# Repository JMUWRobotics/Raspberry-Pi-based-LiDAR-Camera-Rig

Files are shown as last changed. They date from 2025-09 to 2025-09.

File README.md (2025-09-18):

# Raspberry Pi–based LiDAR–Camera Rig (Livox MID-70 + Global-Shutter MonoCam)


> Handheld RGB-D scanner for outdoor/indoor scenes — developed as part of my Bachelor’s thesis at the Chair of Robotics (Informatik XVII), Julius-Maximilians-Universität Würzburg.

> The goal is a robust pipeline from ROS recording → synchronized pair export → colored point clouds & depth images → (optional) depth densification → Uni-Fusion-ready outputs.

> **Note:** An IMU is built into the device but is **not calibrated** yet and is therefore not used in the default pipeline.

<p align="center">
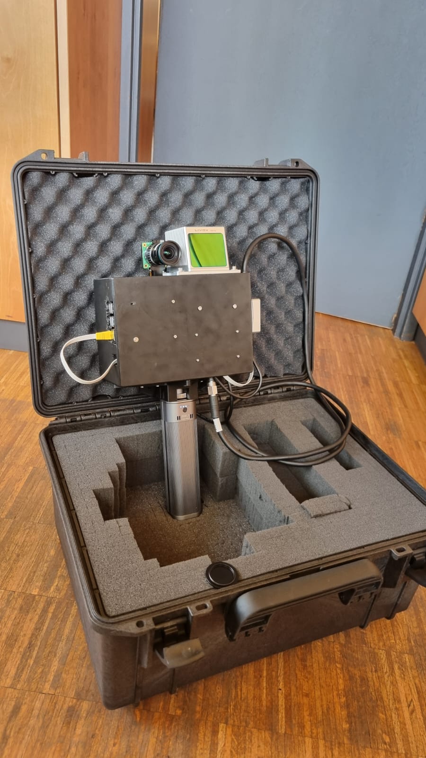
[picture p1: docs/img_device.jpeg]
  
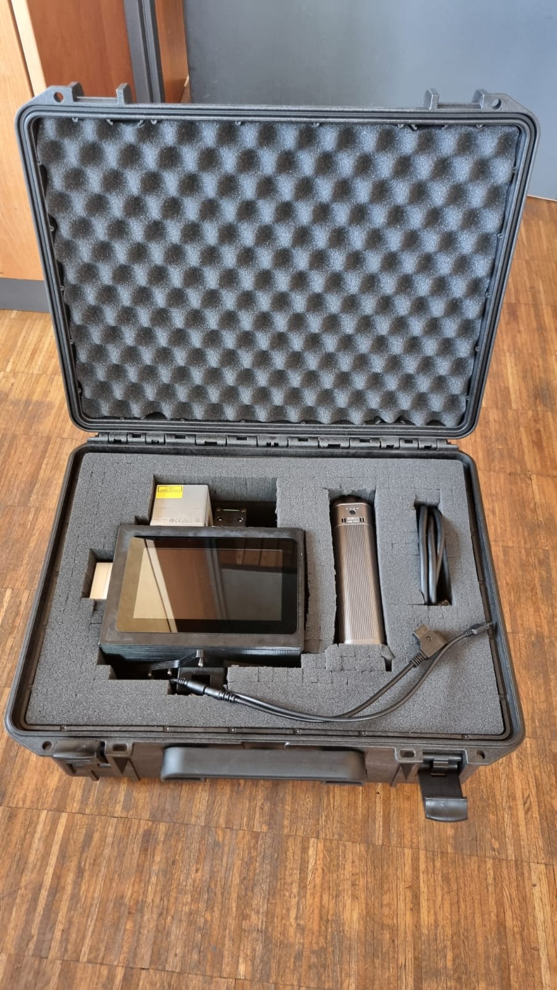
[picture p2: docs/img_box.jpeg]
  
</p>

---

## Features

- **Synchronized RGB + LiDAR pairs** from ROS bags (nearest-time matching with configurable tolerance)
- **RGB-D frames** and **colored point clouds**
- **Depth densification** (optional)
- **ICP** (merge/register multiple scans)
- **Output for Uni-Fusion**-compatible output folder structure (RGB, Depth)

---

## Hardware

- **LiDAR:** Livox MID-70
- **Camera:** Raspberry Pi Global-Shutter MonoCam and IDS-2M12-C0420, 4 mm, 1/2
- **Compute:** Raspberry Pi running **Ubuntu 24.04**
- **IMU:** BNO085, currently **uncalibrated** (not used yet)

> **Link to Fusion360 model:** https://a360.co/4mhiRDJ  
---

## System Architecture
```
Raspberry-Pi-based-LiDAR-Camera-Rig/
├── device/                                         # Ros2 Workspace on handheld device 
│   ├── src/                                        
│   │   ├── bno085                                  # IMU
│   │   ├── camera_ros                              # Raspberry Pi Camera
│   │   ├── FAST-Calib-ROS2                         # extrinsic calibration
│   │   ├── libcamera                               # driver for Pi camera
│   │   ├── livox_ros2_driver                       # driver Livox Mid-70
│   │   └── code_pkg                                # computation of rosbags
│   │          ├──       
│   │          ├──     
│   │          ├──     
│   │          └── 
│   │     
│   └── recording_scripts/                          # automatic setup and capturing of rosbags
│       ├──       
│       ├──     
│       ├──     
│       └──     
│     
├── tools/                                          # Python scripts for post-processing      
│   ├── correct_dataset.py                          # change BGR images to RGB images
│   ├── densify_depth.py                            # bilinear interpolation to fill depth image
│   ├── fuse_scans.py                               # colored pcl via icp
│   ├── generate_Fusion_Output.py                   # generate Uni-Fusion Output 
│   └── show_ply.py                                 # show pointcloud.ply
│                                         
├── stl/                                            # stl-files
│   ├── Bachelor_Device_Global_Shutter v9.f3z       # Fusion file of device
│   ├── BatteryMountingBracket.stl                  
│   ├── Body+BatteryMountingBracket.stl             
│   ├── Body.stl                                    
│   └── Front.stl                                   
│     
├── thesis/                                         # Academic thesis material  
└── README.md
```
## Software Stack & Dependencies post-processing 

- Python ≥ 3.10
- **Open3D** ≥ 0.19
- NumPy, OpenCV-Python, Pillow
- (optional) Matplotlib for visualization
---
Additional sample outputs:
- `docs/images/sample_rgb.png` — camera frame  
- `docs/images/sample_depth.png` — generated (optionally densified) depth image  
- `docs/images/sample_colored_pcd.png` — colored point cloud

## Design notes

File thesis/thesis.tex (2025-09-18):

% !TeX root = bsp.tex

% class options:
% - select either [german] or [english]
% - select the type of thesis from:
%   [bachelor, master, generic]
%   (in case of generic, use \type{} to specify it)
% - use option "alpha" for abbreviated citation (instead of numbers)
% - option "draft" is available, too
% - use options "utf8" or "latin1" to select inputencoding
\documentclass[english, bachelor, utf8]{base/thesis_telematics}

\usepackage{units}    % useful for settings units:              \unit[23]{m}
\usepackage{nicefrac} % for setting fractions esp. within text: \nicefrac{km}{h}
\usepackage{subcaption} % for subfigure environment
\usepackage[utf8]{inputenc}
\usepackage{array} % für bessere Tabellen
\usepackage{geometry}
\geometry{margin=2.5cm}

\usepackage{algorithm, algorithmic}  % for pseudo code (cf. documentation)
\renewcommand{\algorithmiccomment}[1]{\qquad{\small // \textit{#1}}}
\usepackage{tikz}
\usetikzlibrary{arrows.meta, positioning, shapes.geometric, calc}
\usepackage{pdfpages}
\usepackage{hyperref}
\usepackage{booktabs}
\usepackage[utf8]{inputenc}
\usepackage{svg}
\usepackage{subcaption}

%%%%%%%%%%%%%%%%%%%%%%%%%%%%%%%%%%%%%%%%%%%%%%%%%%%%%%%%%%%%%%%%%%%%%%%%%%%%%%%

\begin{document}

\title{Raspberry PI based Camera--LiDAR rig for colored 3D Pointclouds}
\author{Jakob Wehr}
\email{jakob.wehr@stud-mail.uni-wuerzburg.de}
\firstSupervisor{Prof. Dr. Andreas Nuechter}
\secondSupervisor{Dr. Michael Bleier}
\thirdSupervisor{}
%\thirdSupervisor{} %for to give credit to the person supervising but not reviewing the thesis 
%\dept{...}                             % by default Robotics and Telematics
%\submitdate{November 2004}             % by default current month & year
%\signcity{}                            % by default W�rzburg
%signline{W�rzburg, 1. April 2014} % by default "signcity, submitdate"

\generatetitle

\cleardoublepage

\begin{prefacesection}{Abstract}
This Bachelor's thesis presents the design and implementation of a low-cost, handheld \\RGB-D scanning device
built from widely available components -- a Raspberry Pi 5, Raspberry Pi Global shutter camera and a Livox Mid-70
LiDAR -- aimed at producing research-grade datasets for sensor-fusion experiments and Uni-Fusion pipelines
at the same research chair where this work is conducted. The system employs ROS-based recording and a
structured export that tightly couples LiDAR scans and images while ensuring cross-sensor
time synchronization via the Precision Time Protocol (PTP). The processing pipeline generates depth images
and synchronized RGB-D frames for Uni-Fusion, and provides colorized point clouds to inspect extrinsic
calibration. With a bill of materials of $\sim$EUR 1{,}500, the prototype demonstrates a genuinely low-cost
platform suitable for teaching labs and exploratory research. Experiments confirm end-to-end functionality
but also reveal remaining limitations -- most notably imperfect LiDAR-camera extrinsic calibration and an
as-yet uncalibrated external IMU -- while full Uni-Fusion evaluation remains prepared but untested due to
target-system constraints.
\end{prefacesection}

\cleardoublepage
\tableofcontents

\startTextChapters %%%%%%%%%%%%%%%%%%%%%%%%%%%%%%

\chapter{Introduction}

The rapid progress in three-dimensional (3D) sensing technologies has significantly expanded the possibilities 
for spatial data acquisition in diverse domains such as robotics, autonomous navigation, cultural heritage 
documentation and construction monitoring. A key advancement in this context has been the emergence of 
RGB-D imaging, which captures both the color (RGB) and depth (D) information of a scene in a single system. 
By combining semantic richness from visual data with the geometric accuracy of depth measurements, RGB-D 
approaches enable detailed and meaningful 3D reconstructions that are crucial for a wide range of applications.

The popularization of low-cost RGB-D devices, most prominently the Microsoft Kinect, represents a milestone 
in this development. The first generation Kinect employed a PrimeSense structured-light depth sensor, which 
allowed real-time depth estimation but was limited in outdoor environments due to sensitivity to sunlight. 
Later iterations, such as the Kinect v2 and Azure Kinect, shifted to time-of-flight (ToF) sensors, extending 
the maximum measurable range up to approximately 7.5 meters~\cite{3dpclecture}. While this marked a considerable 
improvement over structured-light solutions, the technology continued to face limitations in terms of range, 
accuracy and robustness, particularly in uncontrolled outdoor conditions where strong ambient illumination 
interferes with infrared-based measurements.

To overcome such restrictions, several alternatives have been explored in recent years. One approach relies 
on the use of multiple cameras to generate dense reconstructions through photogrammetric methods. By leveraging 
multi-view geometry and at least one RGB sensor for color encoding, photogrammetry can provide accurate depth 
over larger distances, but at the expense of high computational requirements and sensitivity to textureless 
surfaces. Another method combines RGB cameras with structured infrared patterns and inertial measurement units, 
as seen in devices such as the Intel RealSense D455. Although effective in indoor environments, these systems 
remain vulnerable to degradation in bright outdoor light. A third and increasingly promising avenue is the 
integration of RGB cameras with LiDAR sensors. LiDAR, by actively emitting laser pulses and measuring their 
returns, offers high robustness to illumination conditions and can capture accurate depth across larger ranges. 
The falling costs of compact LiDAR units have further strengthened their appeal for mobile and handheld 
applications.

The objective of this thesis is to design and implement a handheld device that employs an RGB camera in 
combination with a low-cost Livox LiDAR scanner to achieve reliable outdoor depth sensing. This system aims 
to circumvent the weaknesses of structured-light or infrared-based methods under sunlight, while leveraging 
the complementary strengths of LiDAR and RGB imaging. The handheld design not only emphasizes portability 
and ease of use, but also opens opportunities for rapid on-site 3D data acquisition without the constraints 
of bulky equipment.

Recent research has demonstrated the potential of combining LiDAR with vision sensors for dense depth map 
generation in outdoor environments. A notable contribution in this area is the work by Bleier, Yuan and 
Nüchter~\cite{bleier2024}, who introduced a handheld stereo vision and LiDAR system capable of producing dense 
RGB-D maps by applying depth map completion based on learned priors. Their system exploits stereo cameras to 
capture visual data and a low-cost automotive LiDAR to supply sparse but metrically accurate depth information. 
By applying deep learning techniques to complete the sparse LiDAR data, they were able to generate dense depth 
maps with both accuracy and efficiency, even in challenging outdoor settings. This work provides an important 
methodological reference and demonstrates that the combination of vision and LiDAR, supported by learned priors, 
can significantly enhance the quality of handheld 3D mapping systems.

Further contributions in the literature similarly explore handheld systems that fuse monocular 
vision with LiDAR, each addressing specific challenges.

One influential study by Behari et al. at CVPR 2025~\cite{behari2025blurred} introduces a handheld setup that 
combines RGB imaging with a diffuse (blurred) LiDAR sensor. While conventional sparse 
LiDARs often fail to cover the entire scene, the diffuse LiDAR emits a wide-field flash, improving 
coverage but producing ambiguous multi-return signals. To address this, the authors propose a 
Gaussian surfel-based rendering framework together with a scene-adaptive loss, 
which balances the geometric accuracy of LiDAR with the semantic richness of RGB cues. This method 
enables robust handheld 3D scanning even in challenging environments with low texture, low albedo
or limited lighting, thereby outperforming traditional sparse LiDAR approaches.

Another notable contribution is presented by Lin et al.~\cite{lin2024lidarmirror}, who focused on 
mapping specular and transparent surfaces using a consumer-grade flash LiDAR integrated 
into a handheld smartphone device. Standard LiDAR systems typically assume single-bounce 
reflections, which leads to missing data when scanning mirrors or glass. To overcome this, the 
authors introduced a reciprocal pair algorithm that explicitly detects and reconstructs 
multi-bounce returns. Their approach enables accurate, real-time handheld reconstructions of 
reflective and transparent objects, extending the applicability of low-cost LiDAR sensors.

In addition to novel sensing concepts, the Newer College Dataset by Ramezani et al.
~\cite{ramezani2019newer} provides a valuable benchmark for handheld mapping. The dataset was 
recorded with a handheld device combining a stereo-inertial camera and a multi-beam 3D LiDAR while 
walking through a university campus. By aligning this data with a survey-grade reference map, the 
authors provide centimeter-accurate 6-DoF ground truth. This resource is essential for evaluating 
the performance of handheld LiDAR--vision fusion systems and highlights the practical challenges of 
sensor alignment and outdoor robustness.

These studies emphasize three central aspects: addressing sparse LiDAR coverage through novel sensor 
designs (Behari et al.), handling challenging material properties such as reflections and 
transparency (Lin et al.) and enabling reproducible evaluation through high-quality handheld 
datasets (Ramezani et al.). Together, they strengthen the evidence for the relevance of combining 
LiDAR and monocular vision in mobile or handheld 3D reconstruction systems.

Against this backdrop, the present thesis contributes to the field by developing a prototype low-cost handheld device 
that integrates a Livox LiDAR scanner with an RGB camera. The design encompasses both the hardware construction 
and the software implementation required for sensor synchronization, calibration and generating RGB-D frames
as input to the Uni-Fusion framework proposed by Yuan et al.~\cite{yuan2024uni}.

\section*{Task definition}
This thesis focuses on the design and implementation of a low-cost, handheld RGB-D scanning device using
widely available components, specifically a Raspberry Pi~5 (16GB) as the processing platform, a Raspberry Pi camera
module for RGB image capture and a Livox Mid-70 LiDAR scanner for depth acquisition. The primary goal is to
develop a portable system capable of producing RGB-D datasets suitable for sensor fusion experiments -- particularly Uni--Fusion -- without relying on expensive commercial solutions.

The research addresses the complete pipeline: from hardware integration and calibration of the monocular
camera--LiDAR system, through data acquisition, to post-processing and alignment of RGB
and depth streams. Special attention is given to cost-efficiency, portability, and the reproducibility of the system
design, so that it can be easily replicated and is also affordable for amateurs.

In summary, the aim of this work is to:
\begin{itemize}
    \item Design and build a handheld, low-cost RGB-D device using a Raspberry Pi~5, monocular camera and
    Livox Mid-70 LiDAR scanner.
    \item Implement a calibration and synchronization method for accurate data acquisition.
    \item Designing a system that can process the recorded data and create dense depth images.
    \item Creating output that can be processed by Uni-Fusion.
    \item Demonstrate that the system fulfills its purpose and that Uni-Fusion can process the generated RGB-D files.
\end{itemize}

By achieving these objectives, this work should make it easier for tech enthusiasts to get started with handheld devices, LiDAR scanners
and processing RBG-D data, thanks to the low price of the complete system.

\chapter{State of the Art}

\section*{Handheld stereo vision and LiDAR system (University Wuerzburg Computer Science XVII)}
Bleier et al.~\cite{bleier2024} present a custom-built handheld mapping system designed to 
capture dense RGB-D data in outdoor environments using low-cost sensors. The hardware integrates 
a stereo camera pair and a low-cost automotive LiDAR (specifically, a Livox Avia sensor) mounted on a 
commercial camera rig (e.g., NEEWER CA016 Cage, Figure~\ref{fig:bleier_handheld_design}). The system 
also houses embedded electronics including a single-board computer, power management, cooling 
elements, and features a handle and Wi-Fi antenna for operation and data transfer.

The core innovation resides in combining sparse LiDAR measurements with monocular RGB-based depth 
estimation to generate dense, metrically accurate RGB-D frames with low latency. To that end, they 
employ a modern monocular depth estimator (Metric3Dv2, Hu et al., 2024) and subsequently apply learned 
scale correction using sparse LiDAR returns as ground truth priors. This enables the generation of 
dense depth maps from just one sparse scan and a single image, circumventing the need for multi-view 
bundle adjustment or LiDAR scan aggregation.

For validation, the authors compare the learning-based depth completion to traditional LiDAR-only 
mapping via scan matching. While the baseline model-based regression performs worse in their experiments, 
it still achieves dense RGB-D outputs from minimal sensor input with significantly lower latency, 
demonstrating potential for real-time outdoor RGB-D capture using cost-effective hardware.

\begin{figure}[htbp]
    \centering
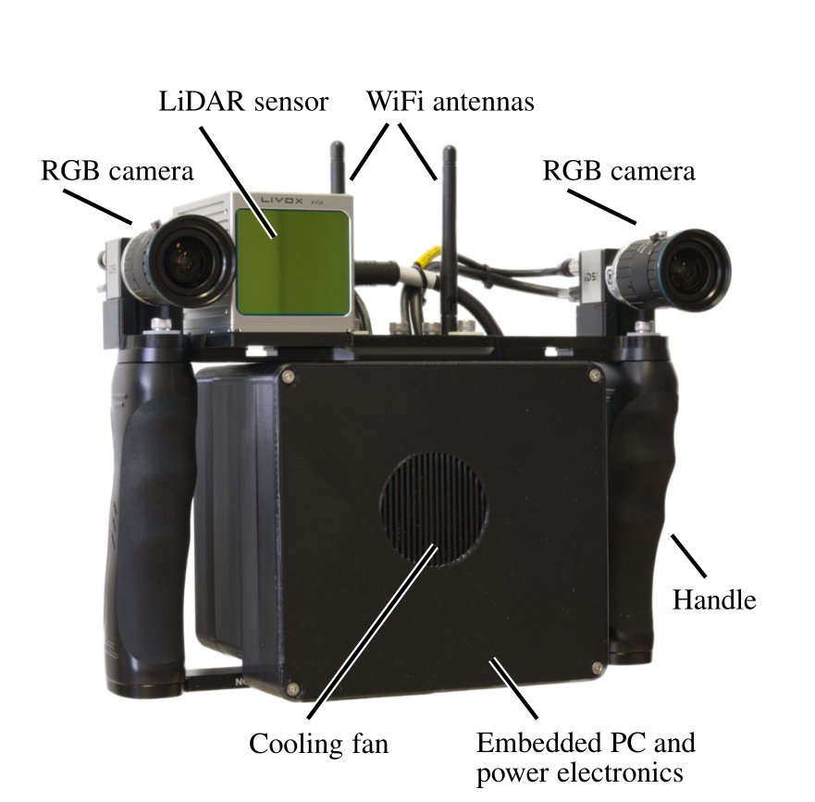
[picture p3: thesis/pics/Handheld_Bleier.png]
    
    \caption{Handheld stereo vision--LiDAR mapping system featuring stereo cameras, 
    Livox Avia LiDAR, embedded PC, handle and Wi-Fi antenna on a commercial cage rig by Bleier et al.~\cite{bleier2024}}
    \label{fig:bleier_handheld_design}
\end{figure}

\chapter{Theoretical Background}

\section{LiDAR Scanning}
Lidar (Light Detection and Ranging) is a remote sensing technology that measures distances by emitting laser
pulses and recording the time it takes for the reflected signal to return. This time-of-flight measurement
allows precise determination of the distance to an object. Compared to radar, Lidar uses shorter wavelengths,
which makes it more effective for detecting smaller targets. By scanning surfaces, Lidar can also determine
the shape and size of objects, making it highly suitable for terrain modeling and object recognition.
\subsection*{Differential Absorption Lidar (DIAL)}
Differential Absorption Lidar (DIAL) measures atmospheric properties such as temperature, density and
pressure of trace gases and aerosols. It uses two laser beams: one with a wavelength corresponding to the
absorption peak of the target gas (on-line) and another between absorption features (off-line). The ratio
of the returned on-line and off-line signals provides information about the absorption characteristics of
the target gas.
\subsection*{Doppler LiDAR}
Doppler Lidar measures the velocity of targets using the Doppler shift of the reflected light. By mixing
the return signal with a reference laser of known frequency (heterodyne detection), the Doppler frequency
shift can be determined. Applications include wind speed and direction measurements, detection of turbulence
and wake vortices near airports, monitoring local winds during rocket or shuttle launches and providing
data for accurate weather prediction models.

\subsection*{Distance Measurement}
The distance measurement in Lidar follows \( d = \frac{c \cdot t}{2} \), where \(c\) is the speed of light
in vacuum (approximately 299,792,458 m/s) and \(t\) is the pulse time-of-flight. Achieving a resolution of
10 mm requires timing precision on the order of picoseconds (\(10^{-12}\) s). Unlike radar, which emits
diverging signals, Lidar beams are focused. This ensures high accuracy but makes the system sensitive to
fog, rain, wind and reflective or transparent surfaces such as glass or water.

Laser scanners produce raw data that depend on angular resolution (typically 0.25°–1°) and field of view
(commonly 180°, some sensors up to 360°). Raw data generally consist of angle and distance measurements,
optionally including reflectance or intensity. These polar coordinates can be converted to Cartesian
coordinates for further processing and analysis.~\cite{michaelbleier_slides}

\section{PLA -- polylactic acid}
\label{sec:PLA}

PLA, alongside ABS, is one of the most commonly used materials in FDM printers. 
These polylactides are synthetic polymers that belong to the polyester family and are made up of many chemically bonded 
lactic acid molecules. PLA is made from renewable raw materials such as corn starch and is industrially compostable. 

PLA is the material of choice, especially for beginners in 3D printing, as it is forgiving of many printing errors 
and has many other advantages. For example, it can be easily processed by any standard 3D printer, has a low melting 
point and exhibits minimal warping during printing. Furthermore, it is colorfast and scratch-resistant and, unlike ABS, 
produces little odor during processing.~\cite{material4print2024pla}

%\section{\textcolor{red}{IMU -- Inertial Measurment Unit}}

\section{Intrinsic Camera Calibration}
The characteristics of a camera can basically be divided into intrinsic and extrinsic parameters.
Intrinsic calibration captures the camera's internal physical characteristics, such as focal length,
 optical axis, and lens distortion.
Extrinsic calibration, on the other hand, determines the spatial position and orientation of the camera 
relative to a defined world coordinate system.

Intrinsic camera calibration aims to estimate the internal parameters of a camera that model the image 
formation process and lens distortions. According to Fusiello~\cite{Fusiello2024}, this includes focal 
lengths, the principal point and parameters describing lens-induced distortions.

\subsection*{Camera Model}
In the pinhole camera model, a 3D point $\mathbf{X} = [X, Y, Z]^\top$ is projected onto the image 
plane as:
\[
s \begin{bmatrix} u \\ v \\ 1 \end{bmatrix}
= \mathbf{K} \, [\mathbf{I} \mid \mathbf{0}] \,
\begin{bmatrix} X \\ Y \\ Z \\ 1 \end{bmatrix}.
\]
The intrinsic matrix $\mathbf{K}$ is defined as:
\[
\mathbf{K} = 
\begin{bmatrix}
f_x & s & c_x \\
0 & f_y & c_y \\
0 & 0 & 1
\end{bmatrix},
\]
where $f_x$ and $f_y$ are the focal lengths in pixels, $(c_x, c_y)$ is the principal point, and 
$s$ is the skew factor, often assumed to be zero in most practical systems.

\subsection*{Distortion Model}
Real lenses introduce \emph{radial} and \emph{tangential} distortions. A common distortion model with 
radial coefficients $k_1, k_2, k_3$ and tangential coefficients $p_1, p_2$ is:
\[
r^2 = x^2 + y^2,
\]
\[
x_{\mathrm{dist}} = x \left( 1 + k_1 r^2 + k_2 r^4 + k_3 r^6 \right) + 2 p_1 x y + p_2 (r^2 + 2 x^2),
\]
\[
y_{\mathrm{dist}} = y \left( 1 + k_1 r^2 + k_2 r^4 + k_3 r^6 \right) + p_1 (r^2 + 2 y^2) + 2 p_2 x y.
\]
The distorted normalized coordinates $(x_{\mathrm{dist}}, y_{\mathrm{dist}})$ are then mapped to pixel 
coordinates using $\mathbf{K}$.

\subsection*{Calibration Workflow}
Fusiello describes a typical calibration pipeline as follows:
\begin{enumerate}
    \item Capture multiple images (10--20) of a planar calibration target (e.g., checkerboard) from 
          different positions and orientations.
    \item Detect known 2D feature points in the images and associate them with their known 3D coordinates 
          in the target's frame.
    \item Compute an initial estimate of the intrinsic parameters using linear methods (e.g., via 
          homography decomposition).
    \item Refine all intrinsic parameters and distortion coefficients by nonlinear optimization (e.g., 
          Levenberg--Marquardt) to minimize the reprojection error.
\end{enumerate}

\begin{figure}[ht!]
    \centering
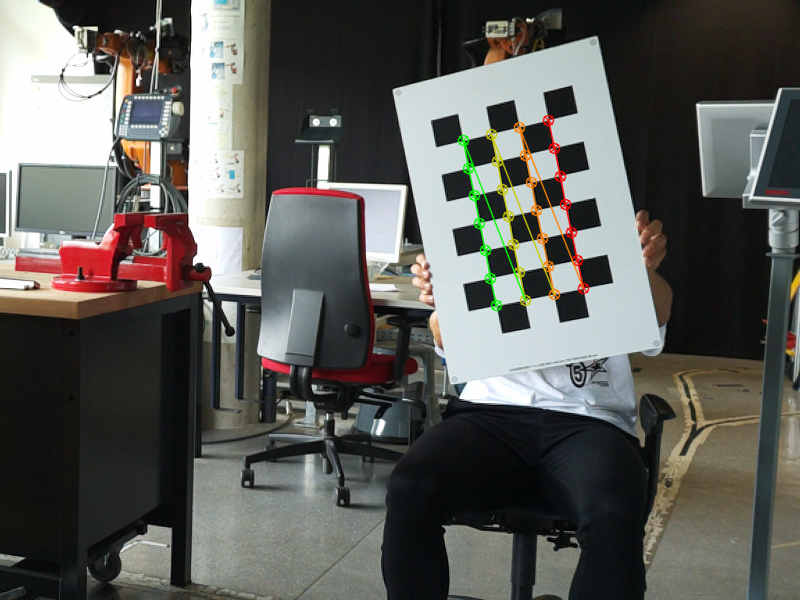
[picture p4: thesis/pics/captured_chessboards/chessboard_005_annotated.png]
    
    \caption{Example calibration pattern with found corners}
    \label{fig:pattern}   
\end{figure}

%\paragraph{Summary}
%Intrinsic calibration is a fundamental prerequisite for accurate 3D reconstruction and multi-sensor 
%fusion. By estimating the true internal parameters of the camera and compensating for lens distortions, 
%it ensures that image measurements correspond correctly to geometric rays in 3D space.

\section{Extrinsic Calibration of LiDAR and Camera}
\label{sec:extrinsic_calib}

In multi-sensor perception systems that combine LiDAR and camera data, the accurate estimation of the spatial 
relationship between the two sensors is fundamental for enabling sensor fusion. This relationship is described 
by a rigid-body transformation that maps coordinates from the LiDAR reference frame into the camera reference frame. 
If this transformation is incorrect, the projected LiDAR points will not align with the corresponding image features, 
leading to degraded performance in tasks such as 3D reconstruction, object detection or semantic segmentation. 
Extrinsic calibration aims to estimate this transformation with high precision. The approach described in~\cite{beltran2022automatic} 
achieves this in a fully automated manner, without the need for dedicated calibration targets, making it applicable in a wide variety 
of real-world scenarios.

Formally, let $\mathcal{L}$ denote the LiDAR coordinate frame and $\mathcal{C}$ the camera coordinate frame. 
The calibration problem consists of finding the homogeneous transformation matrix $\mathbf{T}_{\mathcal{CL}} \in SE(3)$ that maps a 
point $\mathbf{p}_L$ expressed in LiDAR coordinates to its representation $\mathbf{p}_C$ in the camera coordinate system:
\begin{equation}
\mathbf{p}_C =
\mathbf{T}_{\mathcal{CL}} \, \mathbf{p}_L
= \begin{bmatrix} \mathbf{R} & \mathbf{t} \\ \mathbf{0}^\top & 1 \end{bmatrix} \mathbf{p}_L,
\label{eq:extrinsic_transformation}
\end{equation}
where $\mathbf{R} \in SO(3)$ is a rotation matrix and $\mathbf{t} \in \mathbb{R}^3$ is a translation vector. 
This transformation describes both the orientation and the position of the LiDAR relative to the camera. 
The points $\mathbf{p}_L$ are represented in homogeneous coordinates, enabling both rotation and translation to be applied in a single 
matrix multiplication.

Once a LiDAR point has been transformed into the camera coordinate frame, it is projected into the image plane using the calibrated pinhole camera model. 
This projection is given by:
\begin{equation}
\mathbf{u} \sim \mathbf{K} \, [\mathbf{R} \;|\; \mathbf{t}] \, \mathbf{p}_L,
\label{eq:projection}
\end{equation}
where $\mathbf{K}$ is the intrinsic camera matrix containing focal lengths, the principal point, and skew parameters, and $\mathbf{u} = [u, v, 1]^\top$ are 
the homogeneous image coordinates. The operator $\sim$ indicates equality up to a scale factor due to the use of homogeneous coordinates. Accurate knowledge 
of $\mathbf{K}$ is assumed, as intrinsic calibration is typically performed separately beforehand.

The extrinsic calibration problem can then be formulated as an optimization that minimizes the discrepancy between the observed image features and the 
projections of the corresponding LiDAR points. This is expressed as the minimization of the total reprojection error:
\begin{equation}
E(\mathbf{R}, \mathbf{t}) =
\sum_{i=1}^N \left\| \mathbf{u}_i -
\pi\left( \mathbf{R} \mathbf{p}_{L,i} + \mathbf{t} \right) \right\|^2,
\label{eq:reprojection_error}
\end{equation}
where $\pi(\cdot)$ is the projection function defined in Equation~\ref{eq:projection}, $\mathbf{u}_i$ are observed feature points in the image, and $\mathbf{p}_{L,i}$ 
are the corresponding 3D points from the LiDAR point cloud. The summation is performed over $N$ matched feature correspondences. By minimizing $E$, the algorithm ensures 
that the transformed and projected LiDAR points align as closely as possible with the observed image features.

The automated calibration procedure proceeds through several interconnected stages, each of which plays a crucial role in the accuracy and robustness of the final result. 
The first stage consists of data acquisition. The system records synchronized LiDAR point clouds and camera images from a variety of viewpoints within the target environment. 
Multiple poses and viewing angles are necessary to provide the optimization with a rich set of correspondences and to reduce
degeneracy in the solution, particularly in geometrically uniform scenes.
The second stage is feature extraction. In the image domain, this often involves detecting salient structures such as edges, corners or line segments that are stable 
under viewpoint changes and can be reliably localized. In the LiDAR domain, geometric primitives such as planes, sharp edges or high-intensity reflectors are extracted 
from the 3D point cloud. These features should ideally correspond to physical elements in the scene that are visible to both sensors, such as building edges, traffic signs
or corners of large objects.

The third stage is feature association. This is a challenging problem because LiDAR and camera sensors capture different modalities: LiDAR measures geometry and sometimes 
reflectivity, while cameras measure color and intensity. To establish correspondences, the algorithm projects candidate LiDAR features into the image using a tentative 
transformation and searches for spatially consistent matches with the extracted image features. Similarity measures can be based on geometric alignment, intensity patterns 
or mutual visibility constraints. At this point, only approximate correspondences are needed, as they will be refined later.

Once a sufficient set of correspondences is established, the fourth stage computes an initial estimate of the transformation $\mathbf{T}_{\mathcal{CL}}$. 
If direct 3D -- 3D correspondences between LiDAR and camera coordinate frames are available -- such as from triangulated stereo image points -- this estimate can be obtained in 
closed form using the Kabsch algorithm, which minimizes the root-mean-square distance between matched point sets. If only 3D–2D correspondences are available, 
a Perspective-n-Point (PnP) algorithm can be employed to obtain an initial rotation and translation.

The fifth stage refines the transformation through nonlinear optimization. Here, the initial $(\mathbf{R}, \mathbf{t})$ is used as a starting point for minimizing the 
reprojection error defined in Equation~\ref{eq:reprojection_error}. The optimization is typically carried out using the Levenberg–Marquardt algorithm, which is well 
suited for nonlinear least-squares problems. Robust loss functions, such as the Huber or Cauchy loss, are integrated into the cost function to reduce the influence of 
outlier correspondences that could arise from incorrect feature matches or transient objects in the scene.

Finally, the sixth stage is validation. The estimated transformation is applied to the LiDAR point cloud, and the points are projected into the corresponding camera image. 
Visual inspection can reveal any systematic misalignment, while quantitative measures such as the mean or median reprojection error provide objective performance metrics. 
Figures~\ref{fig:steps}, \ref{fig:detect_extrinsic_calib} and \ref{fig:reprojection} illustrate the calibration pipeline, the involved coordinate frames and an example of a calibrated projection.

This fully automated pipeline offers several advantages. By eliminating the need for artificial calibration targets, it can be executed in natural, dynamic environments 
without disrupting regular operation. Its reliance on common scene features rather than engineered markers makes it flexible across domains, from autonomous driving and 
mobile robotics to large-scale 3D mapping. At the same time, the combination of an initial analytical estimate with a robust nonlinear refinement ensures both convergence 
reliability and high final accuracy.

\begin{figure}[htbp]
    \centering
    % Erste Reihe
    \begin{subfigure}[b]{0.45\textwidth}
        \centering
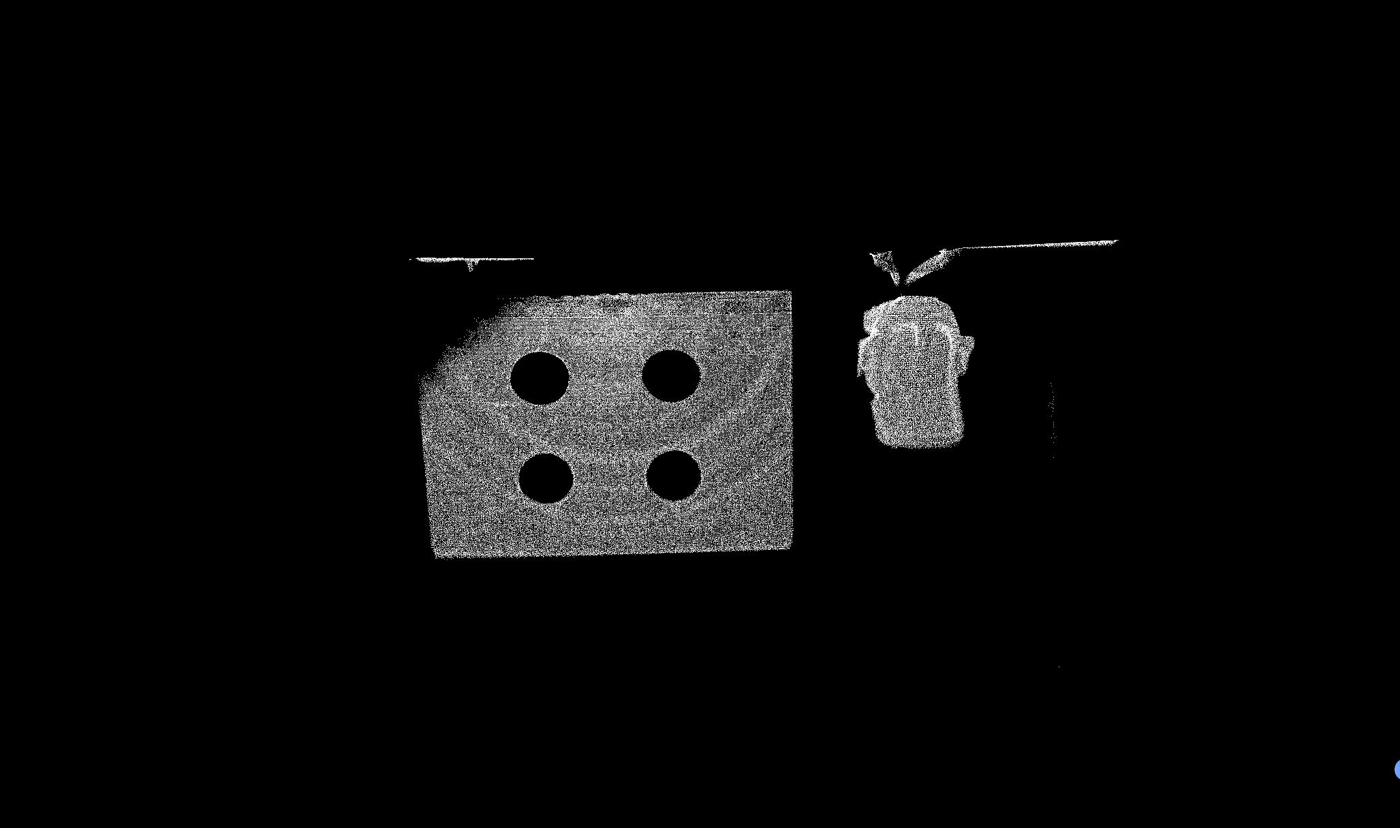
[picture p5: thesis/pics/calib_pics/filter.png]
        
        \caption{Step 1: Distance Filtering}
    \end{subfigure}
    \hfill
    \begin{subfigure}[b]{0.45\textwidth}
        \centering
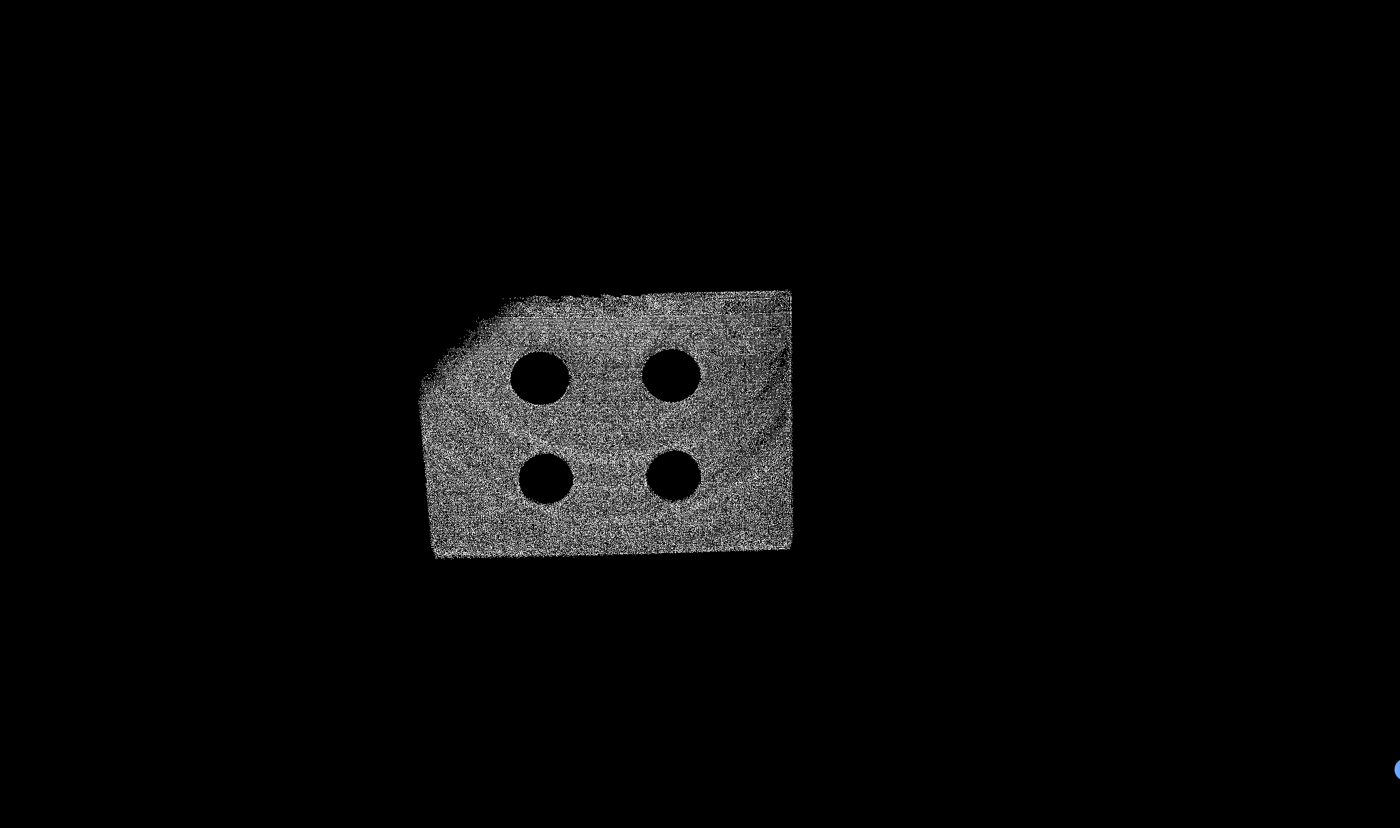
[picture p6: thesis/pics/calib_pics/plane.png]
        
        \caption{Step 2: Plane Segmentation}
    \end{subfigure}

    % Zweite Reihe
    \begin{subfigure}[b]{0.45\textwidth}
        \centering
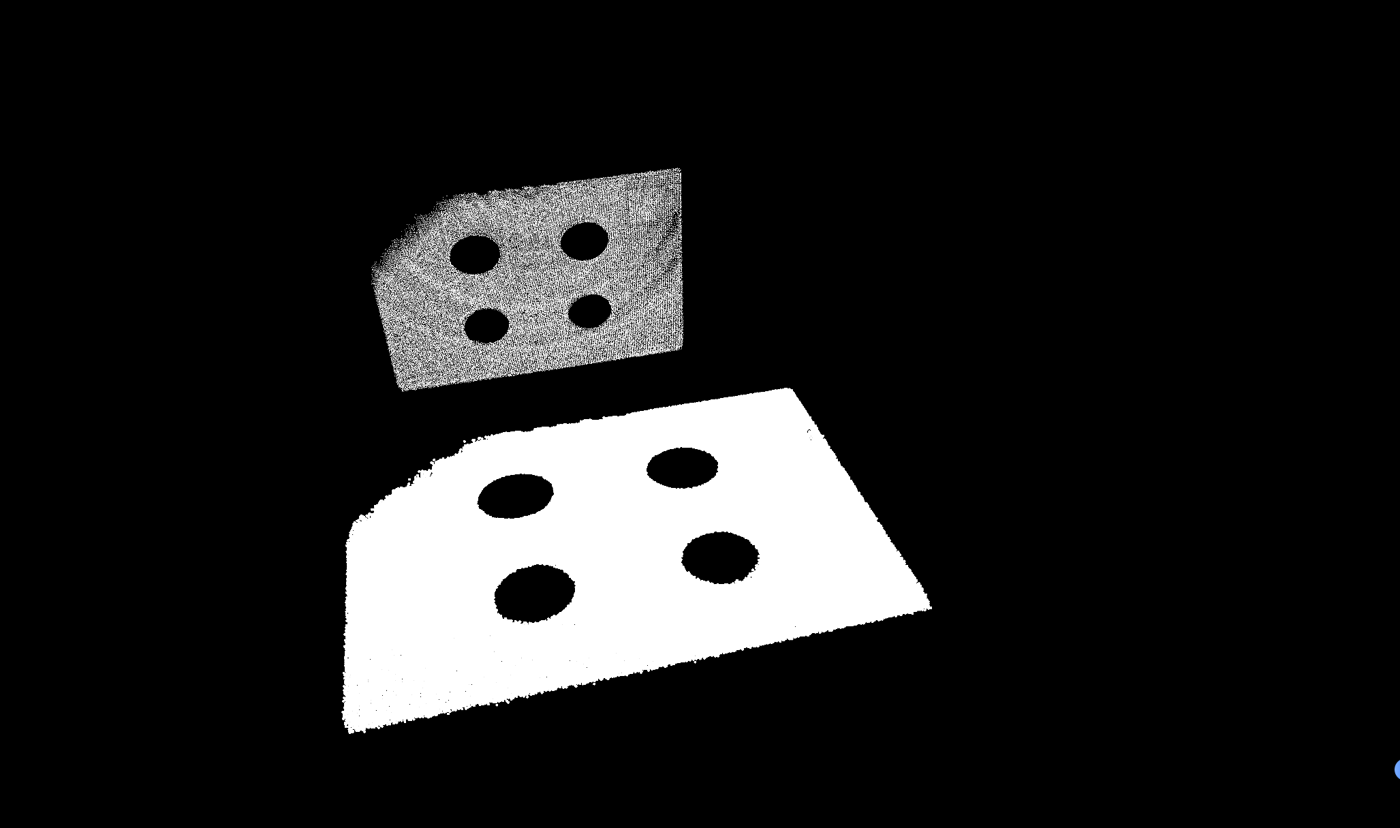
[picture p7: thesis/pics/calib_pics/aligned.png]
        
        \caption{Step 3: Plane Alignment to 2D}
    \end{subfigure}
    \hfill
    \begin{subfigure}[b]{0.45\textwidth}
        \centering
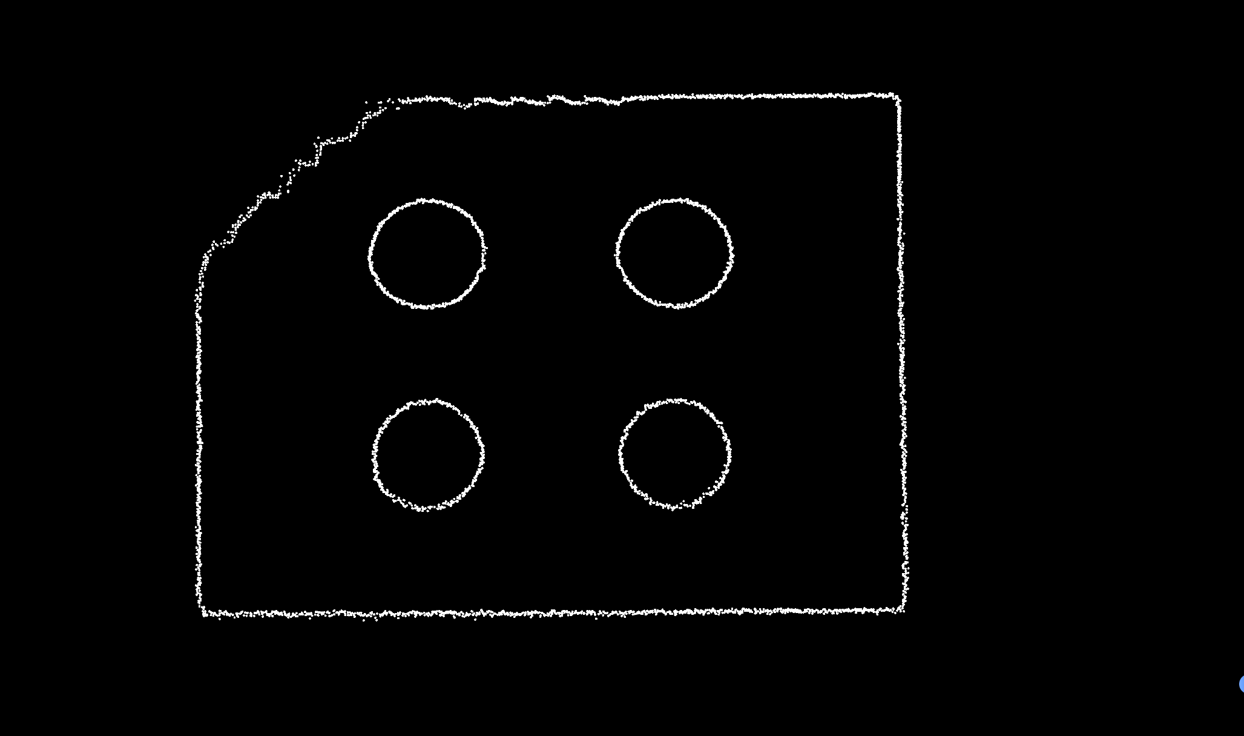
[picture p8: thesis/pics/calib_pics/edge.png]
        
        \caption{Step 4: Boundary Point Detection}
    \end{subfigure}

    % Dritte Reihe
    \begin{subfigure}[b]{0.45\textwidth}
        \centering
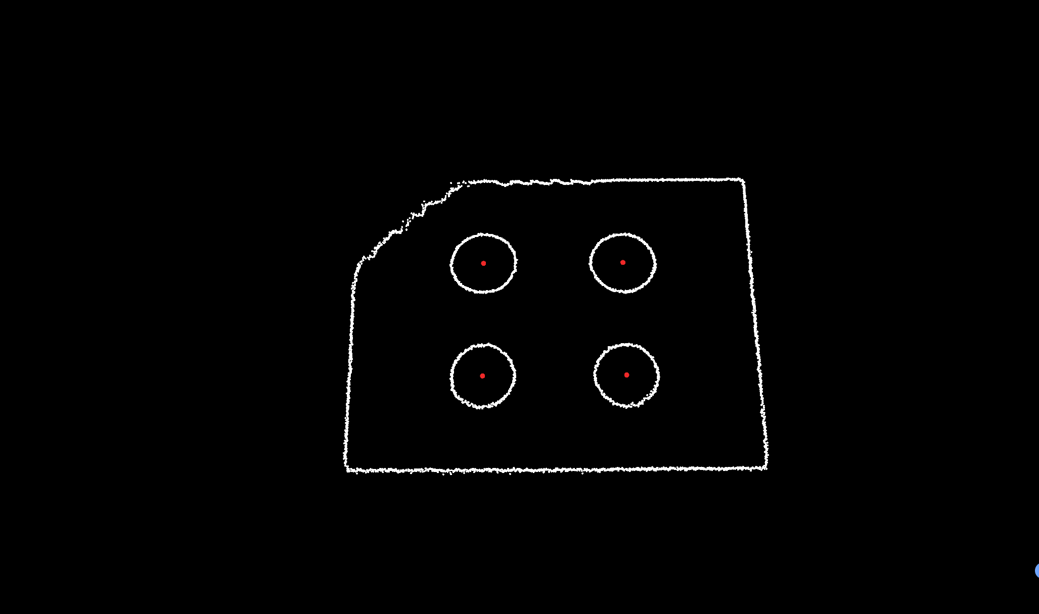
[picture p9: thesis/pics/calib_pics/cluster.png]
        
        \caption{Step 5: Clustering and Circle Fitting}
    \end{subfigure}
    \hfill
    \begin{subfigure}[b]{0.45\textwidth}
        \centering
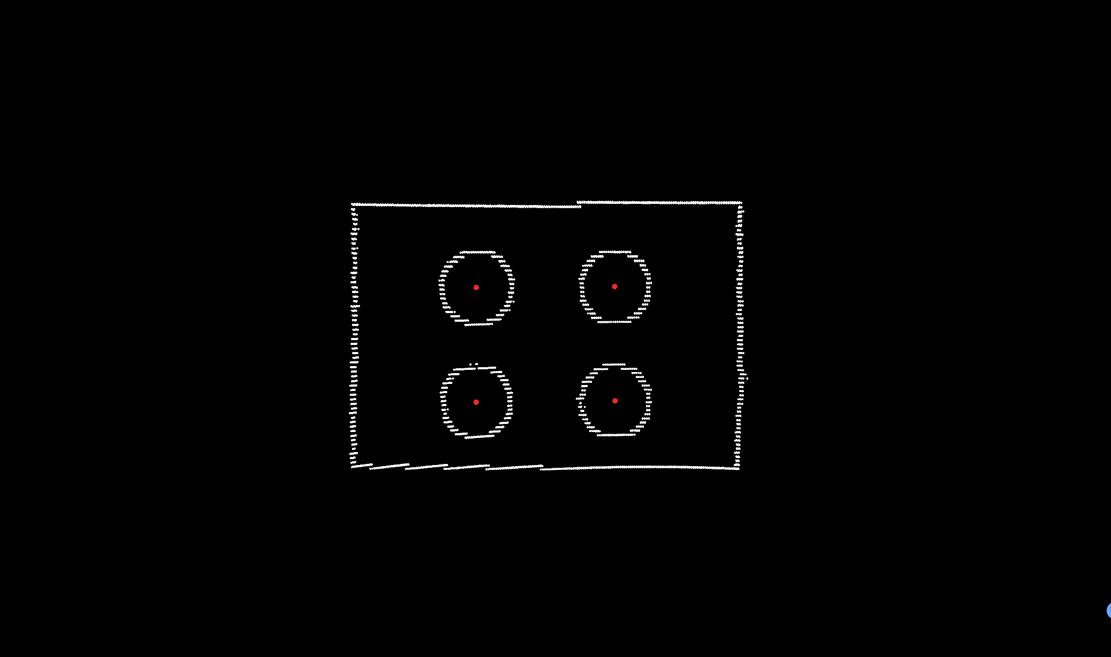
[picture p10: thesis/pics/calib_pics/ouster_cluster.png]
        
        \caption{Step 6: Performance of LiDAR}
    \end{subfigure}

    \caption{LiDAR--camera extrinsic calibration pipeline\cite{FASTCalibROS2}}
    \label{fig:steps}
\end{figure}

\begin{figure}[ht!]
    \centering
    %coordinate_frames.png
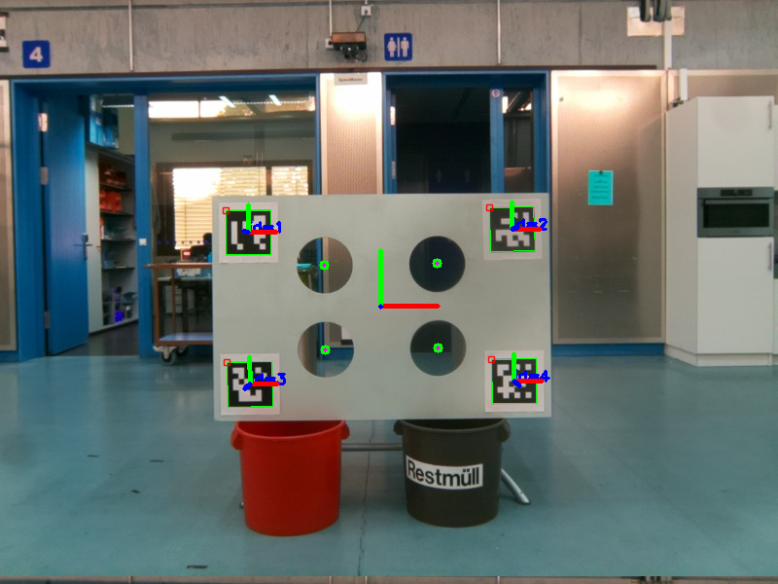
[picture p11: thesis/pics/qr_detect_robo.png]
    
    \caption{Detected calibration pattern}
    \label{fig:detect_extrinsic_calib}
\end{figure}

\begin{figure}[ht!]
    \centering
    %reprojection_example.png
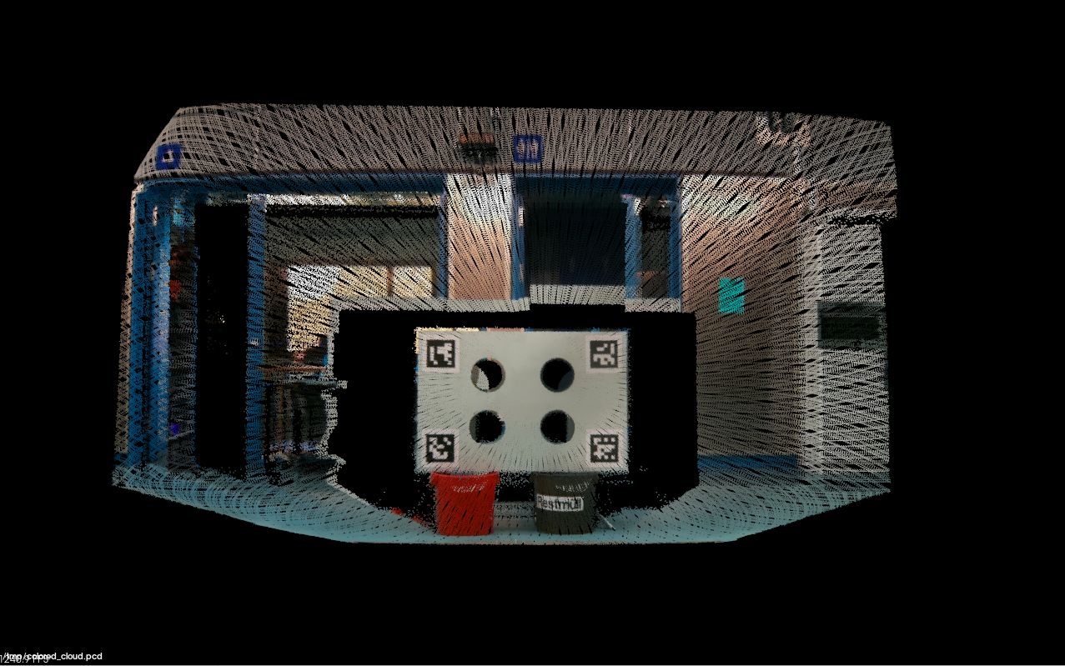
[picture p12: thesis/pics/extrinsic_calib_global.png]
    
    \caption{Colored pointcloud of FastCalib}
    \label{fig:reprojection}
\end{figure}

\section{Synchronize timestamps}
\label{sec:PTP}
In order to correlate the different sensor data from LiDAR, camera and IMU,
i.e., which scan matches which image and what the position was at that time,
we need to synchronize the sensor systems in terms of time.
We use PTP to enable this time synchronization.

The Precision Time Protocol (PTP) according to IEEE~1588 is used for high-precision
synchronization of clocks in distributed systems via packet-based
networks. The architecture is hierarchical and based on
the selection of a \emph{Grandmaster Clock} as a reference clock, whose
time base is adopted by all other participants (\emph{Slaves}).
The grandmaster is determined using the \emph{Best Master
Clock Algorithm} (BMCA), which is based on defined quality parameters of the
respective clocks.
We designate the Raspberry PI as our grandmaster and the connected 
sensors -- LiDAR, camera, and IMU -- as slaves.~\cite{eidson2002ieee}

Synchronization is achieved by exchanging defined messages.
The master sends a
\texttt{Sync} message with a high-resolution timestamp $T_1$ at regular intervals. The
slave records the time of receipt as $T_2$. To determine the
transmission delay, the slave sends a
\texttt{Delay\_Req} message, whose transmission time $T_3$ it records itself.
The master records the time of receipt as $T_4$ and transmits
this in a \texttt{Delay\_Resp} message to the slave.~\cite{wikipediaPTP}

The transmission delay
(one-way delay) is first calculated from the four timestamps:
\[
\text{Delay} = \frac{(T_2 - T_1) + (T_4 - T_3)}{2}
\]
The time offset between the slave and master clocks is calculated as follows:
\[
\text{Offset} = \frac{(T_2 - T_1) - (T_4 - T_3)}{2}
\]
By correcting for the calculated offset, the slave clock can be set precisely to
the time of the master.~\cite{hpePTP}
Accuracy is significantly influenced by the recording of time stamps. 
With software timestamping, this is done at the
protocol level, which can lead to higher jitter values. The
hardware timestamping that we use in our case sets time stamps 
directly in the network interface (MAC/PHY) and enables accuracies in the 
sub-microsecond to nanosecond range.~\cite{wikipediaPTP}

In more complex networks boundary clocks and
transparent clocks are used. Boundary clocks synchronize
with the grandmaster and pass the time on to downstream segments.
 Transparent clocks measure the propagation delay within
a device and include this information in PTP messages to
compensate for runtime errors.~\cite{eidson2002ieee}

The precision depends on the stability of the grandmaster clock, the
symmetry of the transmission paths, the buffer architecture in intermediate nodes
and the accuracy of the time stamping. Under optimal conditions,
 hardware timestamping can achieve accuracies in the nanosecond range.~\cite{hpePTP}

Since in our setup (\ref{fig:Master_Slave}) only the laser scanner is connected to the Pi via Ethernet
and the camera and IMU are connected directly to the Pi via CSI and I2C, respectively,
and therefore already run under Raspberry--Pi Time, we only need to synchronize the Livox.
This is the case because the Livox Mid-70 produces its own timestamps by default, 
which simply indicate the time that has elapsed since the start
of the laser scanner.

To solve the synchronization task, we use PTP daemon (PTPd).

\begin{figure}[h!]
    \centering
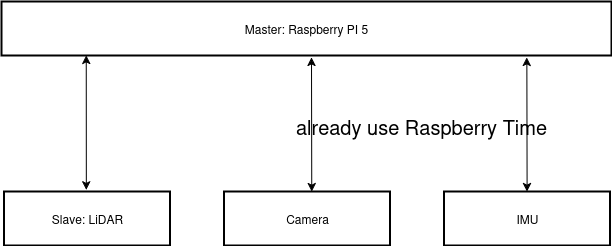
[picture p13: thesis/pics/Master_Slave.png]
    
    \caption{Time synchronization pipeline}
    \label{fig:PTP}
\end{figure}

\begin{figure}[h!]
    \centering
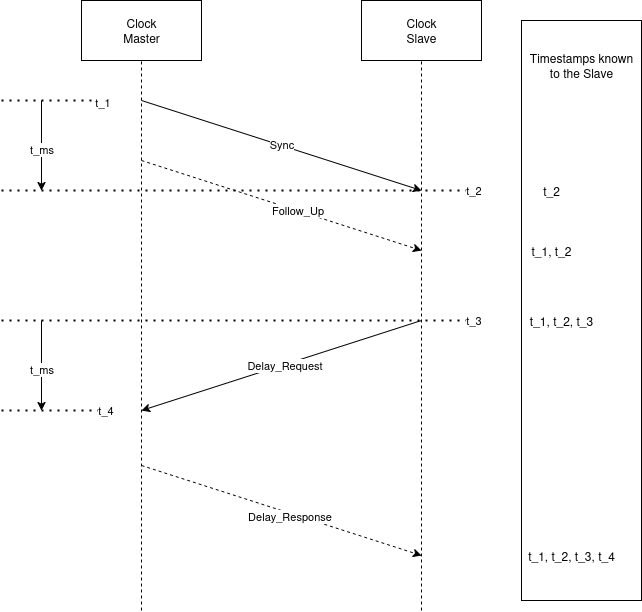
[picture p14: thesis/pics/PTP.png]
    
    \caption{PTP synchronization between slave and master\cite{wikipediaPTP}}
    \label{fig:Master_Slave}
\end{figure}

\section{Projection from LiDAR to Image space}
\label{sec:proj_lidar_image}
The projection of LiDAR points into an image frame is a fundamental step for multi-sensor fusion. 
Given a point $\mathbf{P}_L = [X_L, Y_L, Z_L, 1]^\top$ expressed in the LiDAR coordinate system, 
the transformation into the camera coordinate system is defined by a rigid-body motion:
\[
  \mathbf{P}_C = \mathbf{R}\,\mathbf{P}_L + \mathbf{t},
\]
where $\mathbf{R} \in SO(3)$ is the rotation matrix describing the orientation of the LiDAR relative 
to the camera, and $\mathbf{t} \in \mathbb{R}^3$ is the translation vector. Together they form the 
extrinsic calibration parameters, which encode the spatial relationship between both sensors 
\cite{mishra2020extrinsic}.

Once the 3D point is represented in the camera frame $\mathbf{P}_C = [X_C, Y_C, Z_C]^\top$, it can 
be mapped into the 2D image plane using the pinhole camera model:
\[
  \lambda
  \begin{bmatrix}
  u \\ v \\ 1
  \end{bmatrix}
  =
  \mathbf{K}
  \begin{bmatrix}
  X_C \\ Y_C \\ Z_C
  \end{bmatrix},
\]
with $\mathbf{K}$ denoting the intrinsic matrix and $(u,v)$ representing the pixel coordinates. 
Here $\lambda$ corresponds to the projective depth $Z_C$, ensuring that the normalized coordinates 
are obtained as
\[
  u = \frac{f_x X_C}{Z_C} + c_x, \quad v = \frac{f_y Y_C}{Z_C} + c_y,
\]
where $(f_x,f_y)$ denote the focal lengths in pixel units and $(c_x,c_y)$ are the principal point 
coordinates \cite{review2024lidarcamera}.

In practice, only points with $Z_C > 0$ are retained, since negative depths correspond to locations 
behind the camera plane. Furthermore, projected coordinates must lie within the valid image bounds, 
otherwise they are discarded. This ensures that the resulting projection covers only the visible 
region of the image and allows one to verify whether the LiDAR field of view fully overlaps with the 
camera’s image space. The described implementation corresponds directly to the function 
\texttt{project\_lidar\_on\_image}, which applies the extrinsic transformation, projects the points 
through the intrinsic matrix and renders them as overlay positions on the RGB image.

%\begin{figure}[H]
%    \centering
%    \includegraphics[width=0.7\textwidth]{Platzhalter.jpg}
%    \caption{LiDAR point cloud in 3D space.}
%    \label{fig:lidar_3d_cloud}
%\end{figure}

%\begin{figure}[H]
%    \centering
%    \includegraphics[width=0.7\textwidth]{Platzhalter.jpg}
%    \caption{Projection of LiDAR points into the 2D image plane.}
%    \label{fig:lidar_projection}
%\end{figure}

%\begin{figure}[H]
%    \centering
%    \includegraphics[width=0.7\textwidth]{Platzhalter.jpg}
%    \caption{Overlay of projected LiDAR points on the RGB frame.}
%    \label{fig:lidar_overlay}
%\end{figure}

\section{ICP -- Iterative Closest Point}
The Iterative Closest Point (ICP) algorithm is a widely used technique in computer vision and robotics for rigidly 
aligning two 3D point clouds, typically denoted as a source point set $\mathcal{P} = \{p_i\}_{i=1}^N$ and a target point 
set $\mathcal{Q} = \{q_j\}_{j=1}^M$~\cite{Zhang2016}. The fundamental objective of ICP is to find the optimal rigid 
transformation, consisting of a rotation matrix $R \in SO(3)$ and a translation vector $t \in \mathbb{R}^3$, that minimizes 
the distance between corresponding points in the two sets. Formally, the error metric commonly minimized is the mean 
squared distance:

\[
E(R, t) = \frac{1}{N} \sum_{i=1}^{N} \| R p_i + t - q_{\sigma(i)} \|^2,
\]
where $\sigma(i)$ denotes the index of the closest point in $\mathcal{Q}$ corresponding to $p_i$ in $\mathcal{P}$. The ICP 
algorithm proceeds iteratively, typically following two main steps:

1. **Correspondence Assignment**: For each point $p_i$ in the source set $\mathcal{P}$, the closest point $q_{\sigma(i)}$ 
in the target set $\mathcal{Q}$ is determined, often using Euclidean distance. This step establishes a provisional mapping 
between the point sets.

2. **Transformation Estimation**: Given the correspondences, the optimal rigid transformation $(R^*, t^*)$ is computed by 
minimizing the objective function $E(R, t)$. Closed-form solutions exist for this step, for example using singular value 
decomposition (SVD) of the covariance matrix between the corresponding points.

These steps are repeated iteratively: after applying the computed transformation to the source points, correspondences are 
re-evaluated and a new transformation is estimated. The iteration continues until convergence, which is typically defined 
as the point where the change in the error function $E(R, t)$ between successive iterations falls below a predefined 
threshold.  

Variants of the ICP algorithm enhance its robustness to noise, outliers, and partial overlaps. For instance, weighted ICP 
assigns confidence weights $w_i$ to each correspondence, modifying the error function to:

\[
E_w(R, t) = \frac{1}{\sum_i w_i} \sum_{i=1}^{N} w_i \| R p_i + t - q_{\sigma(i)} \|^2,
\]
while robust error metrics, such as the Huber or Tukey loss, can reduce the influence of outliers. These extensions make 
ICP applicable to a wide range of practical problems in 3D computer vision, robotics mapping, and pose estimation~\cite{Zhang2016}. 

\chapter{Hardware and Design}
\section{Design}

For the design (Figure~\ref{fig:handheld_device}), inspiration was taken from the handheld system 
described in \textit{A handheld stereo vision and LiDAR system for outdoor dense RGB-D mapping 
using depth map completion based on learned priors}~\cite{bleier2024}. Both the LiDAR sensor and 
the monocular camera are mounted on a rectangular box that also houses the essential electronic 
components, including the Raspberry~Pi, the IMU and the DC-DC converter. This compact integration 
ensures that the hardware is mechanically stable and protected against external influences. The 
most notable difference compared to the design presented in \cite{bleier2024} is the integration of 
a battery box, which in this prototype is repurposed from a portable light box. This modification 
enables self-sufficient operation in outdoor environments and highlights the emphasis on 
time-efficient and practical design choices.
A touchscreen was also installed in
the device, which can be used to start recording rosbags and control data acquisition. The display runs
the normal Ubuntu interface, which means that any other action can also be performed on it. Since the device is
still in development, the components and cables have been installed in a very pragmatic way, so that each component
is still easily accessible and cable connections can be checked very quickly without having to disassemble the
entire device.
Since the basic idea of the project is to keep the cost of the device as low as possible,
the housing and other mounts were all 3D printed. This ensures
that the parts used can be modelled independently, so that they fit
very well into the final result without pushing up the budget. 
The parts were printed with PLA (see section~\ref{sec:PLA} on page~\pageref{sec:PLA}), as it is a very beginner-friendly
material that is forgiving of many errors in the printing process, and printed on an Ultimaker S5.
Detailed drawings and additional views of the handheld device are provided in 
Appendix~\ref{app:handheld_drawings} for reference.

\begin{figure}[h!]
    \centering
    \begin{subfigure}[b]{0.4\textwidth}
        \centering
        
    \end{subfigure}
    \hfill
    \begin{subfigure}[b]{0.4\textwidth}
        \centering
        
    \end{subfigure}
    \caption{Pictures of handheld device}
    \label{fig:handheld_device}
\end{figure}

\begin{figure}[htbp]
    \centering
    \begin{subfigure}[b]{0.4\textwidth}
        \centering
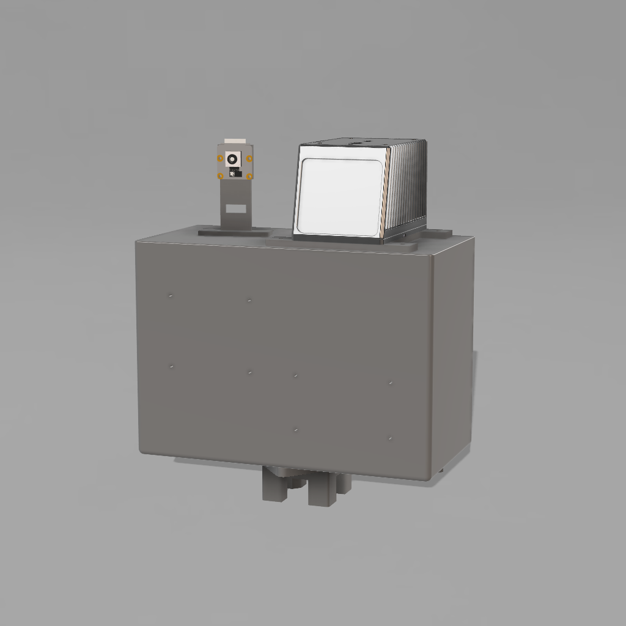
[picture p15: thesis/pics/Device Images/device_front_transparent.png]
        
        \caption{Front}
        \label{fig:bild1}
    \end{subfigure}
    \hfill
    \begin{subfigure}[b]{0.4\textwidth}
        \centering
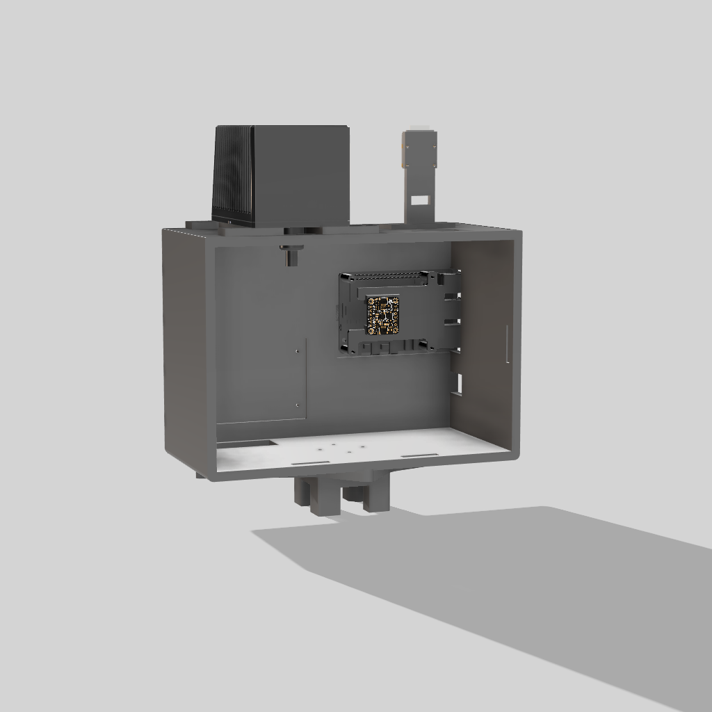
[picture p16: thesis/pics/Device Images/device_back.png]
        
        \caption{Back}
        \label{fig:bild2}
    \end{subfigure}
    \caption{Front and back of the handheld device's body}
    \label{fig:drei_bilder}
\end{figure}

\section{Components}
%\begin{figure}[htbp]
%    \centering
%    % Reihe 1
%    \begin{subfigure}[b]{0.45\textwidth}
%        \centering
%        \includegraphics[width=\textwidth]{Platzhalter.jpg}
%        \caption{PI 5}
%        \label{fig:pi5_socket}
%    \end{subfigure}
%    \hfill
%    \begin{subfigure}[b]{0.45\textwidth}
%        \centering
%        \includegraphics[width=\textwidth]{Platzhalter.jpg}
%        \caption{Mid--70}
%        \label{fig:mid_70}
%    \end{subfigure}
%    
%    \vskip 0.5cm % Abstand zwischen den Reihen
%
%    % Reihe 2
%    \begin{subfigure}[b]{0.45\textwidth}
%        \centering
%        \includegraphics[width=\textwidth]{Platzhalter.jpg}
%        \caption{BNO085}
%        \label{fig:imu_img}
%    \end{subfigure}
%    \hfill
%    \begin{subfigure}[b]{0.45\textwidth}
%        \centering
%        \includegraphics[width=\textwidth]{Platzhalter.jpg}
%        \caption{Sirui H99}
%        \label{fig:h99_sirui}
%    \end{subfigure}
%    
%    \vskip 0.5cm % Abstand zwischen den Reihen
%
%    % Reihe 3
%    \begin{subfigure}[b]{0.45\textwidth}
%        \centering
%        \includegraphics[width=\textwidth]{Platzhalter.jpg}
%        \caption{Camera Module 3}
%        \label{fig:cam_3}
%    \end{subfigure}
%    \hfill
%    \begin{subfigure}[b]{0.45\textwidth}
%        \centering
%        \includegraphics[width=\textwidth]{Platzhalter.jpg}
%        \caption{Touch Display}
%        \label{fig:touch_img}
%    \end{subfigure}
%
%    \caption{Sechs Bilder in drei Reihen und zwei Spalten}
%    \label{fig:6bilder_2spalten}
%\end{figure}

\subsection*{Raspberry Pi~5 (16GB) and M.2 Socket with SSD for Higher Speed}
The main component of the handheld device is a Raspberry Pi 5 with 16GB. 
The Raspberry Pi is an inexpensive, versatile single-board computer that, thanks to its compact design and low power consumption (5V/5A), 
can be connected directly to the Pi via a CSI interface.
However, the Raspberry Pi also has limitations: Its CPU and GPU performance is limited compared to powerful x86 systems, which can lead to 
bottlenecks in computationally intensive tasks such as real-time 3D data processing or complex AI applications. In addition, programs that 
use CUDA cannot be used, which severely limits the choice of programs for calculating depth images, for example. Despite these limitations, 
however, the Raspberry Pi offers excellent value for money and is therefore the right choice for this system, even if it means that many 
processing steps have to be outsourced to another system.
In addition, an M.2 socket is installed in combination with a solid-state drive (SSD), which expands the storage capacity and significantly 
increases the system's data transfer rates. Compared to conventional microSD cards, which often serve as the primary storage medium for the 
Raspberry Pi, M.2 SSDs offer significantly higher write and read speeds as well as improved durability. This device has a 256GB SSD installed.

\subsection*{Livox Mid-70}
    The Livox Mid-70 is a compact, cost-effective LiDAR sensor designed specifically for 3D data capture and robotics applications. 
    It offers a 70° field of view with non-repetitive scan pattern technology that enables uniform coverage of the scene and high point 
    density over time. With a range of up to 260 meters under optimal conditions and high measurement accuracy, the Mid-70 is capable of 
    generating detailed point clouds suitable for mapping, object detection, and sensor fusion. Another advantage is the compact design of the scanner. 
    However, the use of the non-repetitive scan pattern for static scenes requires a longer acquisition time to achieve complete coverage. Unlike the Livox Mid-360, 
    the Livox Mid-70 comes with an additional converter box, which makes it very easy to connect Ethernet, power supply or PPS signal cables. In addition, the 22.2V 
    from the battery can be connected directly to it without a voltage converter. However, a major disadvantage of the Mid-70 is the lack of an internal IMU, which 
    means that you have to use an external one if you want to do SLAM or similar tasks, for example. Overall, however, the Livox Mid-70 is a very good choice for 
    handheld devices like ours, as you get a solid laser scanner for the low price of around €900 as of September 2025.

\subsection*{External BNO085 IMU}
The handheld prototype employs the Adafruit BNO085, an inertial measurement unit (IMU) that combines 
a 3-axis accelerometer, gyroscope and magnetometer in a compact form factor. The BNO085 is based on 
the Bosch BNO080/BNO085 sensor and integrates a dedicated 32-bit ARM Cortex-M0+ processor running 
the \textit{Hillcrest Sensor Hub} firmware. This embedded sensor fusion engine enables real-time 
orientation estimation, providing quaternion, Euler angle, and linear acceleration outputs without 
requiring extensive host-side computation.
The device is directly connected to the PI by I\textsuperscript{2}C over the GPIO--Pins.
Due to its low power consumption, small size and ability to deliver accurate 
pose information even under dynamic motion, the BNO085 is well suited for integration into portable 
systems such as the proposed handheld LiDAR--camera device.
The choice of this sensor was also motivated by the fact that a BNO085 is integrated in the Livox 
Avia LiDAR itself.\cite{AdafruitBNO085}

\subsection*{SIRUI H99-Pro}
    When choosing a battery, we opted for the H99 Pro from SIRUI. 
    The advantage of this battery is not only that it can output up to 160W with its D-tap output (22.2V/7.5A), 
    which is more than enough for the system.
    The main reason for choosing this battery is the fact that it is a “handheld” battery and can therefore 
    be used directly as a handle.

\subsection*{Raspberry Pi Global Shutter camera}
We use the Raspberry Pi Global Shutter Camera with the Sony IMX296 sensor
(1.58\,MP, 1456$\times$1088, 3.45\,$\mu$m pixels, 1/2.9''). A 4\,mm 1/2''
C/CS-mount lens is employed; on IMX296 this yields an effective field of view
of approximately $64^\circ \times 50^\circ$ (H$\times$V) and about $76^\circ$
diagonal. The lens comfortably covers the smaller 1/2.9'' sensor, and the
global shutter exposes all pixels simultaneously.

\subsection*{Raspberry Pi Touch Display 2}
The touchscreen provides a direct interface for user interaction,  
allowing live preview, data acquisition control and system configuration.

%\subsection*{External Computer}
%\textcolor{red}{Text zu warum externer PC verwendet werden muss $\rightarrow$ Uni-Fusion}
%\begin{table}[htbp]
%\centering
%\renewcommand{\arraystretch}{1.3} % Zeilenabstand
%\begin{tabular}{>{\bfseries}l l}
%\hline
%Component & Specification \\
%\hline
%CPU (Processor) & 13th Gen Intel Core i9-13900KS x32) \\
%GPU (Graphics Card) & NVIDIA GeForce RTX 4080 16 GB GDDR6X \\
%RAM & 64,0 GB\\
%Operating System & Ubuntu 24.04 LTS\\
%\hline
%\end{tabular}
%\caption{Main PC components}
%\label{tab:pc_specs_simple}
%\end{table}

\section{Purchase costs}

Table~\ref{tab:device-costs} indicates a total hardware expenditure of approximately 1{,}327\,€,
placing the prototype squarely in the \emph{low-cost} category for 3D sensing and mapping.
While the Livox Mid70 (900\,€) constitutes the primary cost driver, the remaining components
(Raspberry~Pi~5 with accessories, camera module and optics, IMU, tripod and peripherals)
are commodity parts with comparatively modest prices. This bill of materials enables
cost-effective replication, straightforward maintenance (due to off-the-shelf availability),
and even multi-unit deployments under constrained budgets. The resulting platform is thus
well suited for teaching labs and student projects.All prices are approximate and refer to prices as of September 2025.

\begin{table}[h]
\centering
\begin{tabular}{ll}
\toprule
\textbf{device} & \textbf{$\sim$price [€]} \\
\midrule
Raspberry PI 5 (16GB)   & 130 \\
PI accessories (M2 Socket, cooler)   & 54 \\
Global Shutter camera & 60 \\
IDS 2MP objective & 100 \\
Touchpad 2 & 43 \\
Livox Mid70   & 900 \\
IMU BNO085    & 30 \\
SIRUI H99 Pro & 110 \\
other (voltage converter, cables, etc.) & 30 \\
\midrule[\heavyrulewidth] % dickere Linie für Gesamtsumme
\textbf{Overall} & \textbf{$\sim$1500} \\
\bottomrule
\end{tabular}
\caption{Listing of all device costs}
\label{tab:device-costs}
\end{table}

\chapter{Software}

The following chapter describes the structure of the software and shows which
programmes are used and gives a brief overview of the functions.
It also deals with installation problems that I myself
encountered.
The complete code files can be downloaded from the Github repository ("https://github.com/jakob2907/rasberrypi-based-LiDAR-CAMERA-rig")~\cite{github_handheld}
and tested yourself.

\section{Setup}
The handheld device presented has several sensors, including a Livox Mid 70 and
a PI camera. Since we need to process their sensor data, we use ROS 2 (Robotic Operating System), which
enables the publication and processing of data via standardised topics.
Each sensor functions as its own ROS node and can be operated independently of the others.
For this reason, instead of the Raspberry Pi's own operating system, we have installed Ubuntu 24.04.02 LTS and the
corresponding ROS 2 Jazzy, because ROS is not currently available for Raspberry Pi OS.~\cite{ros2_jazzy_releases} 

\begin{table}[h!]
\centering
\begin{tabular}{|l|l|}
\hline
\textbf{Category} & \textbf{ROS-Packages / Software} \\
\hline
LiDAR & Livox-Ros2-Driver~\cite{LivoxROS2Driver} \\
\hline
Camera & Camera-Ros~\cite{CameraROS} \\
\hline
IMU & BNO085-ROS2-Node~\cite{BNO085ROS2Node} \\
\hline
Intrinsic Calibration & own calibration script~\cite{github_handheld}\\
\hline
Extrinsic Calibration & FAST-CALIB as ROS2 package~\cite{FASTCalibROS2}\\
\hline
\end{tabular}
\caption{Overview of used ROS packages}
\label{tab:ros_packages}
\end{table}

\section{Uni-Fusion: Universal continuous mapping}

Uni-Fusion~\cite{yuan2024uni} is a universal continuous mapping framework for 3D surfaces and arbitrary sensor-derived properties, and it was
originally developed by the same research chair at which this Bachelor's thesis is being conducted. Unlike
learning-based mapping methods, Uni-Fusion does not require any pre-training, yet it can directly incorporate heterogeneous
data modalities (e.g. RGB colors, infrared intensities or even high-dimensional semantic descriptors) into a unified map
representation. This capability is achieved through a novel encoder--decoder scheme based on Gaussian
Process Regression (GPR): the approach “decouples” GPR by approximating its kernel, allowing a set of points and their
properties to be encoded as a single compact latent feature vector and later decoded to predict continuous field values. In essence, the kernel approximation (using techniques like Nyström eigenfunction decomposition)
provides a fixed position encoding function, while the local point observations are aggregated by a content encoding function
to produce a latent code. The latent code serves as the parameters of a local implicit model such that any spatial query can
be decoded (via the same kernel basis) into a predicted property value (for example, a signed distance or a color intensity) in
that region. Because this encoding--decoding model is analytic and data-agnostic, Uni-Fusion can handle
arbitrary types of point properties without specialized training or tuning for each property. The latent
representation also makes the map continuous, meaning that surface geometry and other fields are not stored on a fixed grid
but can be queried at any resolution, enabling high-fidelity outputs.

\begin{figure}[!htb]
\centering
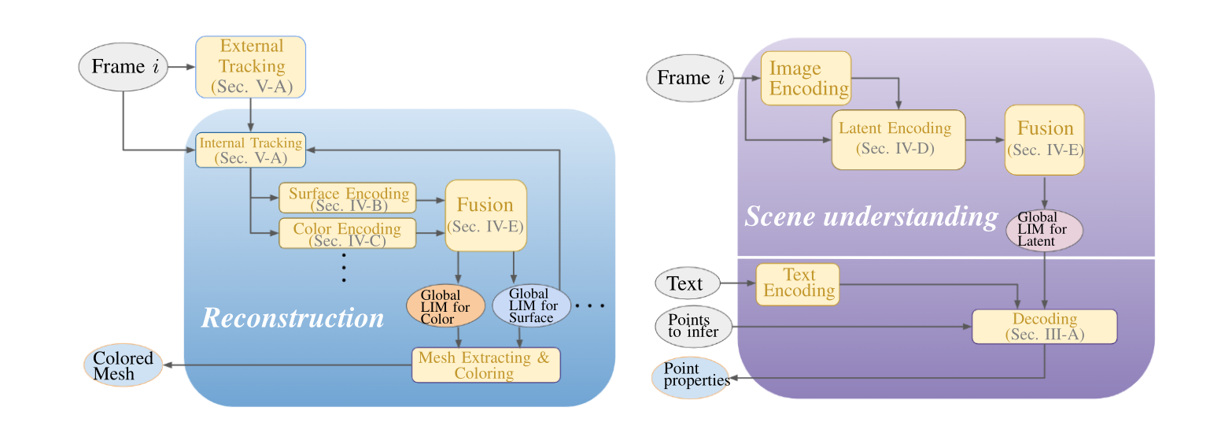
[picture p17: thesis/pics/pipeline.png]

\caption{Overview of the Uni-Fusion mapping pipeline, which incrementally fuses per-frame latent maps into a global Latent
Implicit Map (LIM) for continuous surface and property reconstruction.\cite{yuan2024uni}}
\label{fig:pipeline}
\end{figure}
Figure~\ref{fig:pipeline} illustrates how per-frame local latent maps are fused into the global LIM.
Spatially, Uni-Fusion partitions the scene into a regular voxel grid (typically sparse in memory) and for each voxel it
aggregates local point data into a latent feature vector. This collection of latent vectors over all occupied
voxels constitutes the Latent Implicit Map (LIM) -- a continuous implicit representation of the scene's geometry and any
additional property fields. Each voxel's latent feature encodes the local geometry or other scalar/vector properties observed in
that cell, effectively acting as a locally conditioned implicit function. Incremental mapping is achieved by processing incoming
sensor frames one at a time and fusing each frame's local contributions into the global LIM. In practice, for
each new RGB-D frame (with an estimated pose from a parallel tracking system) a local LIM is computed: the depth points
(with their associated attributes) are first assigned to their respective voxels and then an encoding is performed per voxel to
update that voxel's latent feature. These local latent maps from the frame are then merged into the global latent map on a
voxel-by-voxel basis. The fusion operation can be as simple as averaging or aggregating the latent vectors using the count of
points, ensuring that the global LIM integrates information over time as more frames are observed. This design naturally supports
real-time operation: mapping is done incrementally with each frame, and the computation in each voxel is independent and
bounded by the local data, keeping the update efficient. Indeed, Uni-Fusion is reported to run as a real-time algorithm in
practice, demonstrating that the analytic latent encoding (which avoids heavy iterative optimization or neural
network inference) is fast enough for online use.

Once integrated into the global LIM, the latent representation can be converted into an explicit 3D map or other output
modalities. For example, to obtain a surface mesh, one can densely sample spatial points and decode the global latent implicit
surface (using the combined contributions of nearby voxel latents) to evaluate a continuous signed distance field; a standard
isosurface extraction (e.g. Marching Cubes) then produces a mesh of the reconstructed surface. Similarly, to render a mapped
property like color, one can query the color field at arbitrary surface points using the global color latent map, yielding a texture
or per-vertex coloring for the mesh. Because the latent map encodes a continuous field, these queries can be made at arbitrarily
fine resolution, which means the reconstruction is not limited by voxel size in detail. Crucially, Uni-Fusion's framework supports
multi-modal mapping concurrently: for instance, in an RGB-D reconstruction scenario, two LIMs are maintained in parallel -- one
for geometry (surface occupancy or SDF) and one for color -- and both are updated with each frame. The system's design cleanly
generalizes beyond RGB-D data; additional data channels (such as infrared readings or learned feature vectors)
can be handled by simply introducing additional PropertyMap instances that use the same
GPR-based encoder on the new data type. No retraining or architectural change is needed to incorporate a
new property -- the kernel-based encoder will compute latent codes for the new values just as it does for color, given raw input
pairs of 3D coordinates and property values. Impressively, the authors demonstrate even a high-dimensional CLIP embedding
field: image features from a pre-trained vision-language model are projected onto the surface, and Uni-Fusion builds a LIM that
stores, for each region of the scene, a latent feature encoding the local CLIP descriptors; this allows semantic queries (in the
form of text prompts) to be answered by comparing the stored CLIP features to text embeddings, effectively achieving open-
vocabulary semantic mapping on the 3D surface. The flexibility to handle such diverse inputs in one mapping
system underscores the “universal” nature of Uni-Fusion.

In summary, Uni-Fusion enables real-time, incremental 3D mapping that unifies geometry and semantics in a single continuous
representation. The method's key insight is to use a decoupled GPR encoder -- decoder to directly produce local implicit functions
(Latent Implicit Map cells) from raw sensor data, avoiding any network training and associated runtime costs. As new data arrives,
the latent map is refined on-the-fly by fusing local latent updates, resulting in a globally
consistent scene representation that can be queried for detailed surfaces or property values at will. The fact that this Bachelor's
thesis is conducted within the same institute that developed Uni-Fusion has provided a unique opportunity to build upon and
closely examine this cutting-edge mapping framework.

\chapter{Approach}
\label{sec:approach}

In this chapter, the methodological approach of the work is introduced. The goal is to
outline the sequence of steps (shown in \ref{fig:schematic_workflow}) taken to achieve the intended results. Starting with the
acquisition of raw data, the subsequent stages of preprocessing, processing and evaluation
are presented. Each step is described to provide a transparent overview of the applied
procedure and to ensure reproducibility of the approach.

\begin{figure}[ht!]
    \centering
    %pipeline_diagram.png
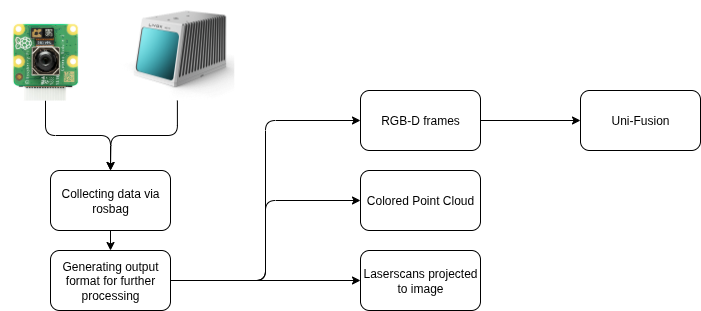
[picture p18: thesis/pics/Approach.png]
    
    \caption{Schematic representation of the data processing chain}
    \label{fig:schematic_workflow}
\end{figure}

\section*{Gathering data from device}
The initial step of the approach involves the systematic acquisition of raw data from the
developed device. For this purpose, three complementary sensors are integrated: a Livox
Mid-70 LiDAR scanner, a BNO085 inertial measurement unit (IMU) and a Raspberry PI Global Shutter camera.
Each of these components contributes essential information required for subsequent data
processing. The Livox Mid-70 provides dense three-dimensional point clouds that describe
the spatial structure of the environment. The BNO085 IMU delivers inertial data, including
acceleration and rotational velocity, since the IMU is essential for obtaining reliable
pose estimates while the device is in motion and for enabling future applications such as SLAM.
In addition, the Global shutter camera captures image sequences that offer visual context
and enable to color pointclouds. To ensure synchronized and reproducible data collection, the
Robot Operating System (ROS) framework is employed. All sensor streams are recorded using
the rosbag tool, which stores the data in a structured format that preserves
timestamps and message integrity. This unified recording approach enables consistent
alignment of heterogeneous data sources and provides a reliable basis for subsequent
preprocessing, calibration and evaluation steps.

\section*{Generating output for further processing}

After the raw data has been recorded using rosbag, we create a hierarchical folder structure so 
that we can export the data. Theoretically, the depth images and other data could also be generated on 
the Raspberry PI. However, since its performance is very limited and you will need to switch to a more 
powerful device later on due to the performance required for Uni Fusion, we can also process the data on 
this higher performing device. On top of that the usage of the other device also enables us to use
CUDA-based programs, like Open3D.

The output folder contains a {index.txt} file. This file serves as a mapping between each scan folder
and its corresponding underlying ROS bag file. Furthermore, the folder contains a JSON file that provides
the recorded IMU measurements together with their corresponding timestamps, ensuring an explicit temporal association of the data.
In addition, a separate scan\_xx folder is created for each registered scan that we receive via 
the livox topic (/livox/lidar), with the identifier at the end being incremented 
chronologically. Each scan folder contains the points of the recorded point cloud once as a numpy array 
(.npy) and as a .pts file. In addition, the associated image (.png) and the 
timestamp (.txt) of when the scan was recorded by PointCloud and Image are saved.
When creating the scanfolder we check if the timestamp between the Livox scan and the captured image
is close to each other. This ensures that a scan is not matched with an image recorded at a substantially
different time; in our case, temporal alignment is defined as a maximum acquisition time difference of 10 ms.
The synchronization of the sensors and the use of a common time standard are ensured via the Precision Time 
Protocol (PTP), see~\ref{sec:PTP}.

\begin{figure}[ht!]
    \begin{verbatim}
    \output_dir{
        imu_data_(name of rosbag).json
        index.txt
        scan_001/
            pointcloud.npy
            pointcloud.pcl
            image.png
            timestamp.txt
        scan_002/
            ...
    }
\end{verbatim}
\end{figure}

\section*{Data processing}
This work presents three data-processing pathways. First, depth images are generated from
LiDAR and camera data and used to compose RGB-D input frames for Uni-Fusion. Second, a
routine produces colored point clouds from multiple frames to assess the extrinsic
calibration between the LiDAR and the camera. Third, the same routine supports the
``opposite direction,'' i.e., projecting LiDAR point-cloud points into the image domain.

\subsection*{Depth-Images for RGB-D}
In order to prepare the data for subsequent RGB-D fusion, a dedicated generation process was 
implemented. The goal is to produce pairs of RGB frames and corresponding depth images that are 
aligned and can be directly consumed by fusion frameworks such as Uni -- Fusion. Each scan 
directory contains a synchronized LiDAR point cloud and an RGB image. Using the known extrinsic 
and intrinsic calibration parameters, the LiDAR points are projected into the camera coordinate 
system. Based on this projection, a depth map is constructed in which each pixel encodes the 
distance of the nearest LiDAR point to the camera. Empty pixels remain black at first, while valid pixels 
are normalized to an 8-bit intensity representation to ensure compatibility with standard image 
formats.
Together with the original RGB frame, these depth maps are stored in a structured output 
folder, where each frame is saved as frameXXX.png and the corresponding depth map as 
depthXXX.png. This systematic naming convention ensures that both modalities remain 
synchronized across all frames of a scan sequence. By organizing the data in this format, the 
pipeline produces ready-to-use input that enables efficient integration into RGB-D based Uni--Fusion
and supports reproducibility of experiments.

\begin{figure}[ht!]
    \begin{verbatim}
    \output_dir{
        cam_params.json 
        depth001.png
        depth002.png
        depth...
        frame001.png
        frame002.png
        frame...
        (mesh.ply)
    }
\end{verbatim}
\end{figure}

\subsection*{Sparse Depth Image}
\label{sec:sparsedepth}
The Livox Avia LiDAR provides less than 10,000 points per individual scan.
While this number may be sufficient for certain tasks such as simple mapping or coarse object detection, 
it is very limited when compared to the requirements of dense depth image generation. 
A depth image with a resolution of $640 \times 480$ pixels contains a total of 307,200 pixels.
If only 10,000 points are projected into this image space, approximately one out of 31 pixels,
that is around $3.25\%$, will actually receive a depth value.
In combination with its flower -- shaped scanning pattern
the resulting image is therefore extremely sparse, and large portions of the image remain undefined (see Figure \ref{fig:sparse_depth}). 
This low density is not adequate for applications that rely on detailed depth maps.

\begin{figure}[ht!]
    \centering
    %pipeline_diagram.png
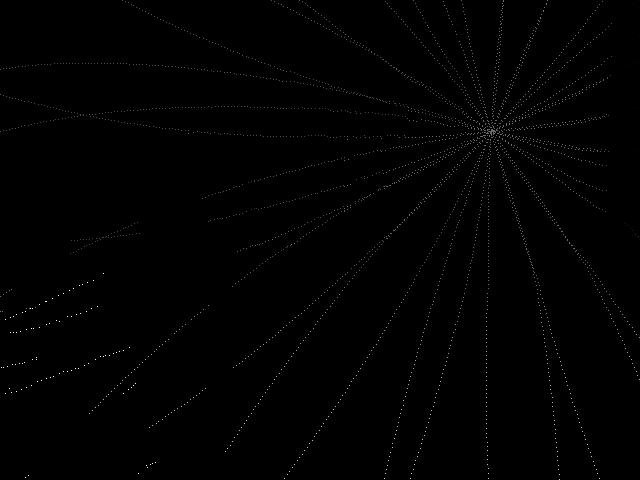
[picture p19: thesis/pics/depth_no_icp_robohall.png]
    
    \caption{Sparse Depth Image}
    \label{fig:sparse_depth}
\end{figure}

\begin{figure}[ht!]
    \centering
    %pipeline_diagram.png
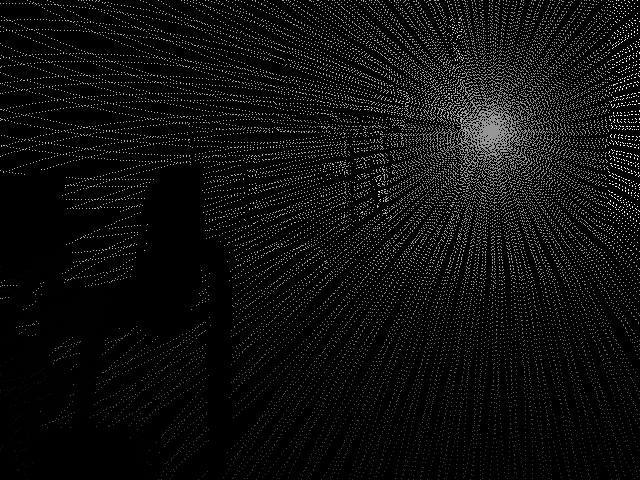
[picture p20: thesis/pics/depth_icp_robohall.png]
    
    \caption{Depth Image with ICP Alignment of several scans}
    \label{fig:icp_depth}
\end{figure}

\begin{figure}[ht!]
    \centering
    %pipeline_diagram.png
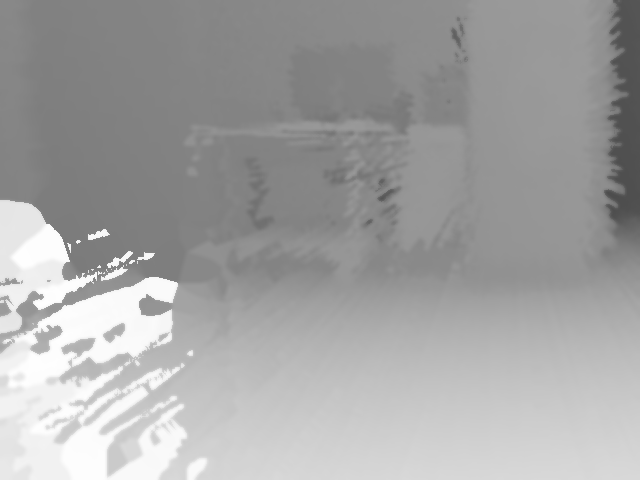
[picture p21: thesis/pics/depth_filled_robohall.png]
    
    \caption{Depth Image with ICP and bilinear Interpolation}
    \label{fig:icp_filled_depth}
\end{figure}

In this implementation, sparsity is mitigated in a purely geometric manner. Rather than relying solely on the
most recent LiDAR frame, consecutive scans are accumulated into a global point cloud via scan-to-map registration
using the Iterative Closest Point (ICP) algorithm. Each incoming scan is aligned to the growing map, so the set
of points projected into the camera frame includes valid measurements from previously acquired scans. This
accumulation markedly increases the number of points that project onto the image plane, thereby improving the
effective coverage in the $640 \times 480$ depth images (see Figure~\ref{fig:icp_depth}).
After projection, gaps remain because not every image location receives a measurement, even with multiple
aligned scans. To address this, a bilinear interpolation scheme assigns plausible depth values to undefined
pixels. This step smooths the depth map and yields a visually more complete representation of the scene (see
Figure~\ref{fig:icp_filled_depth}), although the accuracy remains limited compared to advanced learning-based
completion methods.
A further limitation of this incremental mapping strategy is the warm-up required for the global map to
accumulate sufficient points for adequate image-plane coverage. Consequently, the first few scans—containing
relatively few points—produce depth images with very low density.

In contrast to this straightforward interpolation and alignment strategy, Bleier et al.\ address the problem
of sparse depth images with a learning-based completion method. Their approach, named ScaleCov
~\cite{bleier2024}, builds upon the earlier DepthCov concept (Dexheimer and Davison, 2023~\cite{dexheimer2023learning}) by introducing 
a learned covariance function as a prior for depth estimation. Instead of directly regressing the full depth 
map from sparse LiDAR input --- which often leads to unreliable predictions in regions without true depth 
measurements --- ScaleCov integrates monocular depth estimates from Metric3Dv2 as an additional source 
of information. Using the available LiDAR returns, the method computes scale adjustments for pixels 
where valid depth is observed and propagates this information across the image. This strategy results in 
significantly denser and more accurate depth maps compared to simple interpolation, and it also produces 
a depth variance map that highlights areas of high uncertainty such as the sky or unobserved surfaces. 
These confidence estimates enable a more reliable integration of the completed depth data into downstream 
tasks like semantic mapping or 3D scene reconstruction.

\subsection*{Colored PointCloud}
In addition to the generation of RGB-D frames, the pipeline also supports the creation of colored 
pointclouds. While depth images encode only the geometric distance information of the scene, 
colored pointclouds enrich the LiDAR data with appearance information from the RGB images. The 
process begins by projecting all LiDAR points into the image space using the intrinsic and extrinsic 
calibration parameters. The underlying mathematics of this projection has already been introduced in 
the section \ref{sec:proj_lidar_image}, where the transformation from 3D LiDAR 
coordinates into 2D image coordinates is described in detail. Based on this mapping, only those 
points are considered that are visible within the field of view of the camera, thereby discarding 
all points that lie behind the camera plane or outside the image boundaries. For every visible 
point, the corresponding pixel in the RGB frame is identified and its color value is assigned to 
the 3D coordinate. As a result, the output is a pointcloud in which each entry consists of six 
values, representing the 3D position $(x, y, z)$ together with the associated color components 
$(r, g, b)$. The generated colored pointclouds are not only useful for visualization but also serve 
as valuable input for further reconstruction and semantic mapping tasks, since they combine precise 
geometric information with rich appearance cues from the environment.

\subsection*{Projection of pointcloud to image}
Besides generating colored pointclouds, the reverse operation, namely projecting the pointcloud 
back into the image space, was also performed. This functionality serves as a simple yet effective 
diagnostic tool to verify whether the LiDAR sensor and the camera share overlapping fields of view. 
By transforming the LiDAR points into the coordinate system of the camera and then mapping them 
onto the image plane, one can directly visualize which regions of the captured frame are covered by 
LiDAR measurements. If the projected points uniformly fill the image space, it indicates that the 
scanning range of the LiDAR aligns well with the camera's perspective, ensuring that both sensors 
observe the same part of the environment. Conversely, visible gaps or incomplete coverage in the 
projection would reveal calibration errors or misalignment in the sensor setup. This reverse 
projection therefore provides a straightforward method to assess the spatial consistency of the 
recordings and guarantees that the generated RGB-D data can later be reliably fused. The underlying 
mathematical transformations correspond to those described in the section \ref{sec:proj_lidar_image},
applied in the inverse direction for the specific purpose of coverage validation.

\section*{RGB-D frames in Uni-Fusion}  
The generated RGB-D output is directly compatible with the input requirements of Uni--Fusion. Each 
scan sequence produces a structured set of paired RGB frames and depth images that are named in a 
consistent format (frameXXX.png and depthXXX.png). This naming scheme ensures 
that the temporal correspondence between both modalities is preserved across all frames. Uni--Fusion 
expects such synchronized image pairs to be specified in a configuration file, where the dataset is 
defined using a yaml description. Within this file, the paths to the RGB and depth image 
directories are listed, together with the corresponding calibration parameters, so that Uni--Fusion 
can correctly interpret the metric depth values during reconstruction. Since the output generated 
by the pipeline already follows the required structure, the integration into Uni--Fusion is seamless. 
This design choice not only reduces preprocessing overhead, but also guarantees that the data can be 
immediately used for volumetric fusion and scene reconstruction, making the generated RGB-D frames 
a central component in the overall workflow.

\chapter{Experiments and results}
\label{sec:experiments}
\section{RGB-D}

To generate depth images from the data recorded with the laser scanner, different approaches were investigated, 
which differ in their methodological setup and in the requirements for preprocessing and data fusion. The following 
subsections describe two main strategies: single static capture and multiple static captures requiring ICP 
registration.

\subsubsection*{Single Static Capture}
In the case of a single static capture, the process is comparatively simple, since each point cloud can be processed 
independently without explicit registration with further scans. This allows a direct projection of the three-
dimensional point data onto the image plane, resulting in depth information represented as grayscale or color images. 
For this approach, the camera position in relation to the point cloud is particularly important, as only then a 
consistent depth representation can be ensured. The result is a straightforward and computationally efficient 
workflow for generating depth images from individual scans.

\subsubsection*{Multiple Static Captures with ICP}
If more than one static scan is taken, the different point clouds must be aligned with each other in order to obtain 
a consistent reconstruction of the scene. For this purpose, registration methods such as the Iterative Closest Point 
(ICP) algorithm are required, which compute an accurate overlap of the scans by minimizing point distances. By fusing 
several scans, a denser point cloud model is obtained, which significantly increases the quality of the generated 
depth images but is associated with additional computational cost.

%\subsubsection*{Dynamic Captures with SLAM}
%The case of dynamic recordings is more complex, where the sensor is continuously moved. In this scenario, SLAM 
%methods (Simultaneous Localization and Mapping) are necessary, since not only the point clouds must be registered 
%but also the sensor trajectory has to be estimated simultaneously. The calibration and integration of the Inertial 
%Measurement Unit (IMU) play a central role here, since only through the fusion of visual and inertial measurements a 
%robust and consistent reconstruction can be achieved. The resulting depth images from this approach are able to 
%represent larger and more complex environments in high resolution and with high geometric consistency, which is 
%particularly relevant for applications in mobile robotics or augmented reality.

\subsection{Experiment 1}

This experiment is based on a single static scan captured in the KUKA Lab. As illustrated in
Figure~\ref{fig:rgb_sparse}, the left panel (a) shows the original RGB image, while the right panel (b)
shows the corresponding colored point cloud. The color information is mapped from the RGB image onto the
reconstructed 3D geometry, enabling an intuitive visual linkage between 2D appearance and 3D structure.

To assess scan-to-map registration, we compare two ICP variants using depth images (see
Figure~\ref{fig:interp_completed}): ICP on the raw depth image (Figure~\ref{fig:interp_completed}, panel
(c)) and ICP on a bilinearly interpolated depth image (Figure~\ref{fig:interp_completed}, panel (d)).

Qualitatively, the bilinear interpolation reduces quantization and staircase artifacts in the depth field,
yielding smoother correspondences, more stable ICP convergence, and fewer local misalignments, especially
along slanted surfaces and at geometric edges. A minor trade-off is a slight smoothing of very fine
structures, which can attenuate subtle details.

Conclusion: In this static scan setting, the interpolated-depth variant produces a crisper alignment and a
more visually coherent geometry compared to the raw-depth ICP baseline, while preserving the essential
structure of the scene observed in Figure~\ref{fig:rgb_sparse}.

\begin{figure}[H]
  \centering
  \begin{minipage}{0.48\textwidth}
    \centering
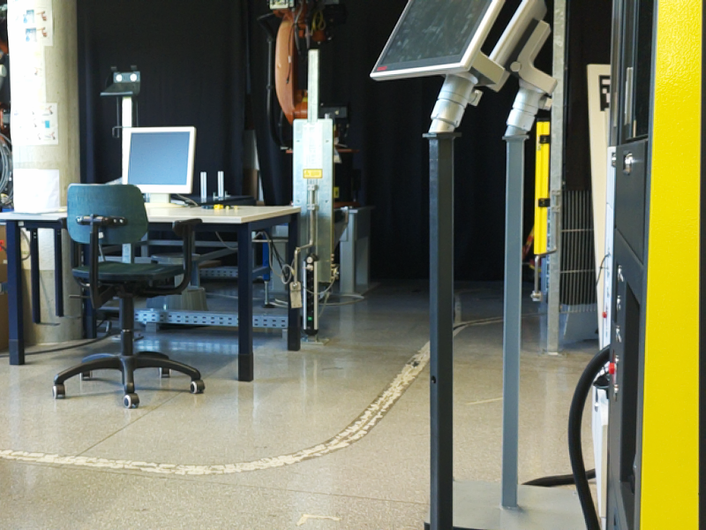
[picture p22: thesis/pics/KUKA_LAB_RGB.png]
    
    \caption*{(a) Original RGB image}
    \label{fig:col_pcl}
  \end{minipage}\hfill
  \begin{minipage}{0.48\textwidth}
    \centering
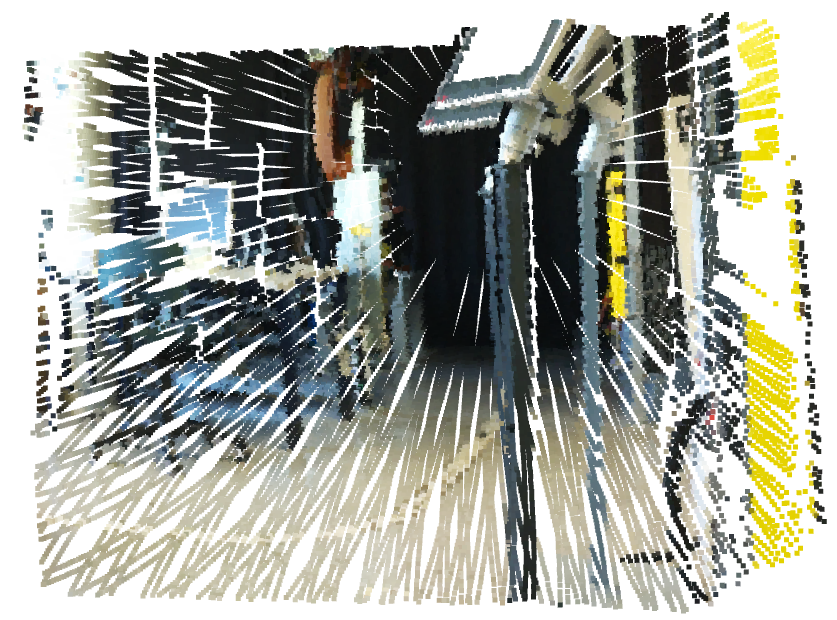
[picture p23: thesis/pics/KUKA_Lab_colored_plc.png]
    
    \caption*{(b) Colored PointCloud}
  \end{minipage}
  \caption{Example of an RGB image and the corresponding colored pointcloud.}
  \label{fig:rgb_sparse}
\end{figure}

\begin{figure}[H]
  \centering
  \begin{minipage}{0.48\textwidth}
    \centering
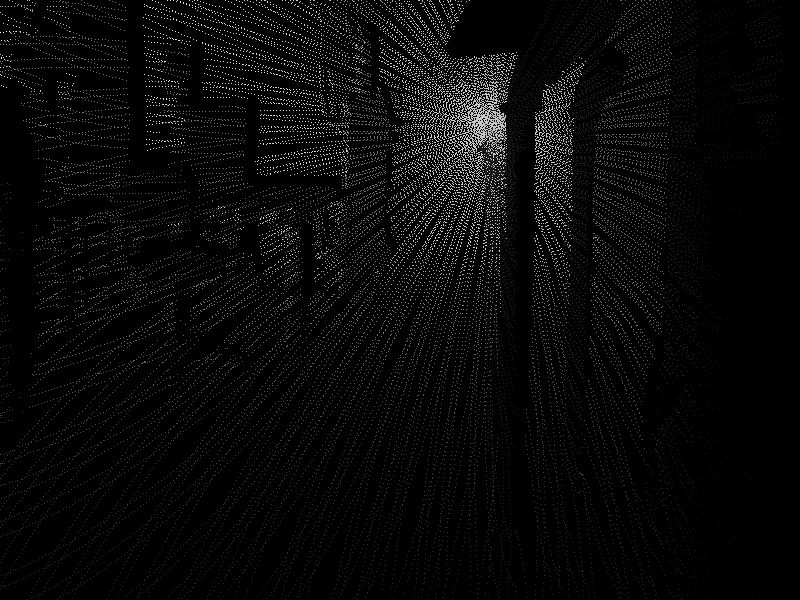
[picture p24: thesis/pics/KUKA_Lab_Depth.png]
    
    \caption*{(c) ICP aligned image}
  \end{minipage}\hfill
  \begin{minipage}{0.48\textwidth}
    \centering
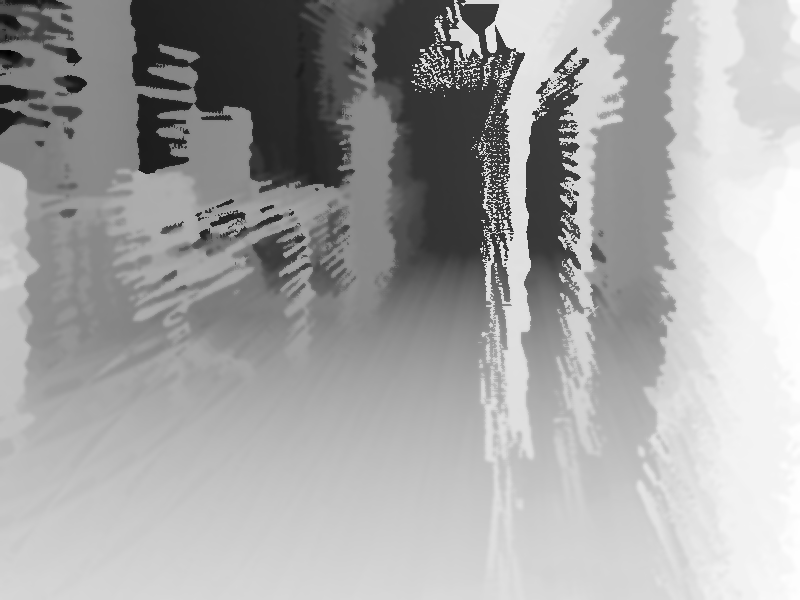
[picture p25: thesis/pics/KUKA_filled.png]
    
    \caption*{(d) ICP + bilinear interpolation depth image}
  \end{minipage}
  \caption{}
  \label{fig:interp_completed}
\end{figure}

\subsection{Experiment 2}

Experiment 2 consists of four single static scans captured in the robotics hall. Each column corresponds to a
distinct viewpoint (robo\_1 to robo\_4). The first row shows RGB frames, the second row shows depth images
aligned to the map via ICP, the third row shows the corresponding raw depth inputs, and the fourth row presents
visualization snapshots of the registered reconstructions. This layout allows a side-by-side comparison across
viewpoints and modalities, highlighting how ICP alignment improves geometric consistency relative to the raw
depth while preserving the scene structure visible in the RGB images.

\begin{table}[h]
\centering
\begin{tabular}{
  >{\centering\arraybackslash}m{0.22\textwidth}
  >{\centering\arraybackslash}m{0.22\textwidth}
  >{\centering\arraybackslash}m{0.22\textwidth}
  >{\centering\arraybackslash}m{0.22\textwidth}
}
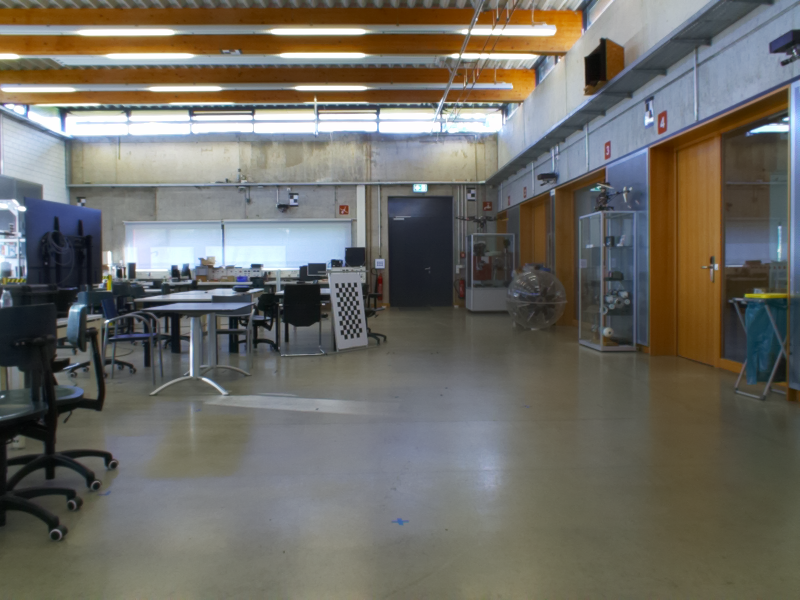
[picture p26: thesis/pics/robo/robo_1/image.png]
     &
     &
     &
     \\
     &
     &
     &
     \\
     &
     &
     &
     \\
     &
     &
     &
     \\
    \end{tabular}
\end{table}

    \section{Uni--Fusion}

    Unfortunately, the generated RGB-D frames could not be evaluated within the Uni--Fusion framework. The 
    installation of the required software environment on the designated workstation encountered persistent 
    technical issues, which prevented a successful deployment of the pipeline. As a result, the integration 
    and direct testing of the data inside Uni--Fusion was not possible within the scope of this thesis. This 
    limitation should be addressed in future work, as a full evaluation within the intended system would 
    provide a more comprehensive assessment of the quality and usability of the reconstructed depth images.

    %\textcolor{red}{\section{Comparison with Commercial Devices}}

    %In order to assess the performance of the developed handheld device, it is essential to place it in 
    %relation to existing commercial systems. A representative industrial benchmark is the SHARE 
    %S20 LiDAR device \cite{shareS20}, which is offered at a price of approximately 5600~EUR. The S20 
    %provides high accuracy and robustness, making it suitable for professional surveying and industrial 
    %applications. However, the cost of such systems can be prohibitive for many use cases that require 
    %flexibility and affordability, such as rapid prototyping, small-scale cultural heritage projects, 
    %or educational environments. 
%
    %By contrast, the handheld prototype developed in this thesis is based on a low-cost Livox LiDAR 
    %sensor combined with a monocular RGB camera, resulting in a system that can be realized for only a 
    %fraction of the price. While the industrial device achieves superior range and precision, the 
    %prototype demonstrates that competitive results can be obtained with significantly lower hardware 
    %investment. This comparison highlights the potential of low-cost alternatives for practical outdoor 
    %scenarios, where budget limitations often restrict access to high-end equipment. The evaluation thus 
    %underscores the relevance of designing cost-efficient yet reliable RGB-D fusion systems, which can 
    %expand accessibility and enable broader adoption in research and industry.
%
%
    %Table shows that the complete bill of materials amounts to approximately 1{,}327\,€.
    %In other words, the proposed prototype is a genuinely \emph{low-cost} device: compared to an integrated
    %off-the-shelf SLAM sensor such as a SHARE~20 SLAM (ca.\ 5{,}000\,€), the total acquisition cost is
    %about $\approx 3.8\times$ lower, corresponding to a reduction of roughly $\sim 73\%$. Despite the Livox
    %Mid70 being the largest single expense (900\,€), the remainder of the system is built from commodity
    %components (Raspberry~Pi~5 with accessories, low-cost camera module and optics, IMU, and peripherals),
    %which keeps the overall budget modest. This cost profile makes the platform attractive for student projects
    %or small research labs. All prices are approximate and
    %reflect typical market variability at the time of purchase.

\chapter{Conclusion and future work}

The developed handheld scanning system, which is based on a Raspberry Pi~5 in combination with the 
Livox Mid--70 LiDAR sensor, has been successfully implemented and evaluated in the course of this work. 
The data acquisition using the integrated touchscreen operates reliably and provides 
a way of starting and managing the recording process. Furthermore, the subsequent data organization and storage 
follows the structured scheme described in section~\ref{sec:approach}, which ensures that the different 
sensor modalities are consistently aligned in a reproducible file hierarchy. This facilitates both later 
processing and the integration into external frameworks. Nevertheless, several limitations became evident 
during the experiments. One of the most critical aspects is the calibration between the LiDAR sensor and 
the RGB cameras. Inaccuracies in this calibration were clearly observable, for example in the colored 
point clouds (see section \ref{sec:experiments}), where misalignments led to visible distortions and incorrect color assignments. Such errors 
directly affect the quality of the generated data and limit the usability of the results in downstream tasks. 
Another important limitation is related to the inertial measurement unit (IMU). 
Because the Livox Mid--70 has no internal IMU, the external IMU has to get calibrated, which 
was not completed at the time of submission. The imu data is still stored in the output files.
This represents a significant disadvantage, since an accurate 
IMU calibration would considerably improve the performance of scan alignment methods such as Iterative 
Closest Point (ICP) or alternative calibration and registration algorithms. The absence of a factory-calibrated 
IMU is one of the major drawbacks of the Livox hardware, as it complicates the development of a fully 
integrated and robust handheld mapping solution. Despite these shortcomings, the developed software 
pipeline is able to process the recorded data and generate both RGB and depth images.
It remains to be demonstrated whether depth images obtained via interpolation are sufficient for Uni--Fusion.
Should this not hold -- which is plausible when aiming for highly detailed and geometrically faithful reconstructions --
future work ought to consider alternative strategies, such as \emph{ScaleCov} (see section~\ref{sec:sparsedepth}).

The outputs are structured in a way that is compatible with the Uni--Fusion framework.
Although the actual integration and testing within Uni--Fusion could 
not be completed due to technical issues with the target system, the produced results demonstrate that the 
pipeline provides a working foundation.

In summary, despite limited hardware resources and the inherent constraints of the Livox Mid-70, this thesis
demonstrates that a functional, portable and cost-efficient handheld RGB-D scanner can be built around a
Raspberry Pi 5. We designed and assembled the device, integrated a monocular camera with the LiDAR and
established calibration and synchronization procedures, alongside a processing pipeline that produces
depth images and RGB-D outputs suitable for downstream frameworks such as Uni--Fusion. While the present
accuracy is not yet sufficient for high-precision applications, the collected data already provide a sound
basis for further processing and integration. The only objective not completed within the thesis timeframe
was the end-to-end evaluation in Uni--Fusion; future work should finalize the IMU calibration and conduct
a full Uni--Fusion evaluation and benchmarking on
representative datasets. Addressing these points will increase accuracy and reliability and broaden the
system's applicability to practical 3D mapping and multimodal reconstruction scenarios.

\newpage

\appendix
\chapter{Drawings handheld Device}
\label{app:handheld_drawings}
\includepdf[pages=-]{pics/Device Images/Main_Device_Ansichten.pdf}
\includepdf{pics/Device Images/H99_Halterung_Drawing v2.pdf}

% DON'T set \bibliographystyle here -- use the documentclass option instead
\bibliography{papers}
% Make sure all citation keys used in \cite{...} exist in papers.bib

\closing %%%%%%%%%%%%%%%%%%%%%%%%%%%%%%

\end{document}

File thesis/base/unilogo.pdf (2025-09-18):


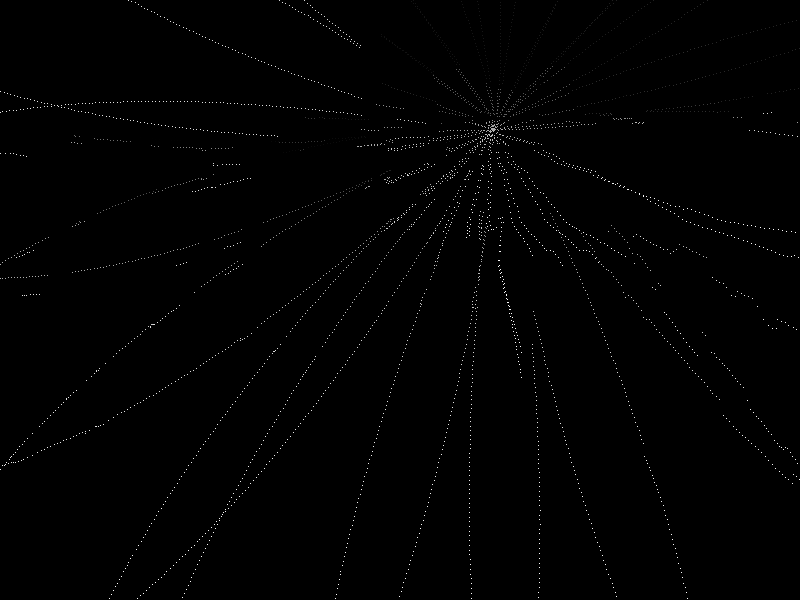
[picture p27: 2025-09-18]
thesis/pics/depth_robohall_no_icp.png

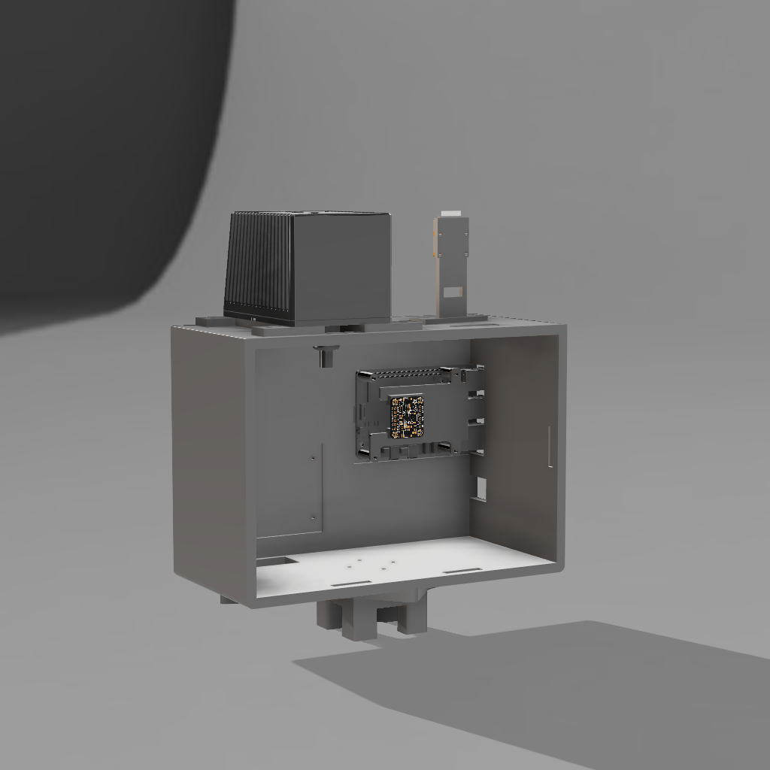
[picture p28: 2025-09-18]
thesis/pics/Device Images/deveice_back_not_transparent.png

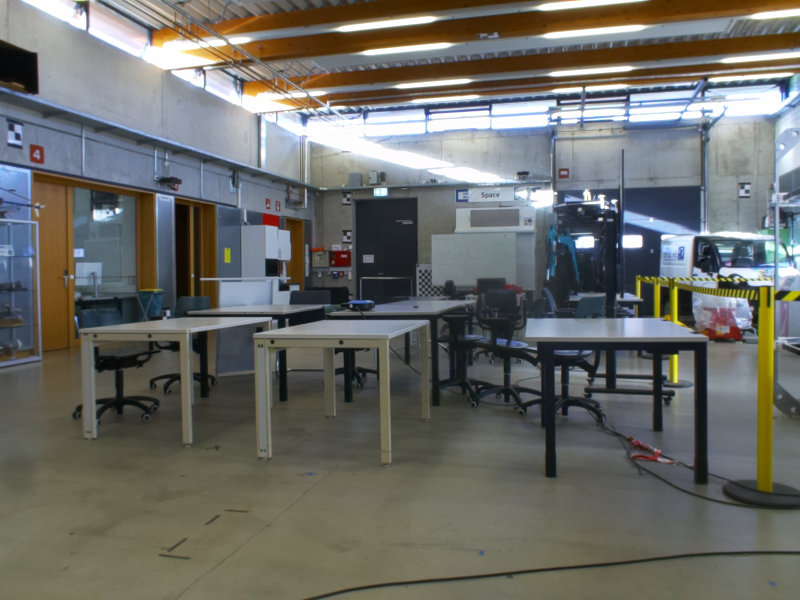
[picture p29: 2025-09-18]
thesis/pics/robo/robo_5/image.png

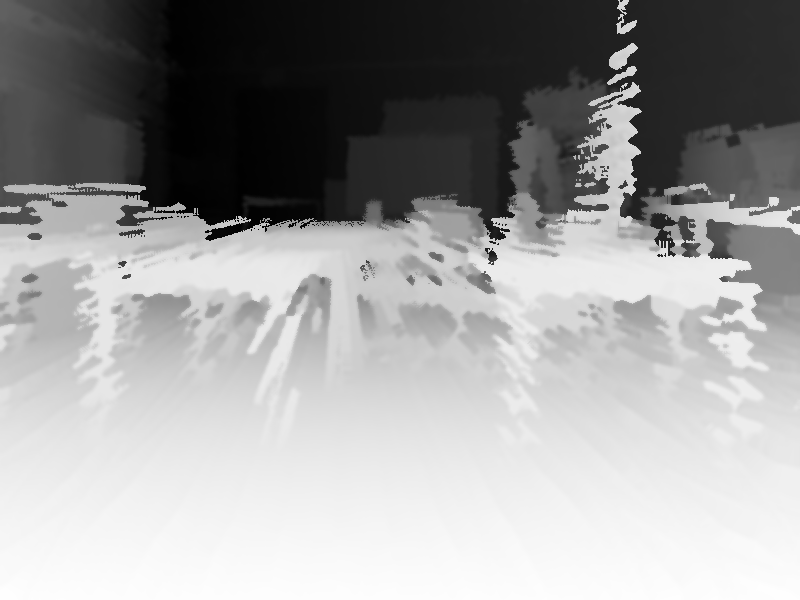
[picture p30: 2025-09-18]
thesis/pics/robo/robo_5/depth0016.png

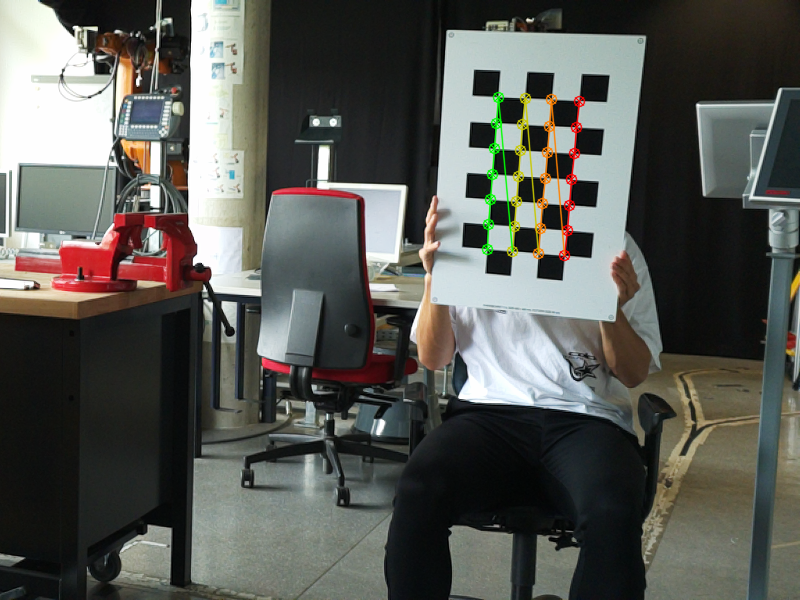
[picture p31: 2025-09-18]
thesis/pics/captured_chessboards/chessboard_001_annotated.png

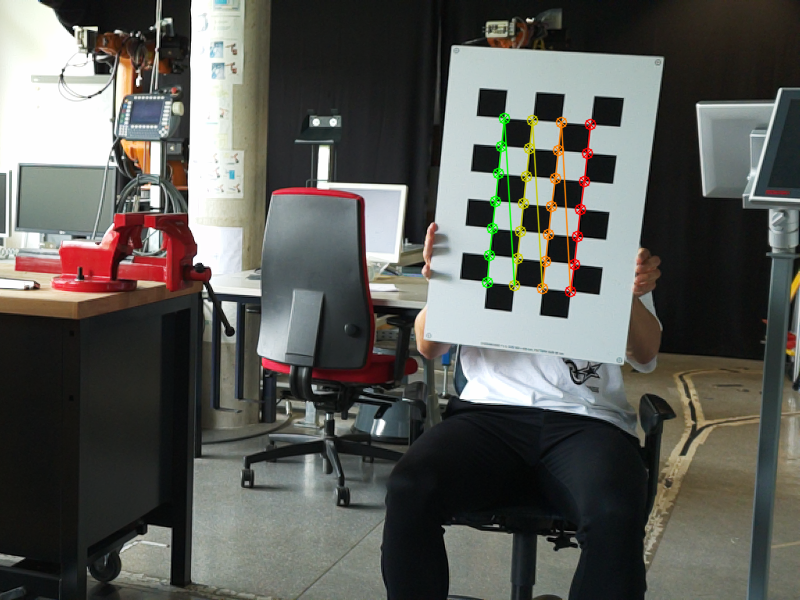
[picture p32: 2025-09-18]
thesis/pics/captured_chessboards/chessboard_004_annotated.png

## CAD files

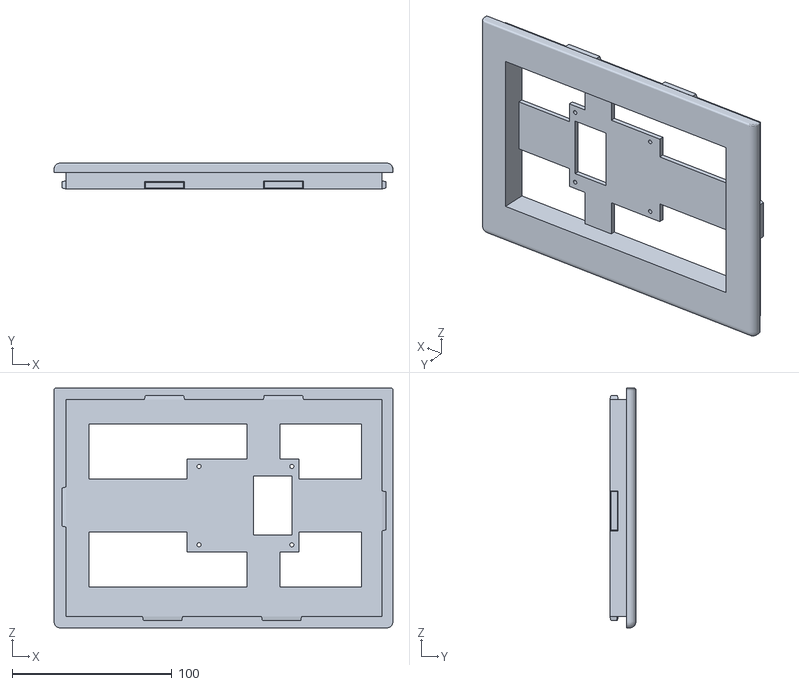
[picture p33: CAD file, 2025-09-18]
stl/Front.stl
212.0 x 16.2 x 150.0

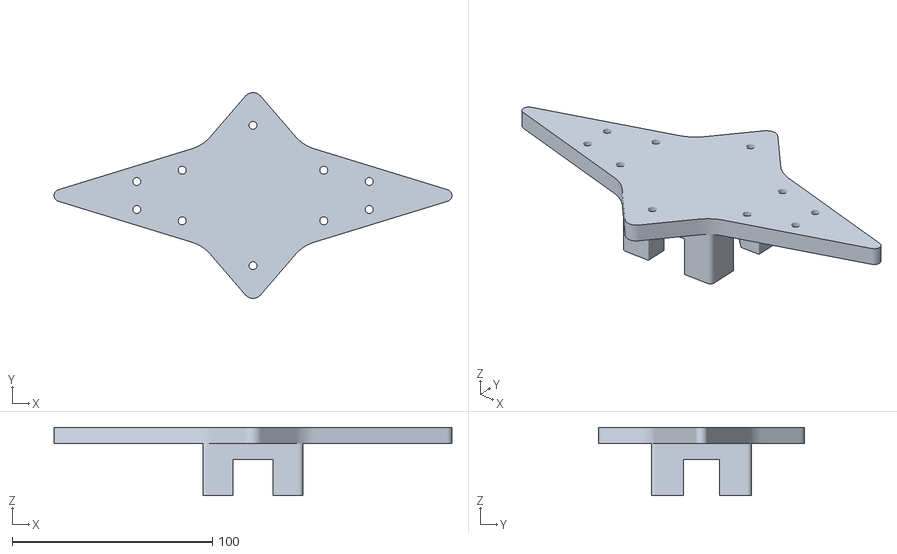
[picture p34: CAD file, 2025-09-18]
stl/BatteryMountingBracket.stl
198.5 x 102.7 x 34.0

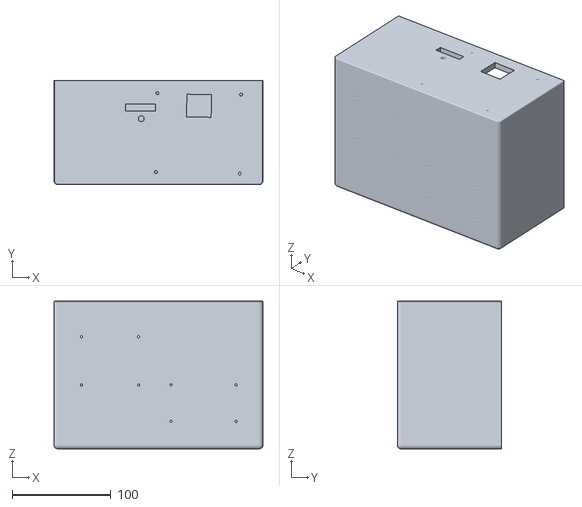
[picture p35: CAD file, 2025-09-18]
stl/Body.stl
212.0 x 106.0 x 150.0

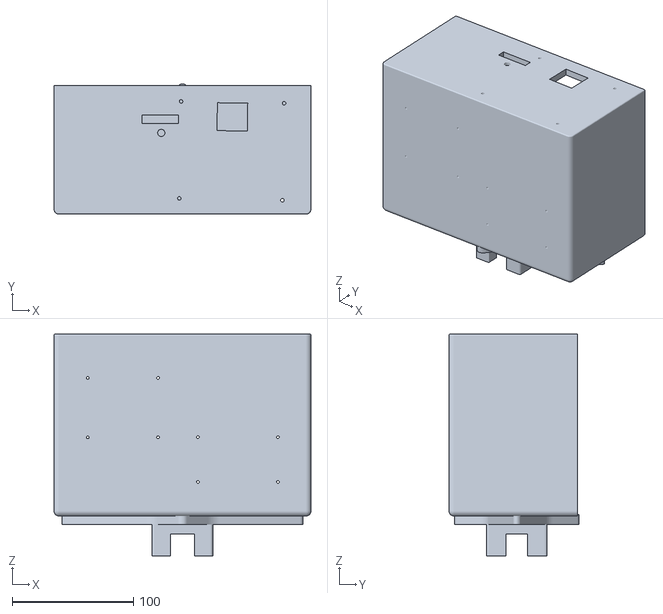
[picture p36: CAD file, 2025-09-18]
stl/Body+BatteryMountingBracket.stl
212.0 x 107.3 x 183.0

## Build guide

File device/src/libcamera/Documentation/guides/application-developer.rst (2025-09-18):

.. SPDX-License-Identifier: CC-BY-SA-4.0

.. include:: ../documentation-contents.rst

Using libcamera in a C++ application
====================================

This tutorial shows how to create a C++ application that uses libcamera to
interface with a camera on a system, capture frames from it for 3 seconds, and
write metadata about the frames to standard output.

Application skeleton
--------------------

Most of the code in this tutorial runs in the ``int main()`` function
with a separate global function to handle events. The two functions need
to share data, which are stored in global variables for simplicity. A
production-ready application would organize the various objects created
in classes, and the event handler would be a class member function to
provide context data without requiring global variables.

Use the following code snippets as the initial application skeleton.
It already lists all the necessary includes directives and instructs the
compiler to use the libcamera namespace, which gives access to the libcamera
defined names and types without the need of prefixing them.

.. code:: cpp

   #include <iomanip>
   #include <iostream>
   #include <memory>
   #include <thread>

   #include <libcamera/libcamera.h>

   using namespace libcamera;
   using namespace std::chrono_literals;

   int main()
   {
       // Code to follow

       return 0;
   }

Camera Manager
--------------

Every libcamera-based application needs an instance of a `CameraManager`_ that
runs for the life of the application. When the Camera Manager starts, it
enumerates all the cameras detected in the system. Behind the scenes, libcamera
abstracts and manages the complex pipelines that kernel drivers expose through
the `Linux Media Controller`_ and `Video for Linux`_ (V4L2) APIs, meaning that
an application doesn't need to handle device or driver specific details.

.. _CameraManager: https://libcamera.org/api-html/classlibcamera_1_1CameraManager.html
.. _Linux Media Controller: https://www.kernel.org/doc/html/latest/media/uapi/mediactl/media-controller-intro.html
.. _Video for Linux: https://www.linuxtv.org/docs.php

Before the ``int main()`` function, create a global shared pointer
variable for the camera to support the event call back later:

.. code:: cpp

   static std::shared_ptr<Camera> camera;

Create a Camera Manager instance at the beginning of the main function, and then
start it. An application must only create a single Camera Manager instance.

The CameraManager can be stored in a unique_ptr to automate deleting the
instance when it is no longer used, but care must be taken to ensure all
cameras are released explicitly before this happens.

.. code:: cpp

   std::unique_ptr<CameraManager> cm = std::make_unique<CameraManager>();
   cm->start();

During the application initialization, the Camera Manager is started to
enumerate all the supported devices and create cameras that the application can
interact with.

Once the camera manager is started, we can use it to iterate the available
cameras in the system:

.. code:: cpp

   for (auto const &camera : cm->cameras())
       std::cout << camera->id() << std::endl;

Printing the camera id lists the machine-readable unique identifiers, so for
example, the output on a Linux machine with a connected USB webcam is
``\_SB_.PCI0.XHC_.RHUB.HS08-8:1.0-5986:2115``.

What libcamera considers a camera
~~~~~~~~~~~~~~~~~~~~~~~~~~~~~~~~~

The libcamera library considers any unique source of video frames, which usually
correspond to a camera sensor, as a single camera device. Camera devices expose
streams, which are obtained by processing data from the single image source and
all share some basic properties such as the frame duration and the image
exposure time, as they only depend by the image source configuration.

Applications select one or multiple Camera devices they wish to operate on, and
require frames from at least one of their Streams.

Create and acquire a camera
---------------------------

This example application uses a single camera (the first enumerated one) that
the Camera Manager reports as available to applications.

Camera devices are stored by the CameraManager in a list accessible by index, or
can be retrieved by name through the ``CameraManager::get()`` function. The
code below retrieves the name of the first available camera and gets the camera
by name from the Camera Manager, after making sure that at least one camera is
available.

.. code:: cpp

   auto cameras = cm->cameras();
   if (cameras.empty()) {
       std::cout << "No cameras were identified on the system."
                 << std::endl;
       cm->stop();
       return EXIT_FAILURE;
   }

   std::string cameraId = cameras[0]->id();

   camera = cm->get(cameraId);
   /*
    * Note that `camera` may not compare equal to `cameras[0]`.
    * In fact, it might simply be a `nullptr`, as the particular
    * device might have disappeared (and reappeared) in the meantime.
    */

Once a camera has been selected an application needs to acquire an exclusive
lock to it so no other application can use it.

.. code:: cpp

   camera->acquire();

Configure the camera
--------------------

Before the application can do anything with the camera, it needs to configure
the image format and sizes of the streams it wants to capture frames from.

Stream configurations are represented by instances of the
``StreamConfiguration`` class, which are grouped together in a
``CameraConfiguration`` object. Before an application can start setting its
desired configuration, a ``CameraConfiguration`` instance needs to be generated
from the ``Camera`` device using the ``Camera::generateConfiguration()``
function.

The libcamera library uses the ``StreamRole`` enumeration to define predefined
ways an application intends to use a camera. The
``Camera::generateConfiguration()`` function accepts a list of desired roles and
generates a ``CameraConfiguration`` with the best stream parameters
configuration for each of the requested roles.  If the camera can handle the
requested roles, it returns an initialized ``CameraConfiguration`` and a null
pointer if it can't.

It is possible for applications to generate an empty ``CameraConfiguration``
instance by not providing any role. The desired configuration will have to be
filled-in manually and manually validated.

In the example application, create a new configuration variable and use the
``Camera::generateConfiguration`` function to produce a ``CameraConfiguration``
for the single ``StreamRole::Viewfinder`` role.

.. code:: cpp

   std::unique_ptr<CameraConfiguration> config = camera->generateConfiguration( { StreamRole::Viewfinder } );

The generated ``CameraConfiguration`` has a ``StreamConfiguration`` instance for
each ``StreamRole`` the application requested. Each of these has a default size
and format that the camera assigned, and a list of supported pixel formats and
sizes.

The code below accesses the first and only ``StreamConfiguration`` item in the
``CameraConfiguration`` and outputs its parameters to standard output.

.. code:: cpp

   StreamConfiguration &streamConfig = config->at(0);
   std::cout << "Default viewfinder configuration is: " << streamConfig.toString() << std::endl;

This is expected to output something like:

   ``Default viewfinder configuration is: 1280x720-MJPEG``

Change and validate the configuration
~~~~~~~~~~~~~~~~~~~~~~~~~~~~~~~~~~~~~

With an initialized ``CameraConfiguration``, an application can make changes to
the parameters it contains, for example, to change the width and height, use the
following code:

.. code:: cpp

   streamConfig.size.width = 640;
   streamConfig.size.height = 480;

If an application changes any parameters, it must validate the configuration
before applying it to the camera using the ``CameraConfiguration::validate()``
function. If the new values are not supported by the ``Camera`` device, the
validation process adjusts the parameters to what it considers to be the closest
supported values.

The ``validate`` function returns a `Status`_ which applications shall check to
see if the Pipeline Handler adjusted the configuration.

.. _Status: https://libcamera.org/api-html/classlibcamera_1_1CameraConfiguration.html#a64163f21db2fe1ce0a6af5a6f6847744

For example, the code above set the width and height to 640x480, but if the
camera cannot produce an image that large, it might adjust the configuration to
the supported size of 320x240 and return ``Adjusted`` as validation status
result.

If the configuration to validate cannot be adjusted to a set of supported
values, the validation procedure fails and returns the ``Invalid`` status.

For this example application, the code below prints the adjusted values to
standard out.

.. code:: cpp

   config->validate();
   std::cout << "Validated viewfinder configuration is: " << streamConfig.toString() << std::endl;

For example, the output might be something like

   ``Validated viewfinder configuration is: 320x240-MJPEG``

A validated ``CameraConfiguration`` can bet given to the ``Camera`` device to be
applied to the system.

.. code:: cpp

   camera->configure(config.get());

If an application doesn't first validate the configuration before calling
``Camera::configure()``, there's a chance that calling the function can fail, if
the given configuration would have to be adjusted.

Allocate FrameBuffers
---------------------

An application needs to reserve the memory that libcamera can write incoming
frames and data to, and that the application can then read. The libcamera
library uses ``FrameBuffer`` instances to represent memory buffers allocated in
memory. An application should reserve enough memory for the frame size the
streams need based on the configured image sizes and formats.

The libcamera library consumes buffers provided by applications as
``FrameBuffer`` instances, which makes libcamera a consumer of buffers exported
by other devices (such as displays or video encoders), or allocated from an
external allocator (such as ION on Android).

In some situations, applications do not have any means to allocate or get hold
of suitable buffers, for instance, when no other device is involved, or on Linux
platforms that lack a centralized allocator. The ``FrameBufferAllocator`` class
provides a buffer allocator an application can use in these situations.

An application doesn't have to use the default ``FrameBufferAllocator`` that
libcamera provides. It can instead allocate memory manually and pass the buffers
in ``Request``\s (read more about ``Request`` in `the frame capture section
<#frame-capture>`_ of this guide). The example in this guide covers using the
``FrameBufferAllocator`` that libcamera provides.

Using the libcamera ``FrameBufferAllocator``
~~~~~~~~~~~~~~~~~~~~~~~~~~~~~~~~~~~~~~~~~~~~

Applications create a ``FrameBufferAllocator`` for a Camera and use it
to allocate buffers for streams of a ``CameraConfiguration`` with the
``allocate()`` function.

The list of allocated buffers can be retrieved using the ``Stream`` instance
as the parameter of the ``FrameBufferAllocator::buffers()`` function.

.. code:: cpp

   FrameBufferAllocator *allocator = new FrameBufferAllocator(camera);

   for (StreamConfiguration &cfg : *config) {
       int ret = allocator->allocate(cfg.stream());
       if (ret < 0) {
           std::cerr << "Can't allocate buffers" << std::endl;
           return -ENOMEM;
       }

       size_t allocated = allocator->buffers(cfg.stream()).size();
       std::cout << "Allocated " << allocated << " buffers for stream" << std::endl;
   }

Frame Capture
~~~~~~~~~~~~~

The libcamera library implements a streaming model based on per-frame requests.
For each frame an application wants to capture it must queue a request for it to
the camera. With libcamera, a ``Request`` is at least one ``Stream`` associated
with a ``FrameBuffer`` representing the memory location where frames have to be
stored.

First, by using the ``Stream`` instance associated to each
``StreamConfiguration``, retrieve the list of ``FrameBuffer``\s created for it
using the frame allocator. Then create a vector of requests to be submitted to
the camera.

.. code:: cpp

   Stream *stream = streamConfig.stream();
   const std::vector<std::unique_ptr<FrameBuffer>> &buffers = allocator->buffers(stream);
   std::vector<std::unique_ptr<Request>> requests;

Proceed to fill the request vector by creating ``Request`` instances from the
camera device, and associate a buffer for each of them for the ``Stream``.

.. code:: cpp

       for (unsigned int i = 0; i < buffers.size(); ++i) {
           std::unique_ptr<Request> request = camera->createRequest();
           if (!request)
           {
               std::cerr << "Can't create request" << std::endl;
               return -ENOMEM;
           }

           const std::unique_ptr<FrameBuffer> &buffer = buffers[i];
           int ret = request->addBuffer(stream, buffer.get());
           if (ret < 0)
           {
               std::cerr << "Can't set buffer for request"
                     << std::endl;
               return ret;
           }

           requests.push_back(std::move(request));
       }

.. TODO: Controls

.. TODO: A request can also have controls or parameters that you can apply to the image.

Event handling and callbacks
----------------------------

The libcamera library uses the concept of `signals and slots` (similar to `Qt
Signals and Slots`_) to connect events with callbacks to handle them.

.. _signals and slots: https://libcamera.org/api-html/classlibcamera_1_1Signal.html#details
.. _Qt Signals and Slots: https://doc.qt.io/qt-6/signalsandslots.html

The ``Camera`` device emits two signals that applications can connect to in
order to execute callbacks on frame completion events.

The ``Camera::bufferCompleted`` signal notifies applications that a buffer with
image data is available. Receiving notifications about the single buffer
completion event allows applications to implement partial request completion
support, and to inspect the buffer content before the request it is part of has
fully completed.

The ``Camera::requestCompleted`` signal notifies applications that a request
has completed, which means all the buffers the request contains have now
completed. Request completion notifications are always emitted in the same order
as the requests have been queued to the camera.

To receive the signals emission notifications, connect a slot function to the
signal to handle it in the application code.

.. code:: cpp

   camera->requestCompleted.connect(requestComplete);

For this example application, only the ``Camera::requestCompleted`` signal gets
handled and the matching ``requestComplete`` slot function outputs information
about the FrameBuffer to standard output. This callback is typically where an
application accesses the image data from the camera and does something with it.

Signals operate in the libcamera ``CameraManager`` thread context, so it is
important not to block the thread for a long time, as this blocks internal
processing of the camera pipelines, and can affect realtime performance.

Handle request completion events
~~~~~~~~~~~~~~~~~~~~~~~~~~~~~~~~

Create the ``requestComplete`` function by matching the slot signature:

.. code:: cpp

   static void requestComplete(Request *request)
   {
       // Code to follow
   }

Request completion events can be emitted for requests which have been canceled,
for example, by unexpected application shutdown. To avoid an application
processing invalid image data, it's worth checking that the request has
completed successfully. The list of request completion statuses is available in
the `Request::Status`_ class enum documentation.

.. _Request::Status: https://www.libcamera.org/api-html/classlibcamera_1_1Request.html#a2209ba8d51af8167b25f6e3e94d5c45b

.. code:: cpp

   if (request->status() == Request::RequestCancelled)
      return;

If the ``Request`` has completed successfully, applications can access the
completed buffers using the ``Request::buffers()`` function, which returns a map
of ``FrameBuffer`` instances associated with the ``Stream`` that produced the
images.

.. code:: cpp

   const std::map<const Stream *, FrameBuffer *> &buffers = request->buffers();

Iterating through the map allows applications to inspect each completed buffer
in this request, and access the metadata associated to each frame.

The metadata buffer contains information such the capture status, a timestamp,
and the bytes used, as described in the `FrameMetadata`_ documentation.

.. _FrameMetaData: https://libcamera.org/api-html/structlibcamera_1_1FrameMetadata.html

.. code:: cpp

   for (auto bufferPair : buffers) {
       FrameBuffer *buffer = bufferPair.second;
       const FrameMetadata &metadata = buffer->metadata();
   }

For this example application, inside the ``for`` loop from above, we can print
the Frame sequence number and details of the planes.

.. code:: cpp

   std::cout << " seq: " << std::setw(6) << std::setfill('0') << metadata.sequence << " bytesused: ";

   unsigned int nplane = 0;
   for (const FrameMetadata::Plane &plane : metadata.planes())
   {
       std::cout << plane.bytesused;
       if (++nplane < metadata.planes().size()) std::cout << "/";
   }

   std::cout << std::endl;

The expected output shows each monotonically increasing frame sequence number
and the bytes used by planes.

.. code:: text

   seq: 000000 bytesused: 1843200
   seq: 000002 bytesused: 1843200
   seq: 000004 bytesused: 1843200
   seq: 000006 bytesused: 1843200
   seq: 000008 bytesused: 1843200
   seq: 000010 bytesused: 1843200
   seq: 000012 bytesused: 1843200
   seq: 000014 bytesused: 1843200
   seq: 000016 bytesused: 1843200
   seq: 000018 bytesused: 1843200
   seq: 000020 bytesused: 1843200
   seq: 000022 bytesused: 1843200
   seq: 000024 bytesused: 1843200
   seq: 000026 bytesused: 1843200
   seq: 000028 bytesused: 1843200
   seq: 000030 bytesused: 1843200
   seq: 000032 bytesused: 1843200
   seq: 000034 bytesused: 1843200
   seq: 000036 bytesused: 1843200
   seq: 000038 bytesused: 1843200
   seq: 000040 bytesused: 1843200
   seq: 000042 bytesused: 1843200

A completed buffer contains of course image data which can be accessed through
the per-plane dma-buf file descriptor transported by the ``FrameBuffer``
instance. An example of how to write image data to disk is available in the
`FileSink class`_ which is a part of the ``cam`` utility application in the
libcamera repository.

.. _FileSink class: https://git.libcamera.org/libcamera/libcamera.git/tree/src/apps/cam/file_sink.cpp

With the handling of this request completed, it is possible to re-use the
request and the associated buffers and re-queue it to the camera
device:

.. code:: cpp

   request->reuse(Request::ReuseBuffers);
   camera->queueRequest(request);

Request queueing
----------------

The ``Camera`` device is now ready to receive frame capture requests and
actually start delivering frames. In order to prepare for that, an application
needs to first start the camera, and queue requests to it for them to be
processed.

In the main() function, just after having connected the
``Camera::requestCompleted`` signal to the callback handler, start the camera
and queue all the previously created requests.

.. code:: cpp

   camera->start();
   for (std::unique_ptr<Request> &request : requests)
      camera->queueRequest(request.get());

Event processing
~~~~~~~~~~~~~~~~

libcamera creates an internal execution thread at `CameraManager::start()`_
time to decouple its own event processing from the application's main thread.
Applications are thus free to manage their own execution opportunely, and only
need to respond to events generated by libcamera emitted through signals.

.. _CameraManager::start(): https://libcamera.org/api-html/classlibcamera_1_1CameraManager.html#a49e322880a2a26013bb0076788b298c5

Real-world applications will likely either integrate with the event loop of the
framework they use, or create their own event loop to respond to user events.
For the simple application presented in this example, it is enough to prevent
immediate termination by pausing for 3 seconds. During that time, the libcamera
thread will generate request completion events that the application will handle
in the ``requestComplete()`` slot connected to the ``Camera::requestCompleted``
signal.

.. code:: cpp

   std::this_thread::sleep_for(3000ms);

Clean up and stop the application
---------------------------------

The application is now finished with the camera and the resources the camera
uses, so needs to do the following:

-  stop the camera
-  free the buffers in the FrameBufferAllocator and delete it
-  release the lock on the camera and reset the pointer to it
-  stop the camera manager

.. code:: cpp

   camera->stop();
   allocator->free(stream);
   delete allocator;
   camera->release();
   camera.reset();
   cm->stop();

   return 0;

In this instance the CameraManager will automatically be deleted by the
unique_ptr implementation when it goes out of scope.

Build and run instructions
--------------------------

To build the application, we recommend that you use the `Meson build system`_
which is also the official build system of the libcamera library.

Make sure both ``meson`` and ``libcamera`` are installed in your system. Please
refer to your distribution documentation to install meson and install the most
recent version of libcamera from the `git repository`_. You would also need to
install the ``pkg-config`` tool to correctly identify the libcamera.so object
install location in the system.

.. _Meson build system: https://mesonbuild.com/
.. _git repository: https://git.libcamera.org/libcamera/libcamera.git/

Dependencies
~~~~~~~~~~~~

The test application presented here depends on the libcamera library to be
available in a path that meson can identify. The libcamera install procedure
performed using the ``ninja install`` command may by default deploy the
libcamera components in the ``/usr/local/lib`` path, or a package manager may
install it to ``/usr/lib`` depending on your distribution. If meson is unable to
find the location of the libcamera installation, you may need to instruct meson
to look into a specific path when searching for ``libcamera.so`` by setting the
``PKG_CONFIG_PATH`` environment variable to the right location.

Adjust the following command to use the ``pkgconfig`` directory where libcamera
has been installed in your system.

.. code:: shell

   export PKG_CONFIG_PATH=/usr/local/lib/pkgconfig/

Verify that ``pkg-config`` can identify the ``libcamera`` library with

.. code:: shell

   $ pkg-config --libs --cflags libcamera
     -I/usr/local/include/libcamera -L/usr/local/lib -lcamera -lcamera-base

``meson`` can alternatively use ``cmake`` to locate packages, please refer to
the ``meson`` documentation if you prefer to use it in place of ``pkgconfig``

Build file
~~~~~~~~~~

With the dependencies correctly identified, prepare a ``meson.build`` build file
to be placed in the same directory where the application lives. You can
name your application as you like, but be sure to update the following snippet
accordingly. In this example, the application file has been named
``simple-cam.cpp``.

.. code::

   project('simple-cam', 'cpp')

   simple_cam = executable('simple-cam',
       'simple-cam.cpp',
       dependencies: dependency('libcamera', required : true))

The ``dependencies`` line instructs meson to ask ``pkgconfig`` (or ``cmake``) to
locate the ``libcamera`` library,  which the test application will be
dynamically linked against.

With the build file in place, compile and run the application with:

.. code:: shell

   $ meson build
   $ cd build
   $ ninja
   $ ./simple-cam

It is possible to increase the library debug output by using environment
variables which control the library log filtering system:

.. code:: shell

   $ LIBCAMERA_LOG_LEVELS=0 ./simple-cam

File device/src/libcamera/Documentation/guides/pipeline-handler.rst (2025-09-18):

.. SPDX-License-Identifier: CC-BY-SA-4.0

.. include:: ../documentation-contents.rst

Pipeline Handler Writers Guide
==============================

Pipeline handlers are the abstraction layer for device-specific hardware
configuration. They access and control hardware through the V4L2 and Media
Controller kernel interfaces, and implement an internal API to control the ISP
and capture components of a pipeline directly.

Prerequisite knowledge: system architecture
-------------------------------------------

A pipeline handler configures and manages the image acquisition and
transformation pipeline realized by specialized system peripherals combined with
an image source connected to the system through a data and control bus. The
presence, number and characteristics of them vary depending on the system design
and the product integration of the target platform.

System components can be classified in three macro-categories:

.. TODO: Insert references to the open CSI-2 (and other) specification.

- Input ports: Interfaces to external devices, usually image sensors,
  which transfer data from the physical bus to locations accessible by other
  system peripherals. An input port needs to be configured according to the
  input image format and size and could optionally apply basic transformations
  on the received images, most typically cropping/scaling and some formats
  conversion. The industry standard for the system typically targeted by
  libcamera is to have receivers compliant with the MIPI CSI-2 specifications,
  implemented on a compatible physical layer such as MIPI D-PHY or MIPI C-PHY.
  Other design are possible but less common, such as LVDS or the legacy BT.601
  and BT.656 parallel protocols.

- Image Signal Processor (ISP): A specialized media processor which applies
  digital transformations on image streams. ISPs can be integrated as part of
  the SoC as a memory interfaced system peripheral or packaged as stand-alone
  chips connected to the application processor through a bus. Most hardware used
  by libcamera makes use of in-system ISP designs but pipelines can equally
  support external ISP chips or be instrumented to use other system resources
  such as a GPU or an FPGA IP block. ISPs expose a software programming
  interface that allows the configuration of multiple processing blocks which
  form an "Image Transformation Pipeline". An ISP usually produces 'processed'
  image streams along with the metadata describing the processing steps which
  have been applied to generate the output frames.

- Camera Sensor: Digital components that integrate an image sensor with control
  electronics and usually a lens. It interfaces to the SoC image receiver ports
  and is programmed to produce images in a format and size suitable for the
  current system configuration. Complex camera modules can integrate on-board
  ISP or DSP chips and process images before delivering them to the system. Most
  systems with a dedicated ISP processor will usually integrate camera sensors
  which produce images in Raw Bayer format and defer processing to it.

It is the responsibility of the pipeline handler to interface with these (and
possibly other) components of the system and implement the following
functionalities:

- Detect and register camera devices available in the system with an associated
  set of image streams.

- Configure the image acquisition and processing pipeline by assigning the
  system resources (memory, shared components, etc.) to satisfy the
  configuration requested by the application.

- Start and stop the image acquisition and processing sessions.

- Apply configuration settings requested by applications and computed by image
  processing algorithms integrated in libcamera to the hardware devices.

- Notify applications of the availability of new images and deliver them to the
  correct locations.

Prerequisite knowledge: libcamera architecture
----------------------------------------------

A pipeline handler makes use of the following libcamera classes to realize the
functionalities described above. Below is a brief overview of each of those:

.. TODO: (All) Convert to sphinx refs
.. TODO: (MediaDevice) Reference to the Media Device API (possibly with versioning requirements)
.. TODO: (IPAInterface) refer to the IPA guide

-  `MediaDevice <https://libcamera.org/api-html/classlibcamera_1_1MediaDevice.html>`_:
   Instances of this class are associated with a kernel media controller
   device and its connected objects.

-  `DeviceEnumerator <https://libcamera.org/api-html/classlibcamera_1_1DeviceEnumerator.html>`_:
   Enumerates all media devices attached to the system and the media entities
   registered with it, by creating instances of the ``MediaDevice`` class and
   storing them.

-  `DeviceMatch <https://libcamera.org/api-html/classlibcamera_1_1DeviceMatch.html>`_:
   Describes a media device search pattern using entity names, or other
   properties.

-  `V4L2VideoDevice <https://libcamera.org/api-html/classlibcamera_1_1V4L2VideoDevice.html>`_:
   Models an instance of a V4L2 video device constructed with the path to a V4L2
   video device node.

-  `V4L2SubDevice <https://libcamera.org/api-html/classlibcamera_1_1V4L2Subdevice.html>`_:
   Provides an API to the sub-devices that model the hardware components of a
   V4L2 device.

-  `CameraSensor <https://libcamera.org/api-html/classlibcamera_1_1CameraSensor.html>`_:
   Abstracts camera sensor handling by hiding the details of the V4L2 subdevice
   kernel API and caching sensor information.

-  `Camera::Private <https://libcamera.org/api-html/classlibcamera_1_1Camera_1_1Private.html>`_:
   Represents device-specific data a pipeline handler associates to each Camera
   instance.

-  `StreamConfiguration <https://libcamera.org/api-html/structlibcamera_1_1StreamConfiguration.html>`_:
   Models the current configuration of an image stream produced by the camera by
   reporting its format and sizes.

-  `CameraConfiguration <https://libcamera.org/api-html/classlibcamera_1_1CameraConfiguration.html>`_:
   Represents the current configuration of a camera, which includes a list of
   stream configurations for each active stream in a capture session. When
   validated, it is applied to the camera.

-  `IPAInterface <https://libcamera.org/api-html/classlibcamera_1_1IPAInterface.html>`_:
   The interface to the Image Processing Algorithm (IPA) module which performs
   the computation of the image processing pipeline tuning parameters.

-  `ControlList <https://libcamera.org/api-html/classlibcamera_1_1ControlList.html>`_:
   A list of control items, indexed by Control<> instances or by numerical index
   which contains values used by application and IPA to change parameters of
   image streams, used to return to applications and share with IPA the metadata
   associated with the captured images, and to advertise the immutable camera
   characteristics enumerated at system initialization time.

Creating a PipelineHandler
--------------------------

This guide walks through the steps to create a simple pipeline handler
called “Vivid” that supports the `V4L2 Virtual Video Test Driver`_ (vivid).

To use the vivid test driver, you first need to check that the vivid kernel
module is loaded, for example with the ``modprobe vivid`` command.

.. _V4L2 Virtual Video Test Driver: https://www.kernel.org/doc/html/latest/admin-guide/media/vivid.html

Create the skeleton file structure
~~~~~~~~~~~~~~~~~~~~~~~~~~~~~~~~~~

To add a new pipeline handler, create a directory to hold the pipeline code in
the *src/libcamera/pipeline/* directory that matches the name of the pipeline
(in this case *vivid*). Inside the new directory add a *meson.build* file that
integrates with the libcamera build system, and a *vivid.cpp* file that matches
the name of the pipeline.

In the *meson.build* file, add the *vivid.cpp* file as a build source for
libcamera by adding it to the global meson ``libcamera_internal_sources``
variable:

.. code-block:: none

   # SPDX-License-Identifier: CC0-1.0

   libcamera_internal_sources += files([
       'vivid.cpp',
   ])

Users of libcamera can selectively enable pipelines while building libcamera
using the ``pipelines`` option.

For example, to enable only the IPU3, UVC, and VIVID pipelines, specify them as
a comma separated list with ``-Dpipelines`` when generating a build directory:

.. code-block:: shell

    meson build -Dpipelines=ipu3,uvcvideo,vivid

Read the `Meson build configuration`_ documentation for more information on
configuring a build directory.

.. _Meson build configuration: https://mesonbuild.com/Configuring-a-build-directory.html

To add the new pipeline handler to this list of options, add its directory name
to the libcamera build options in the top level ``meson_options.txt``.

.. code-block:: none

   option('pipelines',
           type : 'array',
           choices : ['ipu3', 'rkisp1', 'rpi/pisp', 'rpi/vc4', 'simple', 'uvcvideo', 'vimc', 'vivid'],
           description : 'Select which pipeline handlers to include')

In *vivid.cpp* add the pipeline handler to the ``libcamera`` namespace, defining
a `PipelineHandler`_ derived class named PipelineHandlerVivid, and add stub
implementations for the overridden class members.

.. _PipelineHandler: https://libcamera.org/api-html/classlibcamera_1_1PipelineHandler.html

.. code-block:: cpp

   namespace libcamera {

   class PipelineHandlerVivid : public PipelineHandler
   {
   public:
          PipelineHandlerVivid(CameraManager *manager);

          CameraConfiguration *generateConfiguration(Camera *camera,
          Span<const StreamRole> roles) override;
          int configure(Camera *camera, CameraConfiguration *config) override;

          int exportFrameBuffers(Camera *camera, Stream *stream,
          std::vector<std::unique_ptr<FrameBuffer>> *buffers) override;

          int start(Camera *camera, const ControlList *controls) override;
          void stop(Camera *camera) override;

          int queueRequestDevice(Camera *camera, Request *request) override;

          bool match(DeviceEnumerator *enumerator) override;
   };

   PipelineHandlerVivid::PipelineHandlerVivid(CameraManager *manager)
          : PipelineHandler(manager)
   {
   }

   CameraConfiguration *PipelineHandlerVivid::generateConfiguration(Camera *camera,
                                                                    Span<const StreamRole> roles)
   {
          return nullptr;
   }

   int PipelineHandlerVivid::configure(Camera *camera, CameraConfiguration *config)
   {
          return -1;
   }

   int PipelineHandlerVivid::exportFrameBuffers(Camera *camera, Stream *stream,
                                                std::vector<std::unique_ptr<FrameBuffer>> *buffers)
   {
          return -1;
   }

   int PipelineHandlerVivid::start(Camera *camera, const ControlList *controls)
   {
          return -1;
   }

   void PipelineHandlerVivid::stop(Camera *camera)
   {
   }

   int PipelineHandlerVivid::queueRequestDevice(Camera *camera, Request *request)
   {
          return -1;
   }

   bool PipelineHandlerVivid::match(DeviceEnumerator *enumerator)
   {
          return false;
   }

   REGISTER_PIPELINE_HANDLER(PipelineHandlerVivid, "vivid")

   } /* namespace libcamera */

Note that you must register the ``PipelineHandler`` subclass with the pipeline
handler factory using the `REGISTER_PIPELINE_HANDLER`_ macro which
registers it and creates a global symbol to reference the class and make it
available to try and match devices.
String "vivid" is the name assigned to the pipeline, matching the pipeline
subdirectory name in the source tree.

.. _REGISTER_PIPELINE_HANDLER: https://libcamera.org/api-html/pipeline__handler_8h.html

For debugging and testing a pipeline handler during development, you can define
a log message category for the pipeline handler. The ``LOG_DEFINE_CATEGORY``
macro and ``LIBCAMERA_LOG_LEVELS`` environment variable help you use the inbuilt
libcamera `logging infrastructure`_ that allow for the inspection of internal
operations in a user-configurable way.

.. _logging infrastructure: https://libcamera.org/api-html/log_8h.html

Add the following before the ``PipelineHandlerVivid`` class declaration:

.. code-block:: cpp

   LOG_DEFINE_CATEGORY(VIVID)

At this point you need the following includes for logging and pipeline handler
features:

.. code-block:: cpp

   #include <libcamera/base/log.h>

   #include "libcamera/internal/pipeline_handler.h"

Run the following commands:

.. code-block:: shell

   meson build
   ninja -C build

To build the libcamera code base, and confirm that the build system found the
new pipeline handler by running:

.. code-block:: shell

   LIBCAMERA_LOG_LEVELS=Camera:0 ./build/src/cam/cam -l

And you should see output like the below:

.. code-block:: shell

    DEBUG Camera camera_manager.cpp:148 Found registered pipeline handler 'PipelineHandlerVivid'

Matching devices
~~~~~~~~~~~~~~~~

Each pipeline handler registered in libcamera gets tested against the current
system configuration, by matching a ``DeviceMatch`` with the system
``DeviceEnumerator``. A successful match makes sure all the requested components
have been registered in the system and allows the pipeline handler to be
initialized.

The main entry point of a pipeline handler is the `match()`_ class member
function. When the ``CameraManager`` is started (using the `start()`_ function),
all the registered pipeline handlers are iterated and their ``match`` function
called with an enumerator of all devices it found on a system.

The match function should identify if there are suitable devices available in
the ``DeviceEnumerator`` which the pipeline supports, returning ``true`` if it
matches a device, and ``false`` if it does not. To do this, construct a
`DeviceMatch`_ class with the name of the ``MediaController`` device to match.
You can specify the search further by adding specific media entities to the
search using the ``.add()`` function on the DeviceMatch.

.. _match(): https://www.libcamera.org/api-html/classlibcamera_1_1PipelineHandler.html#a7cd5b652a2414b543ec20ba9dabf61b6
.. _start(): https://libcamera.org/api-html/classlibcamera_1_1CameraManager.html#a49e322880a2a26013bb0076788b298c5
.. _DeviceMatch: https://libcamera.org/api-html/classlibcamera_1_1DeviceMatch.html

This example uses search patterns that match vivid, but when developing a new
pipeline handler, you should change this value to suit your device identifier.

Replace the contents of the ``PipelineHandlerVivid::match`` function with the
following:

.. code-block:: cpp

   DeviceMatch dm("vivid");
   dm.add("vivid-000-vid-cap");
   return false; // Prevent infinite loops for now

With the device matching criteria defined, attempt to acquire exclusive access
to the matching media controller device with the `acquireMediaDevice`_ function.
If the function attempts to acquire a device it has already matched, it returns
``false``.

.. _acquireMediaDevice: https://libcamera.org/api-html/classlibcamera_1_1PipelineHandler.html#a77e424fe704e7b26094164b9189e0f84

Add the following below ``dm.add("vivid-000-vid-cap");``:

.. code-block:: cpp

   MediaDevice *media = acquireMediaDevice(enumerator, dm);
   if (!media)
           return false;

The pipeline handler now needs an additional include. Add the following to the
existing include block for device enumeration functionality:

.. code-block:: cpp

   #include "libcamera/internal/device_enumerator.h"

At this stage, you should test that the pipeline handler can successfully match
the devices, but have not yet added any code to create a Camera which libcamera
reports to applications.

As a temporary validation step, add a debug print with

.. code-block:: cpp

   LOG(VIVID, Debug) << "Vivid Device Identified";

before the final closing return statement in the ``PipelineHandlerVivid::match``
function for when when the pipeline handler successfully matches the
``MediaDevice`` and ``MediaEntity`` names.

Test that the pipeline handler matches and finds a device by rebuilding, and
running

.. code-block:: shell

   ninja -C build
   LIBCAMERA_LOG_LEVELS=Pipeline,VIVID:0 ./build/src/cam/cam -l

And you should see output like the below:

.. code-block:: shell

    DEBUG VIVID vivid.cpp:74 Vivid Device Identified

Creating camera devices
~~~~~~~~~~~~~~~~~~~~~~~

If the pipeline handler successfully matches with the system it is running on,
it can proceed to initialization, by creating all the required instances of the
``V4L2VideoDevice``, ``V4L2Subdevice`` and ``CameraSensor`` hardware abstraction
classes. If the Pipeline handler supports an ISP, it can then also initialise
the IPA module before proceeding to the creation of the Camera devices.

An image ``Stream`` represents a sequence of images and data of known size and
format, stored in application-accessible memory locations. Typical examples of
streams are the ISP processed outputs and the raw images captured at the
receivers port output.

The Pipeline Handler is responsible for defining the set of Streams associated
with the Camera.

Each Camera has instance-specific data represented using the `Camera::Private`_
class, which can be extended for the specific needs of the pipeline handler.

.. _Camera::Private: https://libcamera.org/api-html/classlibcamera_1_1Camera_1_1Private.html

To support the Camera we will later register, we need to create a Camera::Private
class that we can implement for our specific Pipeline Handler.

Define a new ``VividCameraPrivate()`` class derived from ``Camera::Private`` by
adding the following code before the PipelineHandlerVivid class definition where
it will be used:

.. code-block:: cpp

   class VividCameraData : public Camera::Private
   {
   public:
          VividCameraData(PipelineHandler *pipe, MediaDevice *media)
                : Camera::Private(pipe), media_(media), video_(nullptr)
          {
          }

          ~VividCameraData()
          {
                delete video_;
          }

          int init();
          void bufferReady(FrameBuffer *buffer);

          MediaDevice *media_;
          V4L2VideoDevice *video_;
          Stream stream_;
   };

This example pipeline handler handles a single video device and supports a
single stream, represented by the ``VividCameraData`` class members. More
complex pipeline handlers might register cameras composed of several video
devices and sub-devices, or multiple streams per camera that represent the
several components of the image capture pipeline. You should represent all these
components in the ``Camera::Private`` derived class when developing a custom
PipelineHandler.

In our example VividCameraData we implement an ``init()`` function to prepare
the object from our PipelineHandler, however the Camera::Private class does not
specify the interface for initialisation and PipelineHandlers can manage this
based on their own needs. Derived Camera::Private classes are used only by their
respective pipeline handlers.

The Camera::Private class stores the context required for each camera instance
and is usually responsible for opening all Devices used in the capture pipeline.

We can now implement the ``init`` function for our example Pipeline Handler to
create a new V4L2 video device from the media entity, which we can specify using
the `MediaDevice::getEntityByName`_ function from the MediaDevice. As our
example is based upon the simplistic Vivid test device, we only need to open a
single capture device named 'vivid-000-vid-cap' by the device.

.. _MediaDevice::getEntityByName: https://libcamera.org/api-html/classlibcamera_1_1MediaDevice.html#ad5d9279329ef4987ceece2694b33e230

.. code-block:: cpp

   int VividCameraData::init()
   {
          video_ = new V4L2VideoDevice(media_->getEntityByName("vivid-000-vid-cap"));
          if (video_->open())
                return -ENODEV;

          return 0;
   }

The VividCameraData should be created and initialised before we move on to
register a new Camera device so we need to construct and initialise our
VividCameraData after we have identified our device within
PipelineHandlerVivid::match(). The VividCameraData is wrapped by a
std::unique_ptr to help manage the lifetime of the instance.

If the camera data initialization fails, return ``false`` to indicate the
failure to the ``match()`` function and prevent retrying of the pipeline
handler.

.. code-block:: cpp

   std::unique_ptr<VividCameraData> data = std::make_unique<VividCameraData>(this, media);

   if (data->init())
           return false;

Once the camera data has been initialized, the Camera device instances and the
associated streams have to be registered. Create a set of streams for the
camera, which for this device is only one. You create a camera using the static
`Camera::create`_ function, passing the Camera::Private instance, the id of the
camera, and the streams available. Then register the camera with the pipeline
handler and camera manager using `registerCamera`_.

Finally with a successful construction, we return 'true' indicating that the
PipelineHandler successfully matched and constructed a device.

.. _Camera::create: https://libcamera.org/api-html/classlibcamera_1_1Camera.html#a453740e0d2a2f495048ae307a85a2574
.. _registerCamera: https://libcamera.org/api-html/classlibcamera_1_1PipelineHandler.html#adf02a7f1bbd87aca73c0e8d8e0e6c98b

.. code-block:: cpp

   std::set<Stream *> streams{ &data->stream_ };
   std::shared_ptr<Camera> camera = Camera::create(this, data->video_->deviceName(), streams);
   registerCamera(std::move(camera), std::move(data));

   return true;

Our match function should now look like the following:

.. code-block:: cpp

   bool PipelineHandlerVivid::match(DeviceEnumerator *enumerator)
   {
   	DeviceMatch dm("vivid");
   	dm.add("vivid-000-vid-cap");

   	MediaDevice *media = acquireMediaDevice(enumerator, dm);
   	if (!media)
   		return false;

   	std::unique_ptr<VividCameraData> data = std::make_unique<VividCameraData>(this, media);

   	/* Locate and open the capture video node. */
   	if (data->init())
   		return false;

   	/* Create and register the camera. */
   	std::set<Stream *> streams{ &data->stream_ };
   	const std::string &id = data->video_->deviceName();
   	std::shared_ptr<Camera> camera = Camera::create(data.release(), id, streams);
   	registerCamera(std::move(camera));

   	return true;
   }

We will need to use our custom VividCameraData class frequently throughout the
pipeline handler, so we add a private convenience helper to our Pipeline handler
to obtain and cast the custom VividCameraData instance from a Camera::Private
instance.

.. code-block:: cpp

   private:
       VividCameraData *cameraData(Camera *camera)
       {
               return static_cast<VividCameraData *>(camera->_d());
       }

At this point, you need to add the following new includes to provide the Camera
interface, and device interaction interfaces.

.. code-block:: cpp

   #include <libcamera/camera.h>
   #include "libcamera/internal/media_device.h"
   #include "libcamera/internal/v4l2_videodevice.h"

Registering controls and properties
~~~~~~~~~~~~~~~~~~~~~~~~~~~~~~~~~~~

The libcamera `controls framework`_ allows an application to configure the
streams capture parameters on a per-frame basis and is also used to advertise
immutable properties of the ``Camera`` device.

The libcamera controls and properties are defined in YAML form which is
processed to automatically generate documentation and interfaces. Controls are
defined by the src/libcamera/`control_ids_core.yaml`_ file and camera properties
are defined by src/libcamera/`properties_ids_core.yaml`_.

.. _controls framework: https://libcamera.org/api-html/controls_8h.html
.. _control_ids_core.yaml: https://libcamera.org/api-html/control__ids_8h.html
.. _properties_ids_core.yaml: https://libcamera.org/api-html/property__ids_8h.html

Pipeline handlers can optionally register the list of controls an application
can set as well as a list of immutable camera properties. Being both
Camera-specific values, they are represented in the ``Camera::Private`` base
class, which provides two members for this purpose: the
`Camera::Private::controlInfo_`_ and the `Camera::Private::properties_`_ fields.

.. _Camera::Private::controlInfo_: https://libcamera.org/api-html/classlibcamera_1_1Camera_1_1Private.html#ab4e183eb4dabe929d1b2bbbb519b969f
.. _Camera::Private::properties_: https://libcamera.org/api-html/classlibcamera_1_1Camera_1_1Private.html#ad31f12f5ed9c1fbe25750902f4791064

The ``controlInfo_`` field represents a map of ``ControlId`` instances
associated with the limits of valid values supported for the control. More
information can be found in the `ControlInfoMap`_ class documentation.

.. _ControlInfoMap: https://libcamera.org/api-html/classlibcamera_1_1ControlInfoMap.html

Pipeline handlers register controls to expose the tunable device and IPA
parameters to applications. Our example pipeline handler only exposes trivial
controls of the video device, by registering a ``ControlId`` instance with
associated values for each supported V4L2 control but demonstrates the mapping
of V4L2 Controls to libcamera ControlIDs.

Complete the initialization of the ``VividCameraData`` class by adding the
following code to the ``VividCameraData::init()`` function to initialise the
controls. For more complex control configurations, this could of course be
broken out to a separate function, but for now we just initialise the small set
inline in our VividCameraData init:

.. code-block:: cpp

   /* Initialise the supported controls. */
   const ControlInfoMap &controls = video_->controls();
   ControlInfoMap::Map ctrls;

   for (const auto &ctrl : controls) {
           const ControlId *id;
           ControlInfo info;

           switch (ctrl.first->id()) {
           case V4L2_CID_BRIGHTNESS:
                   id = &controls::Brightness;
                   info = ControlInfo{ { -1.0f }, { 1.0f }, { 0.0f } };
                   break;
           case V4L2_CID_CONTRAST:
                   id = &controls::Contrast;
                   info = ControlInfo{ { 0.0f }, { 2.0f }, { 1.0f } };
                   break;
           case V4L2_CID_SATURATION:
                   id = &controls::Saturation;
                   info = ControlInfo{ { 0.0f }, { 2.0f }, { 1.0f } };
                   break;
           default:
                   continue;
           }

           ctrls.emplace(id, info);
   }

   controlInfo_ = ControlInfoMap(std::move(ctrls), controls::controls);

The ``properties_`` field is  a list of ``ControlId`` instances
associated with immutable values, which represent static characteristics that can
be used by applications to identify camera devices in the system. Properties can be
registered by inspecting the values of V4L2 controls from the video devices and
camera sensor (for example to retrieve the position and orientation of a camera)
or to express other immutable characteristics. The example pipeline handler does
not register any property, but examples are available in the libcamera code
base.

.. TODO: Add a property example to the pipeline handler. At least the model.

At this point you need to add the following includes to the top of the file for
handling controls:

.. code-block:: cpp

   #include <libcamera/controls.h>
   #include <libcamera/control_ids.h>

Vendor-specific controls and properties
~~~~~~~~~~~~~~~~~~~~~~~~~~~~~~~~~~~~~~~

Vendor-specific controls and properties must be defined in a separate YAML file
and included in the build by defining the pipeline handler to file mapping in
include/libcamera/meson.build. These YAML files live in the src/libcamera
directory.

For example, adding a Raspberry Pi vendor control file for the PiSP pipeline
handler is done with the following mapping:

.. code-block:: meson

   controls_map = {
      'controls': {
         'draft': 'control_ids_draft.yaml',
         'libcamera': 'control_ids_core.yaml',
         'rpi/pisp': 'control_ids_rpi.yaml',
      },

      'properties': {
         'draft': 'property_ids_draft.yaml',
         'libcamera': 'property_ids_core.yaml',
      }
   }

The pipeline handler named above must match the pipeline handler option string
specified in the meson build configuration.

Vendor-specific controls and properties must contain a `vendor: <vendor_string>`
tag in the YAML file. Every unique vendor tag must define a unique and
non-overlapping range of reserved control IDs in src/libcamera/control_ranges.yaml.

For example, the following block defines a vendor-specific control with the
`rpi` vendor tag:

.. code-block:: yaml

    vendor: rpi
    controls:
      - PispConfigDumpFile:
          type: string
          description: |
            Triggers the Raspberry Pi PiSP pipeline handler to generate a JSON
            formatted dump of the Backend configuration to the filename given by the
            value of the control.

The controls will be generated in the vendor-specific namespace
`libcamera::controls::rpi`. Additionally a `#define
LIBCAMERA_HAS_RPI_VENDOR_CONTROLS` will be available to allow applications to
test for the availability of these controls.

Generating a default configuration
~~~~~~~~~~~~~~~~~~~~~~~~~~~~~~~~~~

Once ``Camera`` devices and the associated ``Streams`` have been registered, an
application can proceed to acquire and configure the camera to prepare it for a
frame capture session.

Applications specify the requested configuration by assigning a
``StreamConfiguration`` instance to each stream they want to enable which
expresses the desired image size and pixel format. The stream configurations are
grouped in a ``CameraConfiguration`` which is inspected by the pipeline handler
and validated to adjust it to a supported configuration. This may involve
adjusting the formats or image sizes or alignments for example to match the
capabilities of the device.

Applications may choose to repeat validation stages, adjusting parameters until
a set of validated StreamConfigurations are returned that is acceptable for the
applications needs. When the pipeline handler receives a valid camera
configuration it can use the image stream configurations to apply settings to
the hardware devices.

This configuration and validation process is managed with another Pipeline
specific class derived from a common base implementation and interface.

To support validation in our example pipeline handler, Create a new class called
``VividCameraConfiguration`` derived from the base `CameraConfiguration`_ class
which we can implement and use within our ``PipelineHandlerVivid`` class.

.. _CameraConfiguration: https://libcamera.org/api-html/classlibcamera_1_1CameraConfiguration.html

The derived ``CameraConfiguration`` class must override the base class
``validate()`` function, where the stream configuration inspection and
adjustment happens.

.. code-block:: cpp

    class VividCameraConfiguration : public CameraConfiguration
    {
    public:
           VividCameraConfiguration();

           Status validate() override;
    };

    VividCameraConfiguration::VividCameraConfiguration()
           : CameraConfiguration()
    {
    }

Applications generate a ``CameraConfiguration`` instance by calling the
`Camera::generateConfiguration()`_ function, which calls into the pipeline
implementation of the overridden `PipelineHandler::generateConfiguration()`_
function.

.. _Camera::generateConfiguration(): https://libcamera.org/api-html/classlibcamera_1_1Camera.html#a25c80eb7fc9b1cf32692ce0c7f09991d
.. _PipelineHandler::generateConfiguration(): https://libcamera.org/api-html/classlibcamera_1_1PipelineHandler.html#a7932e87735695500ce1f8c7ae449b65b

Configurations are generated by receiving a list of ``StreamRole`` instances,
which libcamera uses as predefined ways an application intends to use a camera
(You can read the full list in the `StreamRole API`_ documentation). These are
optional hints on how an application intends to use a stream, and a pipeline
handler should return an ideal configuration for each role that is requested.

.. _StreamRole API: https://libcamera.org/api-html/stream_8h.html#file_a295d1f5e7828d95c0b0aabc0a8baac03

In the pipeline handler ``generateConfiguration`` implementation, remove the
``return nullptr;``, create a new instance of the ``CameraConfiguration``
derived class, and assign it to a base class pointer.

.. code-block:: cpp

   VividCameraData *data = cameraData(camera);
   CameraConfiguration *config = new VividCameraConfiguration();

A ``CameraConfiguration`` is specific to each pipeline, so you can only create
it from the pipeline handler code path. Applications can also generate an empty
configuration and add desired stream configurations manually. Pipelines must
allow for this by returning an empty configuration if no roles are requested.

To support this in our PipelineHandlerVivid, next add the following check in
``generateConfiguration`` after the Cameraconfiguration has been constructed:

.. code-block:: cpp

   if (roles.empty())
           return config;

A production pipeline handler should generate the ``StreamConfiguration`` for
all the appropriate stream roles a camera device supports. For this simpler
example (with only one stream), the pipeline handler always returns the same
configuration, inferred from the underlying V4L2VideoDevice.

How it does this is shown below, but examination of the more full-featured
pipelines for IPU3, RKISP1 and RaspberryPi are recommended to explore more
complex examples.

To generate a ``StreamConfiguration``, you need a list of pixel formats and
frame sizes which are supported as outputs of the stream. You can fetch a map of
the ``V4LPixelFormat`` and ``SizeRange`` supported by the underlying output
device, but the pipeline handler needs to convert this to a
``libcamera::PixelFormat`` type to pass to applications. We do this here using
``std::transform`` to convert the formats and populate a new ``PixelFormat`` map
as shown below.

Continue adding the following code example to our ``generateConfiguration``
implementation.

.. code-block:: cpp

   std::map<V4L2PixelFormat, std::vector<SizeRange>> v4l2Formats =
           data->video_->formats();
   std::map<PixelFormat, std::vector<SizeRange>> deviceFormats;
   std::transform(v4l2Formats.begin(), v4l2Formats.end(),
          std::inserter(deviceFormats, deviceFormats.begin()),
          [&](const decltype(v4l2Formats)::value_type &format) {
              return decltype(deviceFormats)::value_type{
                  format.first.toPixelFormat(),
                  format.second
              };
          });

The `StreamFormats`_ class holds information about the pixel formats and frame
sizes that a stream can support. The class groups size information by the pixel
format, which can produce it.

.. _StreamFormats: https://libcamera.org/api-html/classlibcamera_1_1StreamFormats.html

The code below uses the ``StreamFormats`` class to represent all of the
supported pixel formats, associated with a list of frame sizes. It then
generates a supported StreamConfiguration to model the information an
application can use to configure a single stream.

Continue adding the following code to support this:

.. code-block:: cpp

   StreamFormats formats(deviceFormats);
   StreamConfiguration cfg(formats);

As well as a list of supported StreamFormats, the StreamConfiguration is also
expected to provide an initialised default configuration. This may be arbitrary,
but depending on use case you may wish to select an output that matches the
Sensor output, or prefer a pixelformat which might provide higher performance on
the hardware. The bufferCount represents the number of buffers required to
support functional continuous processing on this stream.

.. code-block:: cpp

   cfg.pixelFormat = formats::BGR888;
   cfg.size = { 1280, 720 };
   cfg.bufferCount = 4;

Finally add each ``StreamConfiguration`` generated to the
``CameraConfiguration``, and ensure that it has been validated before returning
it to the application. With only a single supported stream, this code adds only
a single StreamConfiguration. However a StreamConfiguration should be added for
each supported role in a device that can handle more streams.

Add the following code to complete the implementation of
``generateConfiguration``:

.. code-block:: cpp

   config->addConfiguration(cfg);

   config->validate();

   return config;

To validate a camera configuration, a pipeline handler must implement the
`CameraConfiguration::validate()`_ function in its derived class to inspect all
the stream configuration associated to it, make any adjustments required to make
the configuration valid, and return the validation status.

If changes are made, it marks the configuration as ``Adjusted``, however if the
requested configuration is not supported and cannot be adjusted it shall be
refused and marked as ``Invalid``.

.. _CameraConfiguration::validate(): https://libcamera.org/api-html/classlibcamera_1_1CameraConfiguration.html#a29f8f263384c6149775b6011c7397093

The validation phase makes sure all the platform-specific constraints are
respected by the requested configuration. The most trivial examples being making
sure the requested image formats are supported and the image alignment
restrictions adhered to. The pipeline handler specific implementation of
``validate()`` shall inspect all the configuration parameters received and never
assume they are correct, as applications are free to change the requested stream
parameters after the configuration has been generated.

Again, this example pipeline handler is simpler, look at the more complex
implementations for a realistic example.

Add the following function implementation to your file:

.. code-block:: cpp

   CameraConfiguration::Status VividCameraConfiguration::validate()
   {
           Status status = Valid;

           if (config_.empty())
                  return Invalid;

           if (config_.size() > 1) {
                  config_.resize(1);
                  status = Adjusted;
           }

           StreamConfiguration &cfg = config_[0];

           const std::vector<libcamera::PixelFormat> formats = cfg.formats().pixelformats();
           if (std::find(formats.begin(), formats.end(), cfg.pixelFormat) == formats.end()) {
                  cfg.pixelFormat = cfg.formats().pixelformats()[0];
                  LOG(VIVID, Debug) << "Adjusting format to " << cfg.pixelFormat.toString();
                  status = Adjusted;
           }

           cfg.bufferCount = 4;

           return status;
   }

Now that we are handling the ``PixelFormat`` type, we also need to add
``#include <libcamera/formats.h>`` to the include section before we rebuild the
codebase, and test:

.. code-block:: shell

   ninja -C build
   LIBCAMERA_LOG_LEVELS=Pipeline,VIVID:0 ./build/src/cam/cam -c vivid -I

You should see the following output showing the capabilites of our new pipeline
handler, and showing that our configurations have been generated:

.. code-block:: shell

    Using camera vivid
    0: 1280x720-BGR888
    * Pixelformat: NV21 (320x180)-(3840x2160)/(+0,+0)
    - 320x180
    - 640x360
    - 640x480
    - 1280x720
    - 1920x1080
    - 3840x2160
    * Pixelformat: NV12 (320x180)-(3840x2160)/(+0,+0)
    - 320x180
    - 640x360
    - 640x480
    - 1280x720
    - 1920x1080
    - 3840x2160
    * Pixelformat: BGRA8888 (320x180)-(3840x2160)/(+0,+0)
    - 320x180
    - 640x360
    - 640x480
    - 1280x720
    - 1920x1080
    - 3840x2160
    * Pixelformat: RGBA8888 (320x180)-(3840x2160)/(+0,+0)
    - 320x180
    - 640x360
    - 640x480
    - 1280x720
    - 1920x1080
    - 3840x2160

Configuring a device
~~~~~~~~~~~~~~~~~~~~

With the configuration generated, and optionally modified and re-validated, a
pipeline handler needs a function that allows an application to apply a
configuration to the hardware devices.

The `PipelineHandler::configure()`_ function receives a valid
`CameraConfiguration`_ and applies the settings to hardware devices, using its
parameters to prepare a device for a streaming session with the desired
properties.

.. _PipelineHandler::configure(): https://libcamera.org/api-html/classlibcamera_1_1PipelineHandler.html#a930f2a9cdfb51dfb4b9ca3824e84fc29
.. _CameraConfiguration: https://libcamera.org/api-html/classlibcamera_1_1CameraConfiguration.html

Replace the contents of the stubbed ``PipelineHandlerVivid::configure`` function
with the following to obtain the camera data and stream configuration. This
pipeline handler supports only a single stream, so it directly obtains the first
``StreamConfiguration`` from the camera configuration. A pipeline handler with
multiple streams should inspect each StreamConfiguration and configure the
system accordingly.

.. code-block:: cpp

   VividCameraData *data = cameraData(camera);
   StreamConfiguration &cfg = config->at(0);
   int ret;

The Vivid capture device is a V4L2 video device, so we use a `V4L2DeviceFormat`_
with the fourcc and size attributes to apply directly to the capture device
node. The fourcc attribute is a `V4L2PixelFormat`_ and differs from the
``libcamera::PixelFormat``. Converting the format requires knowledge of the
plane configuration for multiplanar formats, so you must explicitly convert it
using the helper ``V4L2VideoDevice::toV4L2PixelFormat()`` provided by the
V4L2VideoDevice instance that the format will be applied on.

.. _V4L2DeviceFormat: https://libcamera.org/api-html/classlibcamera_1_1V4L2DeviceFormat.html
.. _V4L2PixelFormat: https://libcamera.org/api-html/classlibcamera_1_1V4L2PixelFormat.html

Add the following code beneath the code from above:

.. code-block:: cpp

   V4L2DeviceFormat format = {};
   format.fourcc = data->video_->toV4L2PixelFormat(cfg.pixelFormat);
   format.size = cfg.size;

Set the video device format defined above using the
`V4L2VideoDevice::setFormat()`_ function. You should check if the kernel
driver has adjusted the format, as this shows the pipeline handler has failed to
handle the validation stages correctly, and the configure operation shall also
fail.

.. _V4L2VideoDevice::setFormat(): https://libcamera.org/api-html/classlibcamera_1_1V4L2VideoDevice.html#ad67b47dd9327ce5df43350b80c083cca

Continue the implementation with the following code:

.. code-block:: cpp

   ret = data->video_->setFormat(&format);
   if (ret)
          return ret;

   if (format.size != cfg.size ||
          format.fourcc != data->video_->toV4L2PixelFormat(cfg.pixelFormat))
          return -EINVAL;

Finally, store and set stream-specific data reflecting the state of the stream.
Associate the configuration with the stream by using the
`StreamConfiguration::setStream`_ function, and set the values of individual
stream configuration members as required.

.. _StreamConfiguration::setStream: https://libcamera.org/api-html/structlibcamera_1_1StreamConfiguration.html#a74a0eb44dad1b00112c7c0443ae54a12

.. NOTE: the cfg.setStream() call here associates the stream to the
   StreamConfiguration however that should quite likely be done as part of
   the validation process. TBD

Complete the configure implementation with the following code:

.. code-block:: cpp

   cfg.setStream(&data->stream_);
   cfg.stride = format.planes[0].bpl;

   return 0;

.. TODO: stride SHALL be assigned in validate

Initializing device controls
~~~~~~~~~~~~~~~~~~~~~~~~~~~~

Pipeline handlers can optionally initialize the video devices and camera sensor
controls at system configuration time, to make sure they are defaulted to sane
values. Handling of device controls is again performed using the libcamera
`controls framework`_.

.. _Controls Framework: https://libcamera.org/api-html/controls_8h.html

This section is particularly specific to Vivid as it sets the initial values of
controls to match `Vivid Controls`_ defined by the kernel driver. You won't need
any of the code below for your pipeline handler, but it's included as an example
of how to implement functionality your pipeline handler might need.

.. _Vivid Controls: https://www.kernel.org/doc/html/latest/admin-guide/media/vivid.html#controls

We need to add some definitions at the top of the file for convenience. These
come directly from the kernel sources:

.. code-block:: cpp

   #define VIVID_CID_VIVID_BASE            (0x00f00000 | 0xf000)
   #define VIVID_CID_VIVID_CLASS           (0x00f00000 | 1)
   #define VIVID_CID_TEST_PATTERN          (VIVID_CID_VIVID_BASE  + 0)
   #define VIVID_CID_OSD_TEXT_MODE         (VIVID_CID_VIVID_BASE  + 1)
   #define VIVID_CID_HOR_MOVEMENT          (VIVID_CID_VIVID_BASE  + 2)

We can now use the V4L2 control IDs to prepare a list of controls with the
`ControlList`_ class, and set them using the `ControlList::set()`_ function.

.. _ControlList: https://libcamera.org/api-html/classlibcamera_1_1ControlList.html
.. _ControlList::set(): https://libcamera.org/api-html/classlibcamera_1_1ControlList.html#a74a1a29abff5243e6e37ace8e24eb4ba

In our pipeline ``configure`` function, add the following code after the format
has been set and checked to initialise the ControlList and apply it to the
device:

.. code-block:: cpp

   ControlList controls(data->video_->controls());
   controls.set(VIVID_CID_TEST_PATTERN, 0);
   controls.set(VIVID_CID_OSD_TEXT_MODE, 0);

   controls.set(V4L2_CID_BRIGHTNESS, 128);
   controls.set(V4L2_CID_CONTRAST, 128);
   controls.set(V4L2_CID_SATURATION, 128);

   controls.set(VIVID_CID_HOR_MOVEMENT, 5);

   ret = data->video_->setControls(&controls);
   if (ret) {
          LOG(VIVID, Error) << "Failed to set controls: " << ret;
          return ret < 0 ? ret : -EINVAL;
   }

These controls configure VIVID to use a default test pattern, and enable all
on-screen display text, while configuring sensible brightness, contrast and
saturation values. Use the ``controls.set`` function to set individual controls.

Buffer handling and stream control
~~~~~~~~~~~~~~~~~~~~~~~~~~~~~~~~~~

Once the system has been configured with the requested parameters, it is now
possible for applications to start capturing frames from the ``Camera`` device.

libcamera implements a per-frame request capture model, realized by queueing
``Request`` instances to a ``Camera`` object. Before applications can start
submitting capture requests the capture pipeline needs to be prepared to deliver
frames as soon as they are requested. Memory should be initialized and made
available to the devices which have to be started and ready to produce
images. At the end of a capture session the ``Camera`` device needs to be
stopped, to gracefully clean up any allocated memory and stop the hardware
devices. Pipeline handlers implement two functions for these purposes, the
``start()`` and ``stop()`` functions.

The memory initialization phase that happens at ``start()`` time serves to
configure video devices to be able to use memory buffers exported as dma-buf
file descriptors. From the pipeline handlers perspective the video devices that
provide application facing streams always act as memory importers which use,
in V4L2 terminology, buffers of V4L2_MEMORY_DMABUF memory type.

libcamera also provides an API to allocate and export memory to applications
realized through the `exportFrameBuffers`_ function and the
`FrameBufferAllocator`_ class which will be presented later.

.. _exportFrameBuffers: https://libcamera.org/api-html/classlibcamera_1_1PipelineHandler.html#a6312a69da7129c2ed41f9d9f790adf7c
.. _FrameBufferAllocator: https://libcamera.org/api-html/classlibcamera_1_1FrameBufferAllocator.html

Please refer to the V4L2VideoDevice API documentation, specifically the
`allocateBuffers`_, `importBuffers`_ and `exportBuffers`_ functions for a
detailed description of the video device memory management.

.. _allocateBuffers: https://libcamera.org/api-html/classlibcamera_1_1V4L2VideoDevice.html#a3a1a77e5e6c220ea7878e89485864a1c
.. _importBuffers: https://libcamera.org/api-html/classlibcamera_1_1V4L2VideoDevice.html#a154f5283d16ebd5e15d63e212745cb64
.. _exportBuffers: https://libcamera.org/api-html/classlibcamera_1_1V4L2VideoDevice.html#ae9c0b0a68f350725b63b73a6da5a2ecd

Video memory buffers are represented in libcamera by the `FrameBuffer`_ class.
A ``FrameBuffer`` instance has to be associated to each ``Stream`` which is part
of a capture ``Request``. Pipeline handlers should prepare the capture devices
by importing the dma-buf file descriptors it needs to operate on. This operation
is performed by using the ``V4L2VideoDevice`` API, which provides an
``importBuffers()`` function that prepares the video device accordingly.

.. _FrameBuffer: https://libcamera.org/api-html/classlibcamera_1_1FrameBuffer.html

Implement the pipeline handler ``start()`` function by replacing the stub
version with the following code:

.. code-block:: c++

   VividCameraData *data = cameraData(camera);
   unsigned int count = data->stream_.configuration().bufferCount;

   int ret = data->video_->importBuffers(count);
   if (ret < 0)
         return ret;

   return 0;

During the startup phase pipeline handlers allocate any internal buffer pool
required to transfer data between different components of the image capture
pipeline, for example, between the CSI-2 receiver and the ISP input. The example
pipeline does not require any internal pool, but examples are available in more
complex pipeline handlers in the libcamera code base.

Applications might want to use memory allocated in the video devices instead of
allocating it from other parts of the system. libcamera provides an abstraction
to assist with this task in the `FrameBufferAllocator`_ class. The
``FrameBufferAllocator`` reserves memory for a ``Stream`` in the video device
and exports it as dma-buf file descriptors. From this point on, the allocated
``FrameBuffer`` are associated to ``Stream`` instances in a ``Request`` and then
imported by the pipeline hander in exactly the same fashion as if they were
allocated elsewhere.

.. _FrameBufferAllocator: https://libcamera.org/api-html/classlibcamera_1_1FrameBufferAllocator.html

Pipeline handlers support the ``FrameBufferAllocator`` operations by
implementing the `exportFrameBuffers`_ function, which will allocate memory in
the video device associated with a stream and export it.

.. _exportFrameBuffers: https://libcamera.org/api-html/classlibcamera_1_1PipelineHandler.html#a6312a69da7129c2ed41f9d9f790adf7c

Implement the ``exportFrameBuffers`` stub function with the following code to
handle this:

.. code-block:: cpp

   unsigned int count = stream->configuration().bufferCount;
   VividCameraData *data = cameraData(camera);

   return data->video_->exportBuffers(count, buffers);

Once memory has been properly setup, the video devices can be started, to
prepare for capture operations. Complete the ``start`` function implementation
with the following code:

.. code-block:: cpp

   ret = data->video_->streamOn();
   if (ret < 0) {
          data->video_->releaseBuffers();
          return ret;
   }

   return 0;

The function starts the video device associated with the stream with the
`streamOn`_ function. If the call fails, the error value is propagated to the
caller and the `releaseBuffers`_ function releases any buffers to leave the
device in a consistent state. If your pipeline handler uses any image processing
algorithms, or other devices you should also stop them.

.. _streamOn: https://libcamera.org/api-html/classlibcamera_1_1V4L2VideoDevice.html#a588a5dc9d6f4c54c61136ac43ff9a8cc
.. _releaseBuffers: https://libcamera.org/api-html/classlibcamera_1_1V4L2VideoDevice.html#a191619c152f764e03bc461611f3fcd35

Of course we also need to handle the corresponding actions to stop streaming on
a device, Add the following to the ``stop`` function, to stop the stream with
the `streamOff`_ function and release all buffers.

.. _streamOff: https://libcamera.org/api-html/classlibcamera_1_1V4L2VideoDevice.html#a61998710615bdf7aa25a046c8565ed66

.. code-block:: cpp

   VividCameraData *data = cameraData(camera);
   data->video_->streamOff();
   data->video_->releaseBuffers();

Queuing requests between applications and hardware
~~~~~~~~~~~~~~~~~~~~~~~~~~~~~~~~~~~~~~~~~~~~~~~~~~

libcamera implements a streaming model based on capture requests queued by an
application to the ``Camera`` device. Each request contains at least one
``Stream`` instance with an associated ``FrameBuffer`` object.

When an application sends a capture request, the pipeline handler identifies
which video devices have to be provided with buffers to generate a frame from
the enabled streams.

This example pipeline handler identifies the buffer using the `findBuffer`_
helper from the only supported stream and queues it to the capture device
directly with the `queueBuffer`_ function provided by the V4L2VideoDevice.

.. _findBuffer: https://libcamera.org/api-html/classlibcamera_1_1Request.html#ac66050aeb9b92c64218945158559c4d4
.. _queueBuffer: https://libcamera.org/api-html/classlibcamera_1_1V4L2VideoDevice.html#a594cd594686a8c1cf9ae8dba0b2a8a75

Replace the stubbed contents of ``queueRequestDevice`` with the following:

.. code-block:: cpp

   VividCameraData *data = cameraData(camera);
   FrameBuffer *buffer = request->findBuffer(&data->stream_);
   if (!buffer) {
          LOG(VIVID, Error)
                  << "Attempt to queue request with invalid stream";

          return -ENOENT;
   }

   int ret = data->video_->queueBuffer(buffer);
   if (ret < 0)
          return ret;

   return 0;

Processing controls
~~~~~~~~~~~~~~~~~~~

Capture requests not only contain streams and memory buffers, but can
optionally contain a list of controls the application has set to modify the
streaming parameters.

Applications can set controls registered by the pipeline handler in the
initialization phase, as explained in the `Registering controls and properties`_
section.

Implement a ``processControls`` function above the ``queueRequestDevice``
function to loop through the control list received with each request, and
inspect the control values. Controls may need to be converted between the
libcamera control range definitions and their corresponding values on the device
before being set.

.. code-block:: cpp

   int PipelineHandlerVivid::processControls(VividCameraData *data, Request *request)
   {
          ControlList controls(data->video_->controls());

          for (auto it : request->controls()) {
                 unsigned int id = it.first;
                 unsigned int offset;
                 uint32_t cid;

                 if (id == controls::Brightness) {
                        cid = V4L2_CID_BRIGHTNESS;
                        offset = 128;
                 } else if (id == controls::Contrast) {
                        cid = V4L2_CID_CONTRAST;
                        offset = 0;
                 } else if (id == controls::Saturation) {
                        cid = V4L2_CID_SATURATION;
                        offset = 0;
                 } else {
                        continue;
                 }

                 int32_t value = std::lround(it.second.get<float>() * 128 + offset);
                 controls.set(cid, std::clamp(value, 0, 255));
          }

          for (const auto &ctrl : controls)
                 LOG(VIVID, Debug)
                        << "Setting control " << utils::hex(ctrl.first)
                        << " to " << ctrl.second.toString();

          int ret = data->video_->setControls(&controls);
          if (ret) {
                 LOG(VIVID, Error) << "Failed to set controls: " << ret;
                 return ret < 0 ? ret : -EINVAL;
          }

          return ret;
   }

Declare the function prototype for the ``processControls`` function within the
private ``PipelineHandlerVivid`` class members, as it is only used internally as
a helper when processing Requests.

.. code-block:: cpp

   private:
        int processControls(VividCameraData *data, Request *request);

A pipeline handler is responsible for applying controls provided in a Request to
the relevant hardware devices. This could be directly on the capture device, or
where appropriate by setting controls on V4L2Subdevices directly. Each pipeline
handler is responsible for understanding the correct procedure for applying
controls to the device they support.

This example pipeline handler applies controls during the `queueRequestDevice`_
function for each request, and applies them to the capture device through the
capture node.

.. _queueRequestDevice: https://libcamera.org/api-html/classlibcamera_1_1PipelineHandler.html#a106914cca210640c9da9ee1f0419e83c

In the ``queueRequestDevice`` function, replace the following:

.. code-block:: cpp

   int ret = data->video_->queueBuffer(buffer);
   if (ret < 0)
        return ret;

With the following code:

.. code-block:: cpp

   int ret = processControls(data, request);
   if (ret < 0)
        return ret;

   ret = data->video_->queueBuffer(buffer);
   if (ret < 0)
        return ret;

We also need to add the following include directive to support the control
value translation operations:

.. code-block:: cpp

   #include <cmath>

Frame completion and event handling
~~~~~~~~~~~~~~~~~~~~~~~~~~~~~~~~~~~

libcamera implements a signals and slots mechanism (similar to `Qt Signals and
Slots`_) to connect event sources with callbacks to handle them.

As a general summary, a ``Slot`` can be connected to a ``Signal``, which when
emitted triggers the execution of the connected slots.  A detailed description
of the libcamera implementation is available in the `libcamera Signal and Slot`_
classes documentation.

.. _Qt Signals and Slots: https://doc.qt.io/qt-6/signalsandslots.html
.. _libcamera Signal and Slot: https://libcamera.org/api-html/classlibcamera_1_1Signal.html#details

In order to notify applications about the availability of new frames and data,
the ``Camera`` device exposes two ``Signals`` to which applications can connect
to be notified of frame completion events. The ``bufferComplete`` signal serves
to report to applications the completion event of a single ``Stream`` part of a
``Request``, while the ``requestComplete`` signal notifies the completion of all
the ``Streams`` and data submitted as part of a request. This mechanism allows
implementation of partial request completion, which allows an application to
inspect completed buffers associated with the single streams without waiting for
all of them to be ready.

The ``bufferComplete`` and ``requestComplete`` signals are emitted by the
``Camera`` device upon notifications received from the pipeline handler, which
tracks the buffers and request completion status.

The single buffer completion notification is implemented by pipeline handlers by
`connecting`_ the ``bufferReady`` signal of the capture devices they have queued
buffers to, to a member function slot that handles processing of the completed
frames. When a buffer is ready, the pipeline handler must propagate the
completion of that buffer to the Camera by using the PipelineHandler base class
``completeBuffer`` function. When all of the buffers referenced by a ``Request``
have been completed, the pipeline handler must again notify the ``Camera`` using
the PipelineHandler base class ``completeRequest`` function. The PipelineHandler
class implementation makes sure the request completion notifications are
delivered to applications in the same order as they have been submitted.

.. _connecting: https://libcamera.org/api-html/classlibcamera_1_1Signal.html#aa04db72d5b3091ffbb4920565aeed382

Returning to the ``int VividCameraData::init()`` function, add the following
above the closing ``return 0;`` to connect the pipeline handler ``bufferReady``
function to the V4L2 device buffer signal.

.. code-block:: cpp

   video_->bufferReady.connect(this, &VividCameraData::bufferReady);

Create the matching ``VividCameraData::bufferReady`` function after your
VividCameradata::init() implementation.

The ``bufferReady`` function obtains the request from the buffer using the
``request`` function, and notifies the ``Camera`` that the buffer and
request are completed. In this simpler pipeline handler, there is only one
stream, so it completes the request immediately. You can find a more complex
example of event handling with supporting multiple streams in the libcamera
code-base.

.. TODO: Add link

.. code-block:: cpp

   void VividCameraData::bufferReady(FrameBuffer *buffer)
   {
          Request *request = buffer->request();

          pipe_->completeBuffer(request, buffer);
          pipe_->completeRequest(request);
   }

Testing a pipeline handler
~~~~~~~~~~~~~~~~~~~~~~~~~~

Once you've built the pipeline handler, we can rebuild the code base, and test
capture through the pipeline through both of the cam and qcam utilities.

.. code-block:: shell

   ninja -C build
   ./build/src/cam/cam -c vivid -C5

To test that the pipeline handler can detect a device, and capture input.

Running the command above outputs (a lot of) information about pixel formats,
and then starts capturing frame data, and should provide an output such as the
following:

.. code-block:: none

   user@dev:/home/libcamera$ ./build/src/cam/cam -c vivid -C5
   [42:34:08.573066847] [186470]  INFO IPAManager ipa_manager.cpp:136 libcamera is not installed. Adding '/home/libcamera/build/src/ipa' to the IPA search path
   [42:34:08.575908115] [186470]  INFO Camera camera_manager.cpp:287 libcamera v0.0.11+876-7b27d262
   [42:34:08.610334268] [186471]  INFO IPAProxy ipa_proxy.cpp:122 libcamera is not installed. Loading IPA configuration from '/home/libcamera/src/ipa/vimc/data'
   Using camera vivid
   [42:34:08.618462130] [186470]  WARN V4L2 v4l2_pixelformat.cpp:176 Unsupported V4L2 pixel format Y10
   ... <remaining Unsupported V4L2 pixel format warnings can be ignored>
   [42:34:08.619901297] [186470]  INFO Camera camera.cpp:793 configuring streams: (0) 1280x720-BGR888
   Capture 5 frames
   fps: 0.00 stream0 seq: 000000 bytesused: 2764800
   fps: 4.98 stream0 seq: 000001 bytesused: 2764800
   fps: 5.00 stream0 seq: 000002 bytesused: 2764800
   fps: 5.03 stream0 seq: 000003 bytesused: 2764800
   fps: 5.03 stream0 seq: 000004 bytesused: 2764800

This demonstrates that the pipeline handler is successfully capturing frames,
but it is helpful to see the visual output and validate the images are being
processed correctly. The libcamera project also implements a Qt based
application which will render the frames in a window for visual inspection:

.. code-block:: shell

   ./build/src/qcam/qcam -c vivid

.. TODO: Running qcam with the vivid pipeline handler appears to have a bug and
         no visual frames are seen. However disabling zero-copy on qcam renders
         them successfully.

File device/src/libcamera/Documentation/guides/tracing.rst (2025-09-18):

.. SPDX-License-Identifier: CC-BY-SA-4.0

.. include:: ../documentation-contents.rst

Tracing Guide
=============

Guide to tracing in libcamera.

Profiling vs Tracing
--------------------

Tracing is recording timestamps at specific locations. libcamera provides a
tracing facility. This guide shows how to use this tracing facility.

Tracing should not be confused with profiling, which samples execution
at periodic points in time. This can be done with other tools such as
callgrind, perf, gprof, etc., without modification to the application,
and is out of scope for this guide.

Compiling
---------

To compile libcamera with tracing support, it must be enabled through the
meson ``tracing`` option. It depends on the lttng-ust library (available in the
``liblttng-ust-dev`` package for Debian-based distributions).
By default the tracing option in meson is set to ``auto``, so if
liblttng is detected, it will be enabled by default. Conversely, if the option
is set to disabled, then libcamera will be compiled without tracing support.

Defining tracepoints
--------------------

libcamera already contains a set of tracepoints. To define additional
tracepoints, create a file
``include/libcamera/internal/tracepoints/{file}.tp``, where ``file`` is a
reasonable name related to the category of tracepoints that you wish to
define. For example, the tracepoints file for the Request object is called
``request.tp``. An entry for this file must be added in
``include/libcamera/internal/tracepoints/meson.build``.

In this tracepoints file, define your tracepoints `as mandated by lttng
<https://lttng.org/man/3/lttng-ust>`_. The header boilerplate must *not* be
included (as it will conflict with the rest of our infrastructure), and
only the tracepoint definitions (with the ``TRACEPOINT_*`` macros) should be
included.

All tracepoint providers shall be ``libcamera``. According to lttng, the
tracepoint provider should be per-project; this is the rationale for this
decision. To group tracepoint events, we recommend using
``{class_name}_{tracepoint_name}``, for example, ``request_construct`` for a
tracepoint for the constructor of the Request class.

Tracepoint arguments may take C++ objects pointers, in which case the usual
C++ namespacing rules apply. The header that contains the necessary class
definitions must be included at the top of the tracepoint provider file.

Note: the final parameter in ``TP_ARGS`` *must not* have a trailing comma, and
the parameters to ``TP_FIELDS`` are *space-separated*. Not following these will
cause compilation errors.

Using tracepoints (in libcamera)
--------------------------------

To use tracepoints in libcamera, first the header needs to be included:

``#include "libcamera/internal/tracepoints.h"``

Then to use the tracepoint:

``LIBCAMERA_TRACEPOINT({tracepoint_event}, args...)``

This macro must be used, as opposed to lttng's macros directly, because
lttng is an optional dependency of libcamera, so the code must compile and run
even when lttng is not present or when tracing is disabled.

The tracepoint provider name, as declared in the tracepoint definition, is not
included in the parameters of the tracepoint.

There are also two special tracepoints available for tracing IPA calls:

``LIBCAMERA_TRACEPOINT_IPA_BEGIN({pipeline_name}, {ipa_function})``

``LIBCAMERA_TRACEPOINT_IPA_END({pipeline_name}, {ipa_function})``

These shall be placed where an IPA function is called from the pipeline handler,
and when the pipeline handler receives the corresponding response from the IPA,
respectively. These are the tracepoints that our sample analysis script
(see "Analyzing a trace") scans for when computing statistics on IPA call time.

Using tracepoints (from an application)
---------------------------------------

As applications are not part of libcamera, but rather users of libcamera,
applications should seek their own tracing mechanisms. For ease of tracing
the application alongside tracing libcamera, it is recommended to also
`use lttng <https://lttng.org/docs/#doc-tracing-your-own-user-application>`_.

Using tracepoints (from closed-source IPA)
------------------------------------------

Similar to applications, closed-source IPAs can simply use lttng on their own,
or any other tracing mechanism if desired.

Collecting a trace
------------------

A trace can be collected fairly simply from lttng:

.. code-block:: bash

   lttng create $SESSION_NAME
   lttng enable-event -u libcamera:\*
   lttng start
   # run libcamera application
   lttng stop
   lttng view
   lttng destroy $SESSION_NAME

See the `lttng documentation <https://lttng.org/docs/>`_ for further details.

The location of the trace file is printed when running
``lttng create $SESSION_NAME``. After destroying the session, it can still be
viewed by: ``lttng view -t $PATH_TO_TRACE``, where ``$PATH_TO_TRACE`` is the
path that was printed when the session was created. This is the same path that
is used when analyzing traces programatically, as described in the next section.

Analyzing a trace
-----------------

As mentioned above, while an lttng tracing session exists and the trace is not
running, the trace output can be viewed as text by ``lttng view``.

The trace log can also be viewed as text using babeltrace2.  See the
`lttng trace analysis documentation
<https://lttng.org/docs/#doc-viewing-and-analyzing-your-traces-bt>`_
for further details.

babeltrace2 also has a C API and python bindings that can be used to process
traces. See the
`lttng python bindings documentation <https://babeltrace.org/docs/v2.0/python/bt2/>`_
and the
`lttng C API documentation <https://babeltrace.org/docs/v2.0/libbabeltrace2/>`_
for more details.

As an example, there is a script ``utils/tracepoints/analyze-ipa-trace.py``
that gathers statistics for the time taken for an IPA function call, by
measuring the time difference between pairs of events
``libcamera:ipa_call_start`` and ``libcamera:ipa_call_finish``.

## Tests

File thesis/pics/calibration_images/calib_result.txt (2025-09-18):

# FAST-LIVO2 calibration format
cam_model: Pinhole
cam_width: 800
cam_height: 600
scale: 1.0
cam_fx: 1215.32
cam_fy: 1214.73
cam_cx: 1047.87
cam_cy: 745.068
cam_d0: -0.335748
cam_d1: 0.109969
cam_d2: 0.000157303
cam_d3: 0.000544931

Rcl: [  0.407888,  -0.912836,  -0.018910,
        0.182500,   0.061219,   0.981298,
       -0.894607,  -0.403711,   0.191564]
Pcl: [ -1.994484,  -1.230631,   3.956750]

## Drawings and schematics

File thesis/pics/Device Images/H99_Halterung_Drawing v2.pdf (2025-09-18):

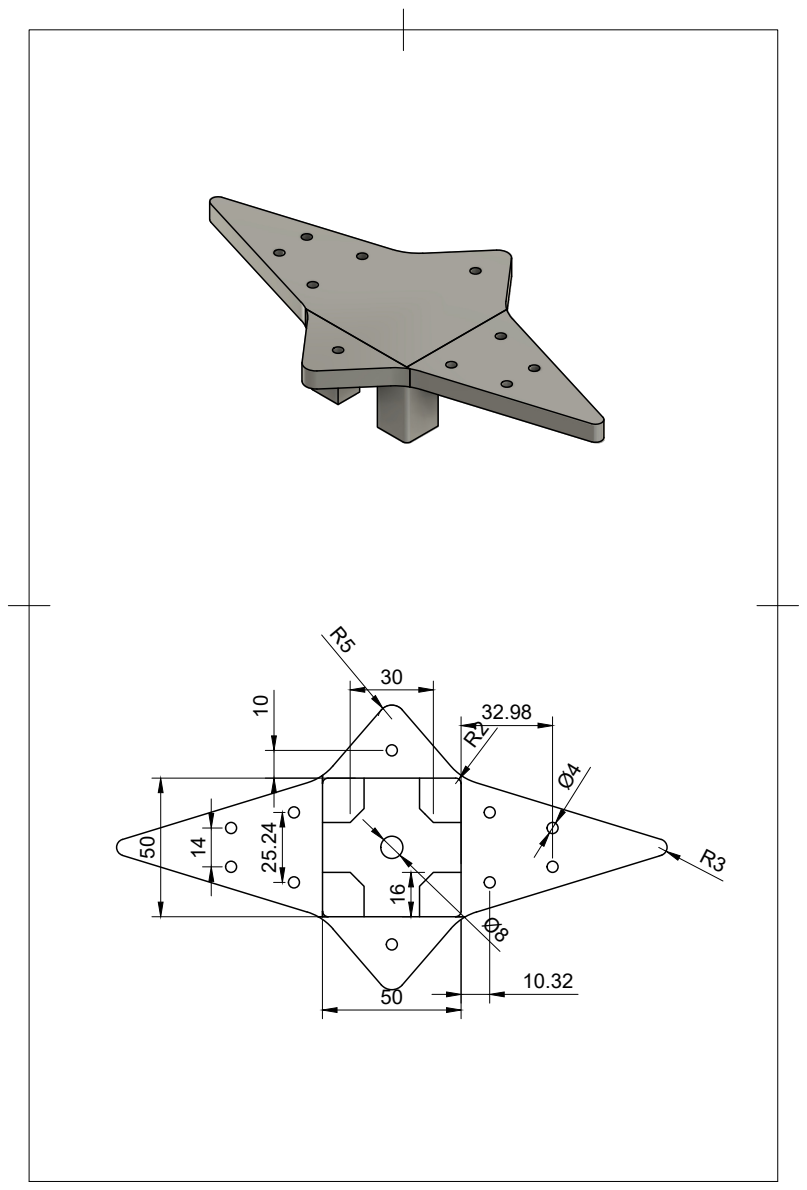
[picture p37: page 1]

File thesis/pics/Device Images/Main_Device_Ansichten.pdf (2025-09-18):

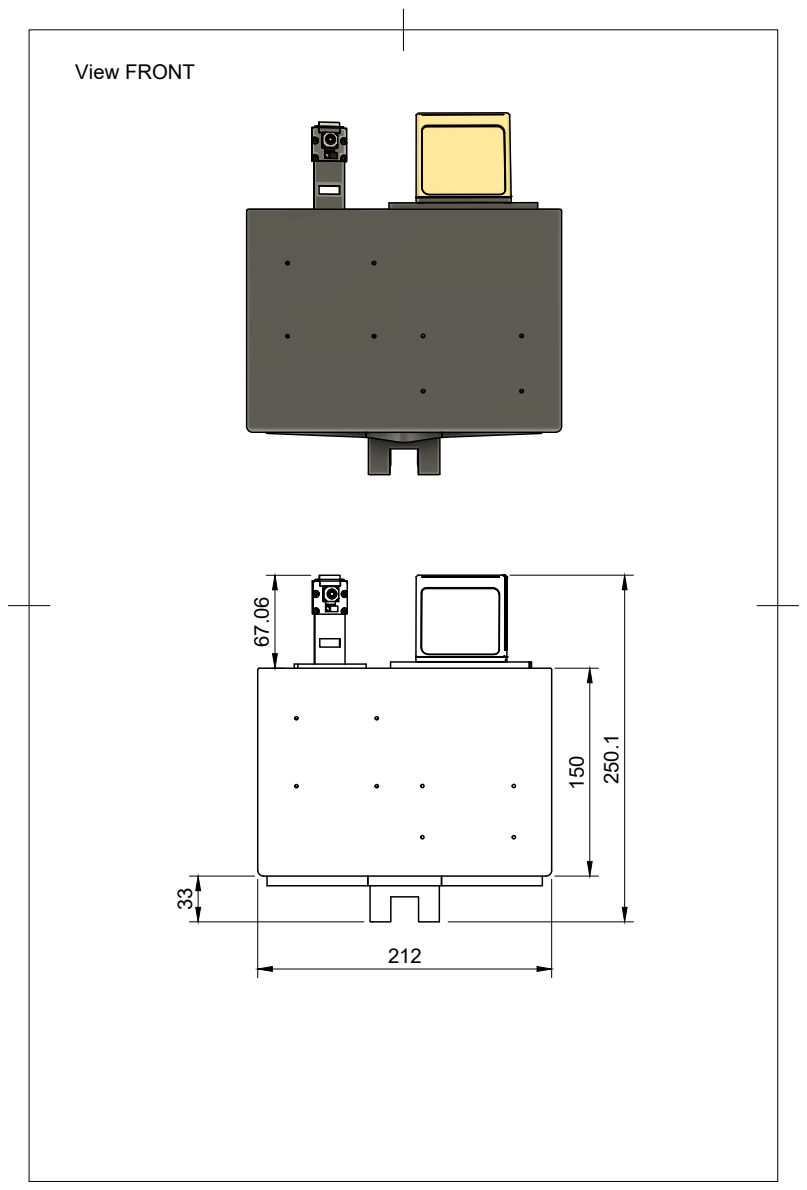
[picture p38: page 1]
View FRONT

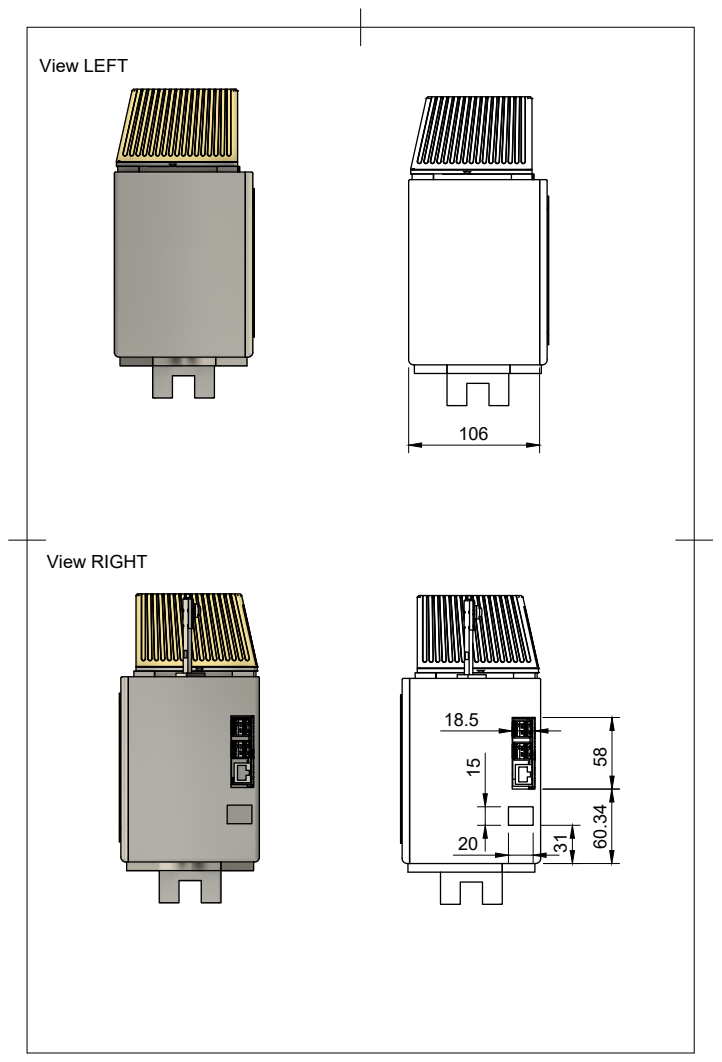
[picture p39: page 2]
View LEFT; View RIGHT

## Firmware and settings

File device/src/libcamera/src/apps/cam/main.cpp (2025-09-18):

/* SPDX-License-Identifier: GPL-2.0-or-later */
/*
 * Copyright (C) 2019, Google Inc.
 *
 * cam - The libcamera swiss army knife
 */

#include "main.h"

#include <atomic>
#include <iomanip>
#include <iostream>
#include <signal.h>
#include <string.h>

#include <libcamera/libcamera.h>
#include <libcamera/property_ids.h>

#include "../common/event_loop.h"
#include "../common/options.h"
#include "../common/stream_options.h"

#include "camera_session.h"

using namespace libcamera;

class CamApp
{
public:
	CamApp();

	static CamApp *instance();

	int init(int argc, char **argv);
	void cleanup();

	int exec();
	void quit();

private:
	void cameraAdded(std::shared_ptr<Camera> cam);
	void cameraRemoved(std::shared_ptr<Camera> cam);
	void captureDone();
	int parseOptions(int argc, char *argv[]);
	int run();

	static std::string cameraName(const Camera *camera);

	static CamApp *app_;
	OptionsParser::Options options_;

	std::unique_ptr<CameraManager> cm_;

	std::atomic_uint loopUsers_;
	EventLoop loop_;
};

CamApp *CamApp::app_ = nullptr;

CamApp::CamApp()
	: loopUsers_(0)
{
	CamApp::app_ = this;
}

CamApp *CamApp::instance()
{
	return CamApp::app_;
}

int CamApp::init(int argc, char **argv)
{
	int ret;

	ret = parseOptions(argc, argv);
	if (ret < 0)
		return ret;

	cm_ = std::make_unique<CameraManager>();

	ret = cm_->start();
	if (ret) {
		std::cout << "Failed to start camera manager: "
			  << strerror(-ret) << std::endl;
		return ret;
	}

	return 0;
}

void CamApp::cleanup()
{
	cm_->stop();
}

int CamApp::exec()
{
	int ret;

	ret = run();
	cleanup();

	return ret;
}

void CamApp::quit()
{
	loop_.exit();
}

int CamApp::parseOptions(int argc, char *argv[])
{
	StreamKeyValueParser streamKeyValue;

	OptionsParser parser;
	parser.addOption(OptCamera, OptionString,
			 "Specify which camera to operate on, by id or by index", "camera",
			 ArgumentRequired, "camera", true);
	parser.addOption(OptHelp, OptionNone, "Display this help message",
			 "help");
	parser.addOption(OptInfo, OptionNone,
			 "Display information about stream(s)", "info");
	parser.addOption(OptList, OptionNone, "List all cameras", "list");
	parser.addOption(OptListControls, OptionNone, "List cameras controls",
			 "list-controls");
	parser.addOption(OptListProperties, OptionNone, "List cameras properties",
			 "list-properties");
	parser.addOption(OptMonitor, OptionNone,
			 "Monitor for hotplug and unplug camera events",
			 "monitor");

	/* Sub-options of OptCamera: */
	parser.addOption(OptCapture, OptionInteger,
			 "Capture until interrupted by user or until <count> frames captured",
			 "capture", ArgumentOptional, "count", false,
			 OptCamera);

	parser.addOption(OptOrientation, OptionString,
			 "Desired image orientation (rot0, rot180, mirror, flip)",
			 "orientation", ArgumentRequired, "orientation", false,
			 OptCamera);
#ifdef HAVE_KMS
	parser.addOption(OptDisplay, OptionString,
			 "Display viewfinder through DRM/KMS on specified connector",
			 "display", ArgumentOptional, "connector", false,
			 OptCamera);
#endif
	parser.addOption(OptFile, OptionString,
			 "Write captured frames to disk\n"
			 "If the file name ends with a '/', it sets the directory in which\n"
			 "to write files, using the default file name. Otherwise it sets the\n"
			 "full file path and name. The first '#' character in the file name\n"
			 "is expanded to the camera index, stream name and frame sequence number.\n"
#ifdef HAVE_TIFF
			 "If the file name ends with '.dng', then the frame will be written to\n"
			 "the output file(s) in DNG format.\n"
#endif
			 "If the file name ends with '.ppm', then the frame will be written to\n"
			 "the output file(s) in PPM format.\n"
			 "The default file name is 'frame-#.bin'.",
			 "file", ArgumentOptional, "filename", false,
			 OptCamera);
#ifdef HAVE_SDL
	parser.addOption(OptSDL, OptionNone, "Display viewfinder through SDL",
			 "sdl", ArgumentNone, "", false, OptCamera);
#endif
	parser.addOption(OptStream, &streamKeyValue,
			 "Set configuration of a camera stream", "stream", true,
			 OptCamera);
	parser.addOption(OptStrictFormats, OptionNone,
			 "Do not allow requested stream format(s) to be adjusted",
			 "strict-formats", ArgumentNone, nullptr, false,
			 OptCamera);
	parser.addOption(OptMetadata, OptionNone,
			 "Print the metadata for completed requests",
			 "metadata", ArgumentNone, nullptr, false,
			 OptCamera);
	parser.addOption(OptCaptureScript, OptionString,
			 "Load a capture session configuration script from a file",
			 "script", ArgumentRequired, "script", false,
			 OptCamera);

	options_ = parser.parse(argc, argv);
	if (!options_.valid())
		return -EINVAL;

	if (options_.empty() || options_.isSet(OptHelp)) {
		parser.usage();
		return options_.empty() ? -EINVAL : -EINTR;
	}

	return 0;
}

void CamApp::cameraAdded(std::shared_ptr<Camera> cam)
{
	std::cout << "Camera Added: " << cam->id() << std::endl;
}

void CamApp::cameraRemoved(std::shared_ptr<Camera> cam)
{
	std::cout << "Camera Removed: " << cam->id() << std::endl;
}

void CamApp::captureDone()
{
	if (--loopUsers_ == 0)
		EventLoop::instance()->exit(0);
}

int CamApp::run()
{
	int ret;

	/* 1. List all cameras. */
	if (options_.isSet(OptList)) {
		std::cout << "Available cameras:" << std::endl;

		unsigned int index = 1;
		for (const std::shared_ptr<Camera> &cam : cm_->cameras()) {
			std::cout << index << ": " << cameraName(cam.get()) << std::endl;
			index++;
		}
	}

	/* 2. Create the camera sessions. */
	std::vector<std::unique_ptr<CameraSession>> sessions;

	if (options_.isSet(OptCamera)) {
		unsigned int index = 0;

		for (const OptionValue &camera : options_[OptCamera].toArray()) {
			std::unique_ptr<CameraSession> session =
				std::make_unique<CameraSession>(cm_.get(),
								camera.toString(),
								index,
								camera.children());
			if (!session->isValid()) {
				std::cout << "Failed to create camera session" << std::endl;
				return -EINVAL;
			}

			std::cout << "Using camera " << session->camera()->id()
				  << " as cam" << index << std::endl;

			session->captureDone.connect(this, &CamApp::captureDone);

			sessions.push_back(std::move(session));
			index++;
		}
	}

	/* 3. Print camera information. */
	if (options_.isSet(OptListControls) ||
	    options_.isSet(OptListProperties) ||
	    options_.isSet(OptInfo)) {
		for (const auto &session : sessions) {
			if (options_.isSet(OptListControls))
				session->listControls();
			if (options_.isSet(OptListProperties))
				session->listProperties();
			if (options_.isSet(OptInfo))
				session->infoConfiguration();
		}
	}

	/* 4. Start capture. */
	for (const auto &session : sessions) {
		if (!session->options().isSet(OptCapture))
			continue;

		ret = session->start();
		if (ret) {
			std::cout << "Failed to start camera session" << std::endl;
			return ret;
		}

		loopUsers_++;
	}

	/* 5. Enable hotplug monitoring. */
	if (options_.isSet(OptMonitor)) {
		std::cout << "Monitoring new hotplug and unplug events" << std::endl;
		std::cout << "Press Ctrl-C to interrupt" << std::endl;

		cm_->cameraAdded.connect(this, &CamApp::cameraAdded);
		cm_->cameraRemoved.connect(this, &CamApp::cameraRemoved);

		loopUsers_++;
	}

	if (loopUsers_)
		loop_.exec();

	/* 6. Stop capture. */
	for (const auto &session : sessions) {
		if (!session->options().isSet(OptCapture))
			continue;

		session->stop();
	}

	return 0;
}

std::string CamApp::cameraName(const Camera *camera)
{
	const ControlList &props = camera->properties();
	bool addModel = true;
	std::string name;

	/*
	 * Construct the name from the camera location, model and ID. The model
	 * is only used if the location isn't present or is set to External.
	 */
	const auto &location = props.get(properties::Location);
	if (location) {
		switch (*location) {
		case properties::CameraLocationFront:
			addModel = false;
			name = "Internal front camera ";
			break;
		case properties::CameraLocationBack:
			addModel = false;
			name = "Internal back camera ";
			break;
		case properties::CameraLocationExternal:
			name = "External camera ";
			break;
		}
	}

	if (addModel) {
		/*
		 * If the camera location is not availble use the camera model
		 * to build the camera name.
		 */
		const auto &model = props.get(properties::Model);
		if (model)
			name = "'" + *model + "' ";
	}

	name += "(" + camera->id() + ")";

	return name;
}

namespace {

void signalHandler([[maybe_unused]] int signal)
{
	std::cout << "Exiting" << std::endl;
	CamApp::instance()->quit();
}

} /* namespace */

int main(int argc, char **argv)
{
	CamApp app;
	int ret;

	ret = app.init(argc, argv);
	if (ret)
		return ret == -EINTR ? 0 : EXIT_FAILURE;

	struct sigaction sa = {};
	sa.sa_handler = &signalHandler;
	sigaction(SIGINT, &sa, nullptr);

	if (app.exec())
		return EXIT_FAILURE;

	return 0;
}
